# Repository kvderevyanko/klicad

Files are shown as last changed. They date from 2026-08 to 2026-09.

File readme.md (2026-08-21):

# Несущая плата ESP32 + E220, Rev.1

Текущая Rev.1 — **кандидат для предсерийной проверки**, а не производственный выпуск. Электрическая схема и трассировка завершены: 37 посадочных мест, 200 дорожек, 58 переходных отверстий, четыре медные зоны, два слоя, контур 145 × 90 мм; ERC, native DRC, соответствие схемы/платы и контракт платы проходят без ошибок и без неподключённых объектов.

## Действующая архитектура питания

\`BAT_PLUS → F1 → BAT_FUSED → J8.1 → внешний выключатель → J8.2 → BAT_SW → Q1 → BUCK_IN → TPS62133 → 5V_SYS\`.

\`D3 SMBJ10CA\` подключён между \`BAT_FUSED\` и GND. У Q1 \`DMP3130LQ-7\`: 1=\`Q1_GATE\`, 2=\`BUCK_IN\`, 3=\`BAT_SW\`.

\`5V_SYS → JP1 → VIN ESP32 DevKit\`. Обычный режим: выключатель включён, JP1 замкнут. Для сервисного USB с изоляцией: выключатель выключен, JP1 разомкнут при необходимости; JP1 не является автоматической изоляцией доменов.

\`5V_SYS → U4 TLV1117LV33 → AUX_3V3 → OLED\`. OLED питается только от \`AUX_3V3\`; \`DEVKIT_3V3\` не является питанием аксессуаров.

## Узлы и сборка

- J1/J2 — заводски устанавливаемые розетки ESP32; сам ESP32 DevKit устанавливает пользователь.
- J3 — заводски устанавливаемая розетка Samtec для одного пользовательского E220-400T22D или E220-900T22D; антенна обязана соответствовать диапазону модуля.
- J5 — заводски устанавливаемая розетка OLED; механическая совместимость конкретного OLED подтверждается на первом образце.
- J6 \`BUTTONS\` и J9 \`RGB OUT\` — пользовательские DNP-интерфейсы.
- D2, J7 и TP6…TP10 отсутствуют. TP1…TP5 — сохранённые металлизированные пробные отверстия без устанавливаемого компонента.

Электрические соединения завершены. Крепёж и разгрузка аккумуляторного кабеля сознательно отложены до корпуса/жгута или Rev.2. Генерация Gerber, сверловки, производственного BOM и CPL разрешается только отдельной задачей после предсерийного ревью.

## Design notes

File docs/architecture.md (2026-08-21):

# Архитектура Rev.1

## Питание

\`\`\`
BAT_PLUS -> F1 -> BAT_FUSED -> J8 / внешний выключатель -> BAT_SW
                                                       -> Q1 -> BUCK_IN
                                                       -> TPS62133 -> 5V_SYS
BAT_FUSED -> D3 SMBJ10CA -> GND
5V_SYS -> JP1 -> VIN ESP32 DevKit
5V_SYS -> U4 TLV1117LV33 -> AUX_3V3 -> OLED
\`\`\`

Q1 — P-MOS DMP3130LQ-7: 1=gate \`Q1_GATE\`, 2=source \`BUCK_IN\`, 3=drain \`BAT_SW\`. Предыдущее описание drain=\`BAT_FUSED\` относится к состоянию до вставки J8 и недействительно.

J8 — внешний механический выключатель, а не источник питания. Для обычной работы он включён и JP1 замкнут. Для USB-сервиса с требуемой изоляцией выключатель выключают и JP1 размыкают; JP1 не даёт автоматической изоляции всех GPIO.

## Модули и интерфейсы

- ESP32 DevKit устанавливается пользователем в заводские розетки J1/J2. Его USB-C должен быть доступен, а антенна обращена к свободной зоне запрета меди.
- E220 устанавливается пользователем в заводскую розетку J3. Сигналы M0/M1/AUX/RXD/TXD, питание и земля полностью подключены. SMA и антенна остаются доступными; антенна 400/900 МГц выбирается по варианту E220.
- OLED устанавливается пользователем в заводскую розетку J5: GND, AUX_3V3, SCL GPIO22, SDA GPIO21. Окончательная механика конкретного дисплея — проверка первого образца.
- J6 — DNP-интерфейс пяти пассивных кнопок: GND, GPIO13, GPIO14, GPIO18, GPIO19, GPIO23.
- J9 — DNP-интерфейс RGB OUT: 5V_SYS, WS2812_DATA_5V, GND; не более трёх внешних пикселей.

U3 SN74AHCT1G125DBVR преобразует GPIO4/\`WS2812_DATA_3V3\` в \`WS2812_DATA_5V\`. Его утверждённый TI DBV0005A footprint имеет верную распиновку: 1=OE/GND, 2=A, 3=GND, 4=Y, 5=VCC.

## Земля, возвраты и ограничения

Два связанных B.Cu-полигона GND вместе с локальной F.Cu-заливкой преобразователя образуют завершённую систему возврата. Шесть заземляющих выводов/EP U1 соединены с глобальной GND через два переходных отверстия; местный возврат E220 также соединён с глобальной землёй. OLED трассирован на F.Cu без фрагментации B.Cu GND.

Запретная область антенны ESP32 (X=104,7…142,7 мм, Y=52,0…90,0 мм) свободна от меди, дорожек, переходных отверстий и новых посадочных мест, кроме документированных границ розеток. Контур платы 145 × 90 мм, слоёв меди два.

## Статус

Все обязательные электрические трассы Rev.1 завершены. D2, J7 и TP6…TP10 отсутствуют; TP1…TP5 сохранены как пробные металлизированные отверстия. Крепёж платы и разгрузка аккумуляторного кабеля — ответственность корпуса/жгута в Rev.1 и отложены до Rev.2 или механической первой статьи.

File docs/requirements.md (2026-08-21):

# Требования к плате наземного приёмника ESP32 + E220

Назначение: документация для человека. Рабочий контекст агентов хранится отдельно в `docs/agent-context.md` на английском языке.

## Назначение устройства

Несущая плата должна объединять:

- съёмный 30-выводный ESP32 DevKit с ESP32-WROOM-32E;
- один съёмный модуль EBYTE E220-400T22D или E220-900T22D;
- съёмный OLED 0,96 дюйма на контроллере SSD1306;
- панель из пяти пассивных кнопок через разъём J6;
- внешний шлейф не более чем из трёх WS2812B-V5 через разъём `J_RGB`
  (схемное обозначение J9) и буфер SN74AHCT1G125;
- питание от внешнего защищённого двухэлементного литий-ионного аккумулятора 6,0…8,4 В.

Плата предназначена для изготовления и подключения к реальному оборудованию. Все критические параметры должны подтверждаться официальными документами изготовителей и проверками KiCad.

## Активная электрическая основа Rev.1

Все прежние варианты питания несущей платы через USB-C, TUSB320, TPD4S311, TLV704 и TPS259630 отменены. Они сохраняются только в журнале истории.

Действующая цепь:

`BAT_PLUS → F1 → BAT_FUSED → J8.1 → внешний механический выключатель → J8.2 → BAT_SW → Q1 → BUCK_IN → U1 TPS62133 → 5V_SYS`.

Ограничитель перенапряжения:

`BAT_FUSED → D3 SMBJ10CA → GND`.

Внешний аккумулятор обязан иметь собственную защитную плату BMS. На несущей плате нет зарядного устройства, средней точки аккумулятора и собственной функции BMS. Перед подключением USB-C съёмного DevKit к компьютеру аккумулятор требуется отключить либо выключить выход внешней BMS. Одновременное питание не заявлено безопасным.

## Выбранные силовые элементы

### Понижающий преобразователь

- U1: TI `TPS62133RGT`, фиксированный выход 5,0 В, допустимый рабочий вход 3…17 В, синхронный преобразователь до 3 А.
- L1: Coilcraft `XFL4020-222MEB`, 2,2 мкГн, максимальное сопротивление постоянному току 23,5 мОм.
- C1: Murata `GRM21BR61E106KA73`, 10 мкФ, 25 В, X5R, между `BUCK_IN` и GND.
- C2: Murata `GRM188R71C104KA01D`, 0,1 мкФ, 16 В, X7R, между AVIN и GND.
- C3: Murata `GRM21BR61A226ME44`, 22 мкФ, 10 В, X5R, между `5V_SYS` и GND.
- C4: Murata `GRM1885C1H332JA01D`, 3,3 нФ, 50 В, C0G, между SS/TR и GND.

Проверка при входе 6,0 В и выходном токе 1,5 А дала расчётное падение около 0,290 В по максимальным сопротивлениям верхнего ключа и L1. Это инженерная оценка, а не замена тепловым и нагрузочным испытаниям.

### Входная защита

- F1: Littelfuse `1812L200/16`, самовосстанавливающийся предохранитель, ток удержания 2,0 А, ток срабатывания 3,5 А, максимальное напряжение 16 В.
- J8: JST `B2B-XH-A`, два контакта, шаг 2,50 мм; паспортный ток XH 3 А AC/DC при AWG22, что выше требуемых 2 А.
- Q1: Diodes Inc. `DMP3130LQ-7`, P-канальный MOSFET, 30 В; официальные выводы 1=G, 2=S, 3=D. Соединения: D/3=`BAT_SW`, S/2=`BUCK_IN`, G/1=`Q1_GATE`.
- R1: 100 кОм от затвора к GND.
- R2: 1 МОм от `BUCK_IN` к затвору.
- D3: Littelfuse `SMBJ10CA`, двунаправленный TVS с рабочим напряжением 10 В, между `BAT_FUSED` и GND.

При правильной полярности расчётное VGS Q1 составляет примерно −5,45 В при 6,0 В и −7,64 В при 8,4 В, что ниже предела ±12 В. При обратной полярности внутренний диод закрыт и `BUCK_IN` не должен получать питание.

## Назначение выводов TPS62133

| Выводы | Назначение | Соединение |
| --- | --- | --- |
| 1, 2, 3 | SW | `BUCK_SW` → L1 |
| 4 | PG | не подключён |
| 5 | FB | GND для фиксированного выхода |
| 6 | AGND | местная земля и EP |
| 7 | FSW | `5V_SYS`, выбор режима высоким уровнем; не силовая ветвь |
| 8 | DEF | GND |
| 9 | SS/TR | C4 → GND |
| 10 | AVIN | `BUCK_IN`, местная развязка C2 |
| 11, 12 | PVIN | `BUCK_IN`, входная петля C1 |
| 13 | EN | `BUCK_IN` |
| 14 | VOS | отдельная измерительная связь с выходным узлом возле C3 |
| 15, 16 | PGND | местная земля и EP |
| EP | открытая площадка | GND и отвод тепла |

VOS запрещено вести как дополнительную силовую дорожку `5V_SYS`. FSW также является малоточной конфигурационной цепью.

## Расчёт потребления

Статус расчёта: `POWER BUDGET PASS`. Это проектный расчёт одновременно
разрешённой нагрузки, а не заявление о паспортном максимуме неизвестной
платы DevKit и не замена проверке образца.

| Нагрузка `5V_SYS` | Ток | Класс основания |
| --- | ---: | --- |
| ESP32 DevKit, вход VIN | 500.000 мА | **ПРОЕКТНОЕ ВЫДЕЛЕНИЕ**; не паспортный максимум неизвестной платы |
| E220-T22D при передаче 22 дБм | 110.000 мА | **ПАСПОРТНЫЙ МАКСИМУМ** EBYTE: максимальный мгновенный ток при указанном режиме |
| SN74AHCT1G125 | 1.510 мА | консервативная инженерная сумма 10 мкА `ICC` и 1,5 мА `ΔICC` из условий TI; не предел динамического тока |
| U4 / OLED `AUX_3V3` | 100.100 мА | **ПРОЕКТНОЕ ВЫДЕЛЕНИЕ**: 100.000 мА OLED плюс 0.100 мА по принятой конвенции учёта U4 |
| `J_RGB`, не более 3 × WS2812B-V5 | 109.800 мА | **ПРОЕКТНОЕ ВЫДЕЛЕНИЕ**: 3 × (36.000 мА RGB + 0.600 мА тока покоя) по WorldSemi |
| **Промежуточная сумма** | **821.410 мА** | расчёт одновременно выделенных нагрузок |
| **Инженерный запас 20 %** | **164.282 мА** | **ИНЖЕНЕРНЫЙ ЗАПАС** |
| **Итоговое выделение `5V_SYS`** | **985.692 мА** | расчёт: 821.410 мА + 164.282 мА |

`AUX_3V3` теперь питает только OLED/J5 с выделением 100.000 мА. J6 не имеет
вывода питания, J7 удалён. Для `TLV1117LV33DCYR` 100 мкА из TI `SBVS160C`, Rev. C —
максимальный ток покоя без нагрузки. Значение 100.100 мА остаётся проектной
конвенцией, а не паспортным пределом тока U4 под нагрузкой.

При выходе 5.0 В `Pout = 4.928460 W`. При принятом расчётном КПД 85 %
`Pin = 5.798188 W`. Расчётный ток батареи равен `0.966365 A` при 6.0 В,
`0.783539 A` при 7.4 В и `0.690261 A` при 8.4 В.

Для U1 непрерывный паспортный предел TPS62133 составляет 3.0 A. Итоговое
проектное выделение использует 32.8564 % этого предела и оставляет
2.014308 A. Минимальный порог ограничения тока 3.6 A (паспортное условие
`VIN=12 V`, `TA=25 °C`, статический предел) является только условием
квалификации запаса по ограничению тока: до него остаётся 2.614308 A; он не
подменяет непрерывный предел 3.0 A и не является гарантией для 6.0 В.

Проверка L1 без изменения компонента: Coilcraft `XFL4020-222MEB`
(`XFL4020-222ME_` в таблице изготовителя) имеет 2.2 мкГн, DCR максимум
23.50 мОм, `Isat` 3.1 A при падении индуктивности 10 % и `Irms` 6.0 A при
росте температуры 20 °C. При постоянной составляющей 0.985692 A расчётные
`I²R`-потери равны 0.022832 W; до `Isat` 3.1 A остаётся 2.114308 A. Это
расчёт только по постоянной составляющей: пиковый ток с учётом пульсаций и
реальные потери требуют проверки образца. Первичный источник Coilcraft:
https://www.coilcraft.com/getmedia/50632d43-da1b-4cdb-8ab4-3029cab51df3/xfl4020.pdf

Защита входа также имеет расчётный запас при этой нагрузке. F1
`1812L200/16` имеет `Ihold=2.0 A` при 20 °C и 1.29 A при 85 °C; при худшем
расчётном токе батареи 0.966365 A (6.0 В) остаётся 0.323635 A до
температурно сниженного `Ihold`. J4 рассчитан на 3 A. Q1 `DMP3130LQ-7`
при `VGS=-4.5 V` имеет непрерывный ток 2.6 A при 70 °C, что выше
расчётного тока батареи; температурную модель фактической платы всё равно
следует подтвердить. J8 — JST XH `B2B-XH-A`: паспортный ток 3 A
AC/DC при AWG22; до него при расчётных 0.966365 A остаётся 2.033635 A. Выбранный
жгут, контакт, сечение провода, обжатие и температура остаются предметом квалификации.

`POWER BUDGET PASS` относится только к этому стационарному проектному
выделению. **ПРОТОТИПНАЯ ВАЛИДАЦИЯ** обязательна для всплесков и запуска
DevKit, пускового/ёмкостного тока внешней RGB-цепочки, нагрева U4 при
100 мА OLED на фактической плате, пикового тока L1 и переходных процессов
TPS62133/F1/Q1. Эти испытания не заменяются расчётом.

## Модуль ESP32 DevKit

- Модуль съёмный, устанавливается в две розетки 1×15 с шагом 2,54 мм и межрядным расстоянием 25,40 мм.
- Используется подтверждённая пользователем распиновка конкретного 30-выводного варианта.
- Вход VIN получает `5V_SYS`; обе земли должны иметь качественное соединение с общей землёй.
- USB-C модуля должен оставаться доступным.
- Антенная часть должна находиться у края платы; под консервативной областью антенны запрещены медь, дорожки, переходные отверстия и посторонние элементы до появления более точного проверенного чертежа.

## E220

Разрешается установка одного E220-400T22D или E220-900T22D. Диапазон антенны выбирается под конкретный модуль; антенны 400 и 900 МГц не взаимозаменяемы.

Соединения:

- GPIO17/TX2 → RXD E220;
- GPIO16/RX2 ← TXD E220;
- GPIO25 → M0;
- GPIO26 → M1;
- GPIO27 ← AUX;
- `5V_SYS` → VCC;
- GND → GND.

M0 и M1 имеют подтяжки 10 кОм к земле. Возле разъёма E220 обязательны C5 10 мкФ и C6 100 нФ без длинного ответвления. SMA должен быть доступен с края платы.

## Панель кнопок

J6 — не универсальный разъём GPIO, а устанавливаемый пользователем
однорядный интерфейс 1×6 с шагом 2,54 мм (`DNP=YES`):

| Вывод | Цепь |
| --- | --- |
| 1 | GND |
| 2 | GPIO13 |
| 3 | GPIO14 |
| 4 | GPIO18 |
| 5 | GPIO19 |
| 6 | GPIO23 |

Разрешены только нормально разомкнутые пассивные кнопки, замыкающие выбранный
GPIO на J6.1/GND. В прошивке требуется включить подтяжки вверх и обрабатывать
нажатие как активный низкий уровень. Подавать на J6 внешнее напряжение,
питать от него устройства или использовать его как универсальный GPIO-разъём
запрещено. GPIO13/14/18/19/23 не являются загрузочными strapping-выводами
ESP32; GPIO13/14 также имеют функции JTAG, которые нельзя одновременно
использовать при подключённой панели кнопок. DISPLAY_AUX/J7 отсутствует;
GPIO33 на J1.9 намеренно не подключён.

## Дисплей OLED

J5 — съёмная розетка 1×4:

| Вывод | Цепь |
| --- | --- |
| 1 | GND |
| 2 | `AUX_3V3` |
| 3 | GPIO22 / SCL |
| 4 | GPIO21 / SDA |

Питание и подтяжки допускаются только к 3,3 В. J5 получает `AUX_3V3` от
U4; `DEVKIT_3V3` не предназначена для внешних аксессуаров. R10 и R11 по
4,7 кОм к `AUX_3V3` имеют состояние `DNP=YES` и не устанавливаются по
умолчанию, поскольку на готовом модуле уже могут быть подтяжки.

Из пользовательского чертежа известны: плата 26,000×26,000 мм, шаг разъёма 2,540 мм, расстояния между центрами крепёжных отверстий X=21,740 мм и Y=22,000 мм, координаты выводов по X от левого края 9,190/11,730/14,270/16,810 мм. Не подтверждены диаметр отверстий, координата ряда разъёма по Y и зазоры дисплея, шлейфа и вырезов. Электрическая розетка и трассировка завершены; окончательная механическая совместимость остаётся проверкой первого образца.

## WS2812 и буфер

U3 `SN74AHCT1G125DBVR` согласует GPIO4 с внешним 5-вольтовым входом данных.
Возле U3 обязателен местный конденсатор C7 100 нФ. Бортового D2 нет.
`J_RGB` (схемное обозначение J9) — устанавливаемый пользователем разъём 1×3
с шагом 2,54 мм (`DNP=YES`): 1=`5V_SYS`, 2=`WS2812_DATA_5V`, 3=GND.
Разрешено не более трёх WS2812B-V5 одновременно. Официальная типовая схема
WorldSemi не задаёт последовательный резистор DIN и не даёт его номинала,
поэтому такой резистор в Rev.1 не добавлен. Пользовательский шлейф, помехи,
пусковой ток и локальная развязка фактической RGB-цепочки проверяются на
образце. Подключать `J_RGB` при непитаемом DevKit или считать состояние RGB
во время сброса гарантированным запрещено.

## Требования к плате

- Два слоя.
- Предполагается наружная медь 1 унция/фут²; подтвердить у изготовителя.
- Предварительный контур 145×90 мм; уменьшение требует отдельной механической проверки.
- Сигнальные дорожки: предпочтительно 0,25 мм, допустимо 0,20 мм в тесных местах; зазор 0,20 мм; переходное отверстие 0,60/0,30 мм.
- Силовые цепи `BAT_PLUS`, `BAT_FUSED`, `BUCK_IN`, основная `5V_SYS`: предпочтительно 1,0 мм; местные обоснованные ветви `5V_SYS` — 0,8 мм.
- `BUCK_SW`: короткая верхняя дорожка без переходных отверстий и избыточной площади меди; фактически допустимо 0,70 мм при недостаточном зазоре для 0,80 мм.
- Нижний слой уже образует связанные области глобальной GND; локальная F.Cu-заливка U1 связана с ними двумя GND-переходами.
- Возвратные пути UART/I²C/GPIO не должны пересекать разрывы земли.
- Сохраняются только TP1…TP5 для `BAT_PLUS`, GND, `BUCK_IN`, `5V_SYS` и
  `5V_SYS`; это металлизированные пробные отверстия без компонента. Сигнальные TP6…TP10 отсутствуют.

## Испытания перед выпуском

- температура и регулирование TPS62133 при 6,0 В и полной нагрузке;
- переходный процесс при передаче E220 и активности ESP32;
- нагрев и срабатывание F1 с учётом температуры;
- температура Q1 и D3;
- работа внешней BMS и отсутствие обратного питания при соблюдении правила отключения аккумулятора;
- напряжение и температура U4 `AUX_3V3` при выделении 100 мА для OLED;
- пусковой и установившийся ток внешней RGB-цепочки из трёх пикселей через `J_RGB`;
- работа пяти активных низким уровнем кнопок J6 и отсутствие ложных срабатываний;
- сопряжение розеток с фактическими ESP32/E220/OLED;
- доступ USB-C, SMA и аккумуляторного жгута;
- возможности сборщика по тепловой площадке TPS62133 и выбранным площадкам компонентов.

## Основные источники

- [TI TPS62133](https://www.ti.com/lit/ds/symlink/tps62133.pdf)
- [Coilcraft XFL4020](https://www.coilcraft.com/getmedia/50632d43-da1e-4cdb-8ab4-3029cab51df3/xfl4020.pdf)
- [Littelfuse 1812L](https://www.littelfuse.com/~/media/electronics/datasheets/resettable_ptcs/littelfuse_ptc_1812l_datasheet.pdf.pdf)
- [Diodes DMP3130LQ](https://www.diodes.com/_files/datasheets/DMP3130LQ.pdf)
- [Littelfuse SMBJ10CA](https://www.littelfuse.com/products/overvoltage-protection/tvs-diodes/surface-mount/smbj/smbj10ca)
- [EBYTE E220-T22D](https://www.cdebyte.com/products/E220-900T22D)
- [Espressif ESP32-DevKitC V4](https://docs.espressif.com/projects/esp-dev-kits/en/latest/esp32/esp32-devkitc/user_guide.html)
- [Solomon Systech SSD1306](https://www.solomon-systech.com/en/product/ssd1306/)
- [WorldSemi WS2812B-V5](https://www.world-semi.co.kr/_files/ugd/89cd03_1023b0e9d135431aa1e6491bfc318112.pdf)
- [TI SN74AHCT1G125](https://www.ti.com/lit/ds/symlink/sn74ahct1g125.pdf)

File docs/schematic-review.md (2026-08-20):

# Проверка электрической схемы Rev.1

Назначение: русскоязычный отчёт для человека. Это не рабочий файл агентов.

## Область проверки

Проверена действующая схема `hardware/esp32-e220.kicad_sch` после перехода на защищённый аккумулятор 2S. Старые варианты входа USB-C/TUSB320/eFuse рассматриваются только как отменённая история.

Проверка охватывает:

- вход J4/F1/D3/Q1;
- TPS62133 и C1…C4/L1;
- питание и выводы ESP32 DevKit;
- питание и управление E220;
- OLED 3,3 В;
- панель кнопок J6;
- внешний `J_RGB`/AHCT;
- силовые контрольные точки TP1…TP5;
- соответствие обозначений и площадок платы.

## Результат электрической проверки

Подтверждённых блокирующих ошибок связности схемы не обнаружено. Изменение схемы для текущего локального препятствия TPS62133 не требуется.

### Вход аккумулятора

- J4.1=`BAT_PLUS`, J4.2=GND.
- F1 последовательно соединяет `BAT_PLUS` и `BAT_FUSED`.
- D3 включён между `BAT_FUSED` и GND как параллельный TVS.
- Q1 имеет 1/G=`Q1_GATE`, 2/S=`BUCK_IN`, 3/D=`BAT_FUSED`.
- R1 соединяет затвор с GND; R2 соединяет `BUCK_IN` с затвором.

Ориентация Q1 соответствует правильной предварительной зарядке через внутренний диод при нормальной полярности и блокировке при обратной.

### TPS62133

Сверено с TI TPS6213x Rev.F:

- SW: 1/2/3;
- PG: 4, не подключён;
- FB: 5, GND для фиксированного выхода;
- AGND: 6;
- FSW: 7, `5V_SYS` как высокий логический уровень;
- DEF: 8, GND;
- SS/TR: 9, C4 к GND;
- AVIN: 10, `BUCK_IN`;
- PVIN: 11/12, `BUCK_IN`;
- EN: 13, `BUCK_IN`;
- VOS: 14, `5V_SYS`;
- PGND: 15/16;
- EP: GND.

Одинаковое имя цепи `5V_SYS` не делает FSW и VOS силовыми выводами. FSW должен иметь малоточную конфигурационную связь, VOS — отдельную измерительную связь к C3. Это требование трассировки, а не исправление схемы.

### ESP32 и E220

Подтверждены:

- питание DevKit через VIN от `5V_SYS`;
- GPIO17/TX2 → RXD E220;
- GPIO16/RX2 ← TXD E220;
- GPIO25 → M0;
- GPIO26 → M1;
- GPIO27 ← AUX;
- местные подтяжки M0/M1 к земле;
- местная развязка E220 10 мкФ + 100 нФ.

J6 является только интерфейсом пяти нормально разомкнутых кнопок:
1=GND, 2=GPIO13, 3=GPIO14, 4=GPIO18, 5=GPIO19, 6=GPIO23. Внешнее
напряжение запрещено; нажатие активно низким уровнем при включённых
программных подтяжках вверх. GPIO13/14/18/19/23 не относятся к strapping-
выводам ESP32. DISPLAY_AUX/J7 удалён, J1.9/GPIO33 намеренно не подключён.

### OLED

J5 использует только 3,3 В:

- 1=GND;
- 2=`AUX_3V3`;
- 3=GPIO22/SCL;
- 4=GPIO21/SDA.

R10/R11 по 4,7 кОм отмечены `DNP=YES`. Их отсутствие по умолчанию корректно, поскольку готовый модуль может иметь собственные подтяжки.

### Внешний WS2812/AHCT

GPIO4 подключён ко входу U3 SN74AHCT1G125. Питание U3 и местная развязка
C7 предусмотрены. Выход U3 идёт на J9.2=`WS2812_DATA_5V`; функциональное
имя разъёма — `J_RGB`, J9.1=`5V_SYS`, J9.3=GND. Разрешено не более трёх
внешних WS2812B-V5. Бортовой D2 удалён. Последовательный резистор не добавлен,
поскольку официальный документ WorldSemi не задаёт ни требования, ни
проверяемого номинала для типовой цепи DIN.

TP6…TP10 удалены; сохраняются только TP1…TP5.

## ERC

Контролируемая генерация после упрощения читается KiCad 10.0.5 и проходит
ERC с 0 ошибками и 0 предупреждениями. Независимая электрическая проверка
этого change-set остаётся обязательной до физической синхронизации платы.

## Соответствие схемы и платы

Экспортированный netlist подтверждает новую электрическую схему и карты
выводов J6/J9. Активная плата является отклонённой частичной реализацией и
намеренно ещё не соответствует упрощённой схеме: физическое удаление D2 и
TP6…TP10, замена J6 и добавление J9 относятся к последующей проверяемой
синхронизации после независимого электрического и физического gate. Это
ожидаемый parity impact, а не разрешение менять плату в рамках этой проверки.

## Что проверка схемы не утверждает

Этот отчёт не утверждает:

- окончательную геометрию TPS62133;
- тепловое решение;
- глобальную плоскость земли;
- полную трассировку платы;
- фактический внешний RGB-шлейф, его помехоустойчивость и пусковой ток;
- окончательную механику OLED;
- серийную готовность платы.

Эти вопросы относятся к физической реализации, испытаниям и отдельному решению проверяющего.

## Основные источники

- [TI TPS62133](https://www.ti.com/lit/ds/symlink/tps62133.pdf)
- [Diodes DMP3130LQ](https://www.diodes.com/_files/datasheets/DMP3130LQ.pdf)
- [EBYTE E220-T22D](https://www.cdebyte.com/products/E220-900T22D)
- [Espressif ESP32-DevKitC](https://docs.espressif.com/projects/esp-dev-kits/en/latest/esp32/esp32-devkitc/user_guide.html)
- [Solomon Systech SSD1306](https://www.solomon-systech.com/en/product/ssd1306/)

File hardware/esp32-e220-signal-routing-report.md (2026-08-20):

# E220 signal routing attempt — 2026-08-20

Audience: `AGENT_FACING`. This report records a blocked physical-routing
attempt. It is neither a reviewer result nor a production release.

## Scope status

`SCOPE STATUS: BLOCKED`

No copper was added to `hardware/esp32-e220.kicad_pcb`. The active board is
byte-identical to the named pre-stage backup; no routing subsection was applied
to the active PCB and no review/production PDF was generated.

## Verified mapping and baseline

The active PCB and approved schematic agree exactly with the intended mapping:

| Net | E220 | DevKit | Pull / test point |
| --- | --- | --- | --- |
| `/E220_M0` | J3.1 | J1.8 | R8.1; TP6 |
| `/E220_M1` | J3.2 | J1.7 | R9.1; TP7 |
| `/E220_AUX` | J3.5 | J1.6 | TP8 |
| `/E220_RXD` | J3.3 | J2.7 | TP9 |
| `/E220_TXD` | J3.4 | J2.6 | TP10 |

R8.2 and R9.2 are `/GND`. Baseline (KiCad 10.0.5) was 81 segments, 17 vias,
2 zones, zero geometric DRC findings, 29 global unconnected items, and parity
PASS (33 schematic assembled references / 33 PCB footprints; no pad/net
mismatch). Exact backup:
`hardware/esp32-e220-pre-e220-signal-routing.kicad_pcb`, SHA-256
`d87c0ff900c9ce113c4c36b5a2785a65848077673e34804a8e9166cec2a6b76c`.

## Temporary-copy feasibility evidence

All feasibility boards are retained under
`hardware/evidence/e220-signal-routing-2026-08-20/`; the active PCB was never
used as the proof target.

| Temporary checkpoint | Native geometry findings | Global unconnected | Result |
| --- | ---: | ---: | --- |
| M0 / R8 (`feasibility-bcu-a-drc.json`) | 0 | 25 | clean on copy |
| M0 + re-planned M1 / R9 (`feasibility-m1-replan-drc.json`) | 0 | 21 | clean on copy |
| Add AUX (`feasibility-bcu-c-drc.json`) | 25 | 19 | failed; discarded copy only |

The initial F.Cu-only plan crossed protected existing `/5V_SYS` copper. The
M0/M1 temporary proof therefore used short 0.60/0.30-mm via bridges only at
unavoidable crossings, with long testpoint paths retained on F.Cu over the
bounded B.Cu GND reference. That allowed M0 and M1 individually and together,
but not the five-net set.

## Concrete physical blocker

The available two-layer corridor is not mutually routeable with the required
clearances and protected copper under the provided placement constraints:

* J3 exits are fenced by the `/5V_SYS` vertical branches at x=20.580 and
  x=23.275 mm; the central 5V distribution additionally blocks the corridor
  at x=80.000 mm and the J1/J2 access path at y=14.000 mm.
* M0’s only DRC-clean passage requires crossings/bridges that place its trunk,
  R8 branch, TP6 drop, and J1.8 entrance around x=27/79/100/104 mm. A
  re-planned M1 can cross that geometry only by additional local B.Cu bridges.
* Adding `/E220_AUX` at the prescribed J3.5/J1.6/TP8 endpoints has no remaining
  0.20-mm-clear F.Cu channel: native DRC reports short/clearance/crossing and
  hole-to-hole violations against the M0/M1 copper and the protected existing
  GND/5V objects. The complete machine record is
  `feasibility-bcu-c-drc.json`.

This is a physical congestion blocker, not a schematic discrepancy. Any next
attempt needs an explicitly authorized coupled replan (for example a defined
alternate testpoint/route corridor, additional controlled layer authority, or
an approved placement change). Do not apply the temporary-copy route to the
active board.

## Required handoff fields

`cli_exit_code=0` for each native temporary-copy DRC invocation.
`geometric_violations=25` at the failing AUX checkpoint;
`in_scope_unconnected=15` on the unchanged active board (M0=3, M1=3,
AUX=2, RXD=2, TXD=2, R8/R9 GND returns=3);
`out_of_scope_unconnected=14`;
`footprint_errors=0`; `zone_errors=0`.
Parity was PASS on the unmodified active board. Retained: all active-board
subsections. Deferred/failed: M0/M1/AUX/RXD/TXD active implementation and the
requested top/bottom review PDFs.

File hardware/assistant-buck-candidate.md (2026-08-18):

# TPS62133 separated-island placement candidate

Status: **PLACEMENT CANDIDATE ONLY — NOT REVIEWED — NOT FOR PRODUCTION**

## Purpose

The prior full-board and local routing attempts coupled the battery-protection geometry too tightly to the TPS62133 cell. The new candidate tests a different physical architecture without changing any electrical topology or component package:

* J4/F1/D3/Q1/R1/R2 remain the battery-input/protection block;
* U1/C1/C2/C3/C4/L1 move as a separate regulator island into free central board area;
* Q1 Source -> C1 is treated as an upstream low-impedance `BUCK_IN` feed, not as the local TPS62133 high-di/dt loop;
* package-size reduction is deferred until a current-package candidate is proven impossible with realistic local/common ground copper.

The active PCB is intentionally **not** overwritten. The candidate file is:

`hardware/esp32-e220-assistant-buck-candidate.kicad_pcb`

It is reproducibly generated by:

`python3 hardware/make_assistant_buck_candidate.py`

The helper removes all top-level segments, vias and zones from the output before moving the six buck-cell footprints. This prevents rejected experimental copper from becoming accidental evidence.

## Candidate placement

| Ref | XY mm | Rotation |
| --- | --- | --- |
| U1 | 70.000, 56.000 | 180 deg |
| C1 | 67.700, 59.225 | 0 deg |
| C2 | 66.000, 56.000 | 180 deg |
| C3 | 70.900, 59.225 | 180 deg |
| C4 | 67.000, 53.500 | 270 deg |
| L1 | 74.850, 56.525 | 90 deg |

The existing package courtyards have no positive-area overlap in the candidate according to the project-local text-geometry check. This is **not** a substitute for native KiCad DRC.

## Straight-line planning metrics

These are pad-centre distances only. They are useful for ranking the candidate but are not routed lengths and do not prove clearance.

| Connection | Approx. distance |
| --- | ---: |
| C1.1 `BUCK_IN` -> nearest U1 PVIN (11/12) | 3.12 mm |
| C1.2 GND -> nearest U1 PGND (15/16) | 2.39 mm |
| C2.1 `BUCK_IN` -> U1.10 AVIN | 1.89 mm |
| U1.9 SS/TR -> C4.1 | 1.90 mm |
| nearest U1 SW (1/2/3) -> L1.1 | 3.57 mm |
| L1.2 -> C3.1 `5V_SYS` | 3.12 mm |
| C3.2 GND -> nearest U1 PGND (15/16) | 1.86 mm |
| U1.14 VOS -> C3.1 `5V_SYS` | 2.82 mm |

The intent is deliberately different from the rejected legacy cell: C1 and C3 have their power pads exposed toward their respective feed/output corridors, while their GND pads sit toward the local PGND side. C2 and C4 are positioned so their signal/power pads have short direct corridors; their GND pads should be able to drop immediately into the common ground structure.

## Ground and thermal proof policy

Primary reference: Texas Instruments TPS6213x datasheet, SLVSAG7F Rev.F, section 11, especially the layout guidelines and recommended layout example.

The next retained `hardware/evidence/` feasibility proof must not repeat the earlier artificial constraint that every capacitor GND pad requires a long individual F.Cu route to EP. The intended two-layer proof is:

* compact local F.Cu GND copper around AGND/PGND/EP where geometry permits;
* direct AGND/PGND/EP common connection;
* immediate purposeful GND vias from local capacitor-return copper into a continuous B.Cu ground plane;
* no ground copper intruding into the SW high-dv/dt area;
* no filled/capped via-in-pad assumption;
* VOS kept as a separate short sense trace to C3 VOUT, not merged into a power-style `5V_SYS` route.

The planner must inspect actual zone fill and return paths. A ground zone is allowed for the temporary proof because the common ground plane is part of the intended electrical implementation; it must not be used to conceal an impossible route or a clearance problem.

## Required validation gate

This environment did not provide `kicad-cli` or the KiCad `pcbnew` Python module, so no claim of native DRC/ERC or routing feasibility is made here.

Before adopting this placement into `hardware/esp32-e220.kicad_pcb`:

1. Run the project schematic/PCB parity check on the candidate:
   `python3 hardware/check_schematic_pcb_sync.py --pcb hardware/esp32-e220-assistant-buck-candidate.kicad_pcb --output hardware/evidence/buck-and-5v-checkpoints-2026-08-18/assistant-buck-sync.json`.
2. Run native KiCad PCB DRC and classify out-of-scope unconnected items separately from geometry findings.
3. Invoke `pcb_routing_planner` on a retained `hardware/evidence/` copy and create real temporary copper for the bounded TPS62133 cell, including the local/common ground implementation and thermal-via concept.
4. Require a temporary proof with no real shorts/clearance/hole/courtyard errors and no mandatory in-scope unconnected pin.
5. Require function-aware checks for the C1 input loop, SW/L1, C3 output loop, VOS Kelvin sense, SS/TR/C4, FSW/FB/DEF/EN, AGND/PGND/EP and thermal path.
6. Invoke `pcb_reviewer` independently.
7. Only after `ROUTING PLAN READY` plus reviewer PASS may `pcb_layout_dfm` adopt the candidate into the active PCB and implement routing transactionally.

If this current-package candidate fails after a realistic ground-plane proof, then escalate to `PACKAGE SIZE REVIEW REQUIRED`; do not shrink components merely to preserve the old coordinates.

## Static validation performed in this review environment

The candidate was parsed as a KiCad S-expression after generation. The static checks found:

* 33 footprints in active PCB and 33 footprints in candidate;
* only U1/C1/C2/C3/C4/L1 footprint placement/orientation changed;
* no changes to footprint identity, value, pad number, pad net, pad size or pad shape;
* 0 top-level segments, 0 vias and 0 zones in the candidate;
* no positive-area overlap between the project footprint `F.CrtYd` bounding boxes.

These checks detect accidental text/generator drift but do not evaluate KiCad design rules, mask clearances, copper fill, electrical loop quality or manufacturability. Native KiCad and the project agents remain the acceptance gate.

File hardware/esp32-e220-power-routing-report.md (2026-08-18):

# TPS62133 buck-island implementation report

Audience: `AGENT_FACING`. Date: 2026-08-18. This report records only the
approved separated-island implementation transaction on
`hardware/esp32-e220.kicad_pcb`; it is not reviewer approval or a production
release.

## Scope status

`SCOPE STATUS: READY FOR REVIEW`

Implemented scope: the U1/C1/C2/C3/C4/L1 TPS62133 cell, the Q1.2
`BUCK_IN` feed to that cell, its bounded local/plane GND returns, and the
required local VOS, SS/TR, FSW, FB, DEF, and EN connections. The accepted
J4/F1/D3/Q1/R1/R2 placement and `BAT_PLUS`, `BAT_FUSED`, and `Q1_GATE`
routing were retained. No schematic, topology, footprint source, ESP32,
E220, OLED, WS2812, RF, or module routing was changed. External `5V_SYS`
loads remain intentionally unrouted.

## C2 AVIN direct-route rework — 2026-08-18

This authorized reviewer-feedback transaction replaced **only** the C2.1
`/BUCK_IN` detour and preserved C2.2's existing local F.Cu GND-zone return
and the `(64.550,56.000)` 0.60/0.30-mm return via. Named rework backup:
`hardware/esp32-e220-pre-c2-avin-direct-rework.kicad_pcb` (SHA-256
`4d4959b6c1d2f89f76ba6e627a77cba9804accc0d2a39833e6ecd5dc107a2bd7`).

Removed copper: five F.Cu `/BUCK_IN` detour segments totalling 4.325 mm,
from C2.1 through `(66.200,56.000)`, `(66.200,57.100)`,
`(67.400,57.100)`, `(67.400,58.300)`, and `(67.700,58.300)`. Added copper:
one direct 0.20-mm F.Cu segment C2.1 `(66.725,56.000)` -> U1.10 AVIN
`(68.600,55.750)`, actual length **1.892 mm**. No other track, via, zone,
footprint, or topology was changed.

Rework baseline and final native DRC are each 0 geometry errors, 3 expected
`silk_over_copper` warnings, and 42 global out-of-scope unconnected items.
Final `cli_exit_code=0`; sync `sync_exit_code=0`, parity PASS. The new direct
AVIN bypass route and C2 local GND return are complete; `in_scope_unconnected=0`.

## Transaction control and baseline

Named pre-transaction backup:
`hardware/esp32-e220-pre-buck-candidate-implementation.kicad_pcb`
(SHA-256 `e60453f0ca4e0cf341ebb99343542a251205042650930872a6159c432f98c4b1`).

Baseline was KiCad `10.0.5`, 59 track/via objects (3 vias), 0 zones, native
DRC 0 violations / 46 global unconnected items, and parity PASS. Obsolete
legacy buck copper was removed before placement. The clean removal checkpoint
was 0 violations / 66 global unconnected items. The placement checkpoint was
0 geometry errors, 3 pre-existing `silk_over_copper` warnings, 66 global
unconnected items, and parity PASS.

## Adopted placement and pad geometry

| Ref | Position mm | Rotation |
| --- | --- | ---: |
| U1 | 70.000, 56.000 | 180 deg |
| C1 | 67.700, 59.225 | 0 deg |
| C2 | 66.000, 56.000 | 180 deg |
| C3 | 70.900, 59.225 | 180 deg |
| C4 | 67.000, 53.500 | 270 deg |
| L1 | 74.850, 56.525 | 90 deg |

L1 physical copper gap between P1 and P2 is **2.370 mm** after reload. No
via is in a pad, and none is between U1 fine-pitch pads.

Relevant actual pad centres are U1 SW 1/2/3=(71.400,56.750)/(71.400,56.250)/
(71.400,55.750), PVIN 11/12=(68.600,56.250)/(68.600,56.750), AVIN 10=
(68.600,55.750), EN 13=(69.250,57.400), VOS 14=(69.750,57.400), SS/TR 9=
(68.600,55.250), FSW 7=(69.750,54.600), C1.1=(66.700,59.225), C2.1=
(66.725,56.000), C3.1=(71.900,59.225), C4.1=(67.000,52.775), L1.1=
(74.850,58.200), and L1.2=(74.850,54.850).

## Copper and return implementation

* `BUCK_IN`: Q1.2 (64.350,77.000) -> C1.1 feed is 19.293 mm F.Cu, 1.00-mm
  wide; the C1-to-PVIN/EN local branches use 0.60/0.40/0.25-mm F.Cu. C2.1
  -> U1.10 AVIN is the direct 1.892-mm, 0.20-mm F.Cu bypass path. Total
  `BUCK_IN` copper is 27.996 mm F.Cu.
* `BUCK_SW`: all F.Cu, no via and no zone. U1 SW pads join at 0.25 mm and
  run to L1.1 with 0.70-mm copper; total copper length 5.168 mm.
* Output: L1.2 edge (73.150,54.850) -> C3.1 is 0.60-mm F.Cu plus two
  0.60/0.30-mm vias, a 4.385-mm 0.80-mm B.Cu leg, and 0.60-mm F.Cu into
  C3.1. This is local to the cell; no external `5V_SYS` load is routed.
* VOS Kelvin path is separate from the output power leg: U1.14 -> C3.1,
  3.493 mm total, 0.20-mm F.Cu, ending only at the C3 output pad.
* SS/TR path U1.9 -> C4.1 is 4.075 mm, 0.20/0.25-mm F.Cu. C4.2 returns via
  the local F.Cu GND copper and its nearby return via.
* FSW uses 0.25-mm F.Cu/B.Cu configuration copper to the local output node;
  FB, DEF, AGND, PGND, and EP connect to the local F.Cu GND return structure.

Two GND zones were added and refilled with KiCad:

| Layer | Net | Boundary mm | Filled evidence |
| --- | --- | --- | --- |
| F.Cu | `/GND` | (64.0,52.0), (70.95,52.0), (70.95,60.75), (64.0,60.75) | 3 purposeful local filled contours / 458 points |
| B.Cu | `/GND` | (42.0,46.0), (103.0,46.0), (103.0,89.0), (42.0,89.0) | 1 continuous filled contour / 685 points |

The bounded B.Cu zone retains the ESP32 antenna, module, RF, and future
routing corridors outside that central rectangle. The F.Cu zone stops at
x=70.95 mm, clear of the SW copper to its right.

New GND thermal/return vias are all 0.60-mm diameter / 0.30-mm drill:

| XY mm | Purpose |
| --- | --- |
| 64.550, 56.000 | C2 / AVIN bypass return |
| 65.950, 54.225 | C4 SS/TR return |
| 68.700, 60.300 | C1 PVIN bypass return |
| 69.900, 60.300 | C3 output return |
| 59.500, 66.275 | retained R1 ground function into B.Cu return |
| 42.200, 70.500 | retained J4/D3 ground function into B.Cu return |

The three local `5V_SYS` transition vias are also 0.60/0.30 mm at
(69.750,53.750), (72.800,54.850), and (73.100,59.225). The two existing
`Q1_GATE` vias at (56.500,69.000) and (61.650,78.500), both 0.60/0.30 mm,
were retained unchanged.

## Native DRC and sync evidence

Each checkpoint was refilled and checked natively. Counts are global KiCad
unconnected items; the only warnings throughout are the three expected
placement-candidate `silk_over_copper` warnings.

| Checkpoint | Geometry ERROR | Silk WARNING | Global unconnected |
| --- | ---: | ---: | ---: |
| A `BUCK_IN` + C1/PVIN | 0 | 3 | 61 |
| B local GND | 0 | 3 | 49 |
| C C2/AVIN | 0 | 3 | 48 |
| D SW -> L1 | 0 | 3 | 45 |
| E L1 -> C3/output return | 0 | 3 | 44 |
| F VOS | 0 | 3 | 43 |
| G SS/TR + C4 | 0 | 3 | 43 |
| H FSW/FB/DEF/EN | 0 | 3 | 42 |
| I final zone refill | 0 | 3 | 42 |

Final command:

```sh
kicad-cli pcb drc --format json --severity-all --refill-zones --save-board \
  -o hardware/evidence/buck-and-5v-checkpoints-2026-08-18/buck-final-drc.json hardware/esp32-e220.kicad_pcb
```

`cli_exit_code=0`; `geometric_violations=0`; `footprint_errors=0`;
`zone_errors=0`; warnings are only 3 silkscreen items. The final sync command
was `python3 hardware/check_schematic_pcb_sync.py --pcb
hardware/esp32-e220.kicad_pcb --output hardware/evidence/buck-and-5v-checkpoints-2026-08-18/buck-final-sync.json` and returned
`sync_exit_code=0`, `status=PASS`, 33 assembled schematic references / 33 PCB
footprints, with 0 pad/net mismatches.

`in_scope_unconnected=0`: every mandatory U1/C1/C2/C3/C4/L1/Q1-cell
connection is complete. `out_of_scope_unconnected=42`: this includes the
intentional downstream `5V_SYS` airwire between L1.2 and C7.1, which is not
part of this authorized transaction, plus the remaining board routing.

## Generated review evidence

Non-production PDFs only:

* `hardware/esp32-e220-buck-implemented-top.pdf` — F.Cu, front references,
  vias, Q1 feed, and outline context.
* `hardware/esp32-e220-buck-implemented-bottom.pdf` — B.Cu fill, via field,
  and keepout/outline context.

Retained: battery protection, Q1 gate, all non-buck routing and module/RF
boundaries. Deferred: all external `5V_SYS` distribution, ESP32/E220/OLED/
WS2812 routing, production files, and independent PCB review.

---

# Post-C3 5V_SYS distribution implementation report

Audience: `AGENT_FACING`. Date: 2026-08-18. This is the controlled physical
implementation of the explicitly authorized downstream `5V_SYS` scope. It is
not an electrical change, reviewer approval, or production release.

## Scope status

`SCOPE STATUS: READY FOR REVIEW`

Implemented only: post-C3 `5V_SYS` distribution to J1.1 (ESP32 DevKit VIN),
J3.6 (E220 VCC) with C5/C6 local bypass, U3.5/C7.1, and the TP4/TP5 probe
branch. The C5/C6 and U3/C7 ground-return copper is an inseparable local
bypass-return implementation, not a change to topology. D2 remains
`PLACEMENT_CANDIDATE_NOT_RELEASED`; no D2 VCC, GND, or DIN copper was added.

Named byte-independent pre-transaction backup:
`hardware/esp32-e220-pre-5v-distribution.kicad_pcb`, SHA-256
`85cbf701b6930138f3a75eacf4809f240ae4b8ff0a55461fabbc1510bfbd5d77`.

## Baseline and routing contract

Baseline active board: `hardware/esp32-e220.kicad_pcb`, KiCad `10.0.5`, 55
tracks, 11 vias, and 2 GND zones. Native DRC had zero geometry, zone, and
footprint errors, three inherited `silk_over_copper` warnings, and 42 global
unconnected items. Electrical parity was PASS. Allowed endpoints were C3.1's
already-approved post-C3 local output node, J1.1, J3.6/C5.1/C6.1, U3.5/C7.1,
TP4.1, and TP5.1; GND work was limited to material bypass returns.

Retained without edit: all 66 baseline copper objects (55 tracks and 11
vias), both zone boundaries, U1/C1/C2/C3/C4/L1 placement and copper,
J4/F1/D3/Q1/R1/R2 placement and copper, `BAT_PLUS`, `BAT_FUSED`, and
`Q1_GATE`. A UUID comparison after final refill retained all 66/66 baseline
copper objects. U1/C1/C2/C3/C4/L1 and J4/F1/D3/Q1/R1/R2 positions and
rotations are byte-for-byte coordinate-equivalent to the backup.

The route begins only at the retained `/5V_SYS` output via at
`(73.100,59.225)` mm, which is already connected to C3.1. It never attaches
to `BUCK_SW`, U1.14 VOS, U1.7 FSW, or pre-C3 copper. VOS and FSW copper were
not changed.

## Implemented copper

| Function | Path endpoints mm | Layer / width | Physical length |
| --- | --- | --- | ---: |
| Output escape | retained post-C3 via `(73.100,59.225)` -> new trunk via `(80.000,64.000)` | B.Cu / 1.00 mm | 8.391 mm |
| Main F.Cu trunk | `(80.000,64.000)` -> `(80.000,54.725)` -> `(80.000,43.500)` | F.Cu / 1.00 mm | 20.500 mm |
| ESP32 VIN branch | `(80.000,43.500)` -> `(96.000,43.500)` -> `(96.000,14.000)` -> J1.1 `(111.000,14.000)` | F.Cu / 1.00 mm | 60.500 mm |
| E220 feed trunk | `(80.000,43.500)` -> `(20.580,43.500)` -> C6.1 `(20.580,49.750)` -> J3.6 `(20.580,53.500)` | F.Cu / 1.00 then 0.80 mm | 69.420 mm |
| E220 C5 branch | trunk tee `(23.275,43.500)` -> C5.1 `(23.275,48.000)` | F.Cu / 0.80 mm | 4.500 mm |
| U3/C7 branch | trunk tee `(80.000,54.725)` -> C7.1 `(85.500,54.725)` | F.Cu / 0.80 mm | 5.500 mm |
| U3 VCC local branch | C7.1 -> `(87.000,54.725)` -> `(87.000,51.900)` -> `(88.525,51.900)` -> U3.5 `(88.525,53.000)` | F.Cu / 0.50 mm | 6.950 mm |
| TP4/TP5 probe branch | `(80.000,64.000)` -> `(73.000,82.000)` -> common tee `(63.000,82.000)` with stubs to TP5.1 `(68.000,87.000)` and TP4.1 `(63.000,87.000)` | B.Cu / 0.80 mm | 19.313 mm common escape; 10.000 mm TP5 route, 20.000 mm TP4 route |

The 0.60/0.30-mm new `5V_SYS` layer-transition via at `(80.000,64.000)` is
the only added power via. The TP branch is a dead-end probe branch; neither
main ESP32 nor E220 load current traverses a test-point pad.

### Local bypass and return evidence

* C6.1 is directly 3.750 mm / 0.80-mm F.Cu from J3.6. Its GND pad C6.2
  `(22.030,49.750)` has a 1.250-mm / 0.50-mm F.Cu escape to a new
  0.60/0.30-mm via at `(22.030,51.000)`, then a 2.727-mm / 0.50-mm B.Cu
  return to J3.7 GND `(23.120,53.500)`.
* C5.1 has its independent 4.500-mm branch; C5.2 `(24.725,48.000)` has a
  3.000-mm / 0.50-mm F.Cu escape to a new 0.60/0.30-mm via at
  `(24.725,51.000)`, then a 2.971-mm / 0.50-mm B.Cu return to J3.7. C5 and
  C6 are therefore not daisy-chained through either capacitor.
* C7.2 `(85.500,53.275)` reaches a new 0.60/0.30-mm B.Cu-return via at
  `(85.500,51.900)` over 1.375 mm / 0.50-mm F.Cu. U3.1 and U3.3 GND have
  their own 0.60/0.30-mm return vias at `(87.200,56.500)` and
  `(91.000,55.000)`, with 1.724-mm and 1.050-mm / 0.50-mm F.Cu escapes.
  All three enter the retained continuous B.Cu GND fill.

Total added copper is 215.074 mm of `/5V_SYS` (167.370 mm F.Cu and
47.704 mm B.Cu) and 14.097 mm of `/GND` bypass return (8.399 mm F.Cu and
5.698 mm B.Cu), plus six new 0.60/0.30-mm vias: one `/5V_SYS`, five `/GND`.

## Boundaries, fills, and silkscreen

No new copper, via, or zone enters the ESP32 antenna reserve
`x=104.7..142.7, y=52.0..90.0` mm. The J1.1 entry is at y=14.000 mm and the
branch remains left of the module boundary until that direct pin entry. E220
work is limited to the upper socket VCC/bypass cluster at y=43.500..53.500
mm; no new copper is in the lower SMA/bottom-access region. No part was
moved.

Both existing GND zones were refilled without boundary edits: F.Cu remains
three filled contours / 421 points, while the B.Cu `(42,46)..(103,89)` zone
remains one continuous filled contour / 751 points. It is not extended into
the ESP32 antenna or E220 SMA access regions.

After the electrical scope passed, only reference text was moved: U1 F.Silk
reference `(70.000,58.850)` -> `(61.500,61.500)` mm and L1 F.Silk reference
`(72.100,56.525)` -> `(78.000,51.000)` mm. This cleared all three inherited
silk warnings without moving parts or copper.

## Checkpoints and validation

| Checkpoint | Scope | Geometry / zone / footprint errors | Silk warnings | Global unconnected |
| --- | --- | ---: | ---: | ---: |
| A | C3 output escape, trunk, C7.1 terminus | 0 / 0 / 0 | 3 | 41 |
| B | ESP32 VIN | 0 / 0 / 0 | 3 | 40 |
| C | E220 VCC, C5/C6, bypass returns | 0 / 0 / 0 | 3 | 35 |
| D | U3/C7 VCC and returns | 0 / 0 / 0 | 3 | 31 |
| E | TP4/TP5 branch | 0 / 0 / 0 | 3 | 29 |
| Final after reference-text move | full scope | 0 / 0 / 0 | 0 | 29 |

The first D attempt created two local GND/5V shorts at U3.1; that transaction
alone was removed, baseline C was proven, and the lower-left U3.1 escape was
rerouted to `(87.200,56.500)`. A later geometry audit removed one same-net
duplicate B.Cu TP branch segment. Neither failed attempt remains in the
active PCB.

Final native command:

```sh
kicad-cli pcb drc --format json --severity-all --refill-zones --save-board \
  -o hardware/evidence/buck-and-5v-checkpoints-2026-08-18/5v-final-drc.json hardware/esp32-e220.kicad_pcb
```

`cli_exit_code=0`; `geometric_violations=0`; `zone_errors=0`;
`footprint_errors=0`; `in_scope_unconnected=0`; final silk warnings=0.
The checker command `python3 hardware/check_schematic_pcb_sync.py --pcb
hardware/esp32-e220.kicad_pcb --output hardware/evidence/buck-and-5v-checkpoints-2026-08-18/5v-final-sync.json` returned
`sync_exit_code=0`, parity PASS, 33 assembled schematic references / 33 PCB
footprints, and zero pad/net mismatches.

The exact sole remaining `/5V_SYS` airwire is D2.1 `(94.050,52.400)` to the
U3-side F.Cu `/5V_SYS` segment ending at `(87.000,51.900)`. It is deferred
solely because D2 is not released. There are no other `/5V_SYS` airwires.

The exact 29 final global airwires are that D2.1 item plus 28 out-of-scope
items: R8.2-GND to B.Cu GND track; R9.2-GND to R8.2-GND; F.Cu GND track to
R9.2-GND; F.Cu GND zone to J5.1; F.Cu GND zone-to-zone; D2.3-GND to GND via;
D2.3-GND to J1.2; J2.2-GND to J1.2; U3.2 to J2.5; U3.4 to D2.4; J3.1 to
R8.1; TP6 to R8.1; TP6 to J1.8; J3.2 to R9.1; TP7 to R9.1; TP7 to J1.7;
J3.3 to TP9; TP9 to J2.7; J3.4 to TP10; TP10 to J2.6; J3.5 to TP8; TP8 to
J1.6; TP1 to BAT_PLUS track; R2.1 to BUCK_IN track; BUCK_IN track to TP3;
J5.2 to J2.1; J5.4 to J2.11; and J5.3 to J2.14.

## Non-production evidence

* `hardware/esp32-e220-5v-top.pdf` — F.Cu distribution, reference text, and
  outline context.
* `hardware/esp32-e220-5v-bottom.pdf` — B.Cu GND fill, return vias, TP
  branch, and outline context.

Retained: the approved buck cell and input protection; all previous copper;
ESP32 USB/module-removal/antenna boundary; E220 socket/SMA/RF boundary; OLED
uncertainty; and D2 release hold. Deferred: D2 and all non-authorized signal,
OLED, UART, GPIO, and full-board routing. No production outputs were created.

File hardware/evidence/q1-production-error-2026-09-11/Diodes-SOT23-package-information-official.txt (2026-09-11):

                                                                                                                                             SOT23
                                                                                                                 PACKAGE INFORMATION

 Mechanical Data                                                                      Package View
         Surface Mount Package
         Weight: 0.008/9 grams (approximately)
         Case Material – Molded Plastic,
          UL Flammability Rating 94V-0
         Terminals: Finish – Matte Tin Plated Leads, Solderable
          per MIL-STD-202, Method 208
                                                                                        Top View

Package Outline Dimensions

                                                                              SOT23

                                                                     All 7°
                                   H
                                                                                 GAUGE PLANE
                                                                                                                                 SOT23
                                                                                     0.25                             Dim      Min   Max    Typ
                                                        J                                                              A      0.37   0.51   0.40
         K1   K
                                                                                                                       B      1.20   1.40   1.30
                                                                                                                       C      2.30   2.50   2.40
                                                                                           a
                                                                                                                       D      0.89   1.03 0.915
                                    A                   M
                                                                                                                       F      0.45   0.60 0.535
                                                                 L                             L1                      G      1.78   2.05   1.83
                                                                                                                       H      2.80   3.00   2.90
                                                                                                                        J     0.013 0.10    0.05
                                                                                                                       K      0.890 1.00 0.975
          C       B                                                                                                   K1      0.903 1.10 1.025
                                                                                                                       L      0.45   0.61   0.55
                                                                                                                       L1     0.25   0.55   0.40
                                                                                                                       M      0.085 0.150 0.110
                                        D                                                                               a       0°    8°     --
                                                                                                                         All Dimensions in mm
                         F          G

Suggested Pad Layout
                                                                              SOT23

                                         Y

                                                                                                                   Dimensions       Value (in mm)
                             Y1                                          C                                             C                 2.0
                                                                                                                       X                 0.8
                                                                                                                       X1               1.35
                                                                                                                       Y                 0.9
                                                                                                                       Y1                2.9

                                        X                X1

      Note:           The suggested land pattern dimensions have been provided for reference only, as actual pad layouts may vary depending on application.
                      These dimensions may be modified based on user equipment capability or fabrication criteria. A more robust pattern may be desired for
                      wave soldering and is calculated by adding 0.2 mm to the ‘Z’ dimension. For further information, please reference document IPC-7351A,
                      Naming Convention for Standard SMT Land Patterns, and for International grid details, please see document IEC, Publication 97.

      Note:           For high voltage applications, the appropriate industry sector guidelines should be considered with regards to creepage and clearance
                      distances between device Terminals and PCB tracking.

 SOT23 Package Information                                                 1 of 5                                                              January 2017
 Rev. 2017-01-30                                                       www.diodes.com                                                      © Diodes Incorporated

                                                                                                                                            SOT23

Minimum Packing Quantity

                                Quantity                 Tape Width          Part Number Suffix
        7” Reel                   3,000                     8mm                      -7, TA
        7” Reel                      500                    8mm                        TD
        13” Reel                 10,000                     8mm                      -13, TC
Note:    Package quantities given are for minimum packaging quantity only, not minimum order quantity. For minimum order quantity, please contact Sales
         Department.
Note:    No mixed date codes or partial quantity (less than minimum packaging quantity) per packaging is allowed.
Note:    In no case shall there be two or more consecutive components missing from any reel for any reason.

Device Tape Orientation

           Tape Width                Part Number Suffix                                               Tape Orientation

                                              TA
                                              TC
                                              TD
              8mm
                                               -7
                                              -13

                                                                                      Direction of feed
Note:    For part marking, refer to product datasheet.
Note:    Tape and package drawings are not to scale and are shown for device tape orientation only.

Embossed Carrier Tape Specifications

 Tape Width (W)            Dimension                Value (mm)           Dimension              Value (mm)             Dimension              Value (mm)

                                B1                   4.5 max.                  F                  3.5±0.05                  P2                 2.0±0.05
                                D                1.5+0.10 -0.0                 K                  2.4 max.                   t                 0.40 max.
                                D1                   0.35 min.                 P                  4.0±0.10                  W                    8±0.30
        8mm
                                E                   1.75±0.10                 P0                  4.0±0.10
                                               Determined by component size. The clearance between the component and the cavity must comply
                            A0 B0 K0           to the rotational and lateral movement requirement provided in figures in the "Maximum Component
                                               Movement in Tape Pocket” section.

 SOT23 Package Information                                                2 of 5                                                             January 2017
 Rev. 2017-01-30                                                      www.diodes.com                                                     © Diodes Incorporated

                                               SOT23

SOT23 Package Information       3 of 5           January 2017
Rev. 2017-01-30             www.diodes.com   © Diodes Incorporated

                                                    SOT23

Maximum Component Movement in Tape Pocket

 SOT23 Package Information           4 of 5           January 2017
 Rev. 2017-01-30                 www.diodes.com   © Diodes Incorporated

                                                                                                                                           SOT23

Surface Mount Reel Specifications

                                     A               B Max                 C               D Max             N Min                G                T Max
 Tape Width    Reel Size
                                   (mm)              (mm)                (mm)              (mm)              (mm)               (mm)               (mm)

                   7”             178 2           2.0 +0.5 -0       13 +0.5 -0.2        20.5 0.2            55 5         8.4 +1.5 -0.0           14.4
    8mm
                  13”             330 2           2.0 +0.5 -0       13 +0.5 -0.2        20.5 0.2           100 2         8.4 +1.5 -0.0           14.4

Tape Leader and Trailer Specifications

      Note:      There shall be a leader of at least 230mm which may consist of carrier tape and/or cover tape or a start tape followed by at least 160mm of
                 empty carrier tape sealed with cover tape.

      Note:      There shall be a trailer of at least 160mm of empty carrier tape sealed with cover tape. The entire carrier tape must release from the reel
                 hub as the last portion of the tape unwinds from the reel without damage to the carrier tape and the remaining components in the cavities.

 SOT23 Package Information                                           5 of 5                                                                 January 2017
 Rev. 2017-01-30                                                 www.diodes.com                                                         © Diodes Incorporated

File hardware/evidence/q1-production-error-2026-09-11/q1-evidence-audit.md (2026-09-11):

# Q1 production-error evidence audit

Scope: read-only audit of the controlled Rev.1 sources and the released Rev.1
fabrication package. No design source was modified.

## Superseded Q1 geometry conclusion

This initial audit correctly established the Q1 MPN, SOT23 package, pin map,
and released-Gerber identity, but its first reading of the Diodes `X1` drawing
dimension was wrong: it treated `X1=1.35 mm` as a lower-pad centre coordinate.
The drawing shows it is a centreline-to-outer-land-edge distance. The
independent physical-plan and implementation reviewers resolved this using the
same primary DS38728 drawing: pads 1/2 must be centred at `-0.950/+0.950 mm`
(`1.35 - 0.80/2`), not `-1.350/+1.350 mm`. The controlled board and the new
production package now contain the corrected geometry. The initial Q1 geometry
rows/conclusion below are retained as historical audit evidence only; the
authoritative Q1 conclusion is in
`q1-footprint-correction-implementation-gate-review.md`.

## Q1 — decisive evidence

| Item | Controlled/released implementation | Primary Diodes evidence | Result |
|---|---|---|---|
| MPN/package | `DMP3130LQ-7`; `Diodes_DMP3130LQ-7_SOT23` | DS38728 rev. 1-2, pp. 1 and 5: `DMP3130LQ-7`, case `SOT23` | MATCH |
| Symbol | `Project:DMP3130LQ_7`: 1=`G`, 2=`S`, 3=`D` | DS38728 p. 1 top view: 1=`G`, 2=`S`, 3=`D` | MATCH |
| nets | schematic/PCB: 1=`Q1_GATE`, 2=`BUCK_IN`, 3=`BAT_SW` | physical pin functions above | MATCH |
| copper | pads 1/2/3 at (-1.35,+1.00)/(+1.35,+1.00)/(0,-1.00) mm; each 0.80 x 0.90 mm | DS38728 p. 5 suggested SOT23 layout: X=0.80, Y=0.90, X1=1.35, Y1=2.90 mm | MATCH |
| courtyard | [-2.05,+2.05] x [-2.00,+2.00] mm = 4.10 x 4.00 mm | manufacturer does not prescribe a courtyard | EXPECTED REPRESENTATION DIFFERENCE |
| released Gerber | F.Cu aperture D30=`0.800000 x 0.900000`; Q1 centers (61.65,77.00), (64.35,77.00), (63.00,75.00) mm | same as above | MATCH |

The active PCB SHA-256 is `dd4d77d521adc1fd744d10b6e05f4a27169e30d988f70a3b9e50236608fda0e4`, exactly the source hash in the released Rev.1 manifest. Therefore the existing fabrication package contains the same Q1 land pattern, not an older/smaller variant.

Conclusion: the reported claim that the released Q1 footprint is substantially smaller than the official SOT23 land pattern is not reproducible from the controlled KiCad source or released Gerbers. Replacing this footprint would be an unsupported regression. Obtain from PCBWAVE the inspected board/order identity, component reel label/MPN, high-resolution top/bottom photos with scale, and their measured pad-to-pad/pad dimensions; compare against the coordinates above before any mutation.

## Whole-board package/pin-risk sweep

| References / exact MPN | Package/pin evidence checked | Result |
|---|---|---|
| U1 `TPS62133RGT` | TI datasheet: RGT 16-pin 3x3 VQFN with exposed pad. Board has pads 1..16+EP, project footprint lands 0.60x0.24 and EP 1.68x1.68; schematic/PCB pin numbers agree. | MATCH |
| U3 `SN74AHCT1G125DBVR` | TI: DBV SOT-23-5. Board has pads 1..5, 0.60x1.10 at official DBV row geometry; function map 1=OE, 2=A, 3=GND, 4=Y, 5=VCC agrees. | MATCH |
| U4 `TLV1117LV33DCYR` | TI: DCY SOT-223, 4 leads; 1=GND, 2+tab=OUT, 3=IN. Board uses `SOT-223-3_TabPin2` (pad 2 duplicated for tab) and schematic nets agree. | MATCH |
| D3 `SMBJ10CA` | Local audited footprint: DO-214AA/SMB, pads 1/2. Device is bidirectional; no polarity/pin inversion risk identified. Its 2.50x2.30 land is project IPC nominal, not an available manufacturer drawing in this audit. | INCONCLUSIVE |
| F1 `1812L200/16` | Local footprint 4532/1812, pads 1/2; project IPC nominal land pattern. | INCONCLUSIVE |
| L1 `XFL4020-222MEB` | Local footprint is two pads, 0.98x3.40 on 3.35 centers and explicitly states manufacturer pattern; source URL currently returns HTTP 404, so current primary confirmation was unavailable. | STALE DATA |
| J4,J8 `B2B-XH-A` | Official JST eXH PDF confirms 2.50-mm pitch and nominal 1.0-mm two-circuit drill. Board pads 1/2 use 2.50-mm pitch and 1.00-mm drill. | MATCH |
| J1,J2 `SSW-115-02-G-S`; J3 `SSW-107-02-G-S`; J5 `SSW-104-02-G-S` | Board pads are sequential and 2.54-mm pitch, 1.04-mm drills; local library identifies the Samtec SSW layout. Current primary Samtec drawing was not retrieved in this audit. | INCONCLUSIVE |
| C1/C3/C9/C10 Murata GRM21; C2/C4/C5/C6/C7/C8 Murata GRM188; R3/R4 Yageo RC0603 | Part-number case-family and named footprints agree: GRM21=2012/0805, GRM188/RC0603=1608/0603; two terminal pads only. Current manufacturer drawings were not retrieved. | INCONCLUSIVE |
| R1/R2/R8/R9 | Explicit approved-generic 0603/1608, two-pad footprints. | EXPECTED REPRESENTATION DIFFERENCE |
| JP1 `TSW-102-07-G-S` | Two sequential 2.54-mm PTH pads. Mating shunt is separately supplied/no PCB footprint. | INCONCLUSIVE |
| J6/J9; TP1..TP5; H1..H3; R10/R11; ESP32/E220/OLED | Respectively DNP_USER, plated test holes, MECHANICAL_ONLY, NO_FOOTPRINT, USER_INSTALLED. Excluded from PCBA component-placement MPN risk. | EXPECTED REPRESENTATION DIFFERENCE |

### All PCBA-populated references: MPN → package → footprint → pads

`Confirmed` means the manufacturer PDF was retrieved and the mechanical/pin
claim was compared. `Not verified` means no primary drawing for that exact MPN
was retrieved; it is not evidence of an assembly fault.

| Ref(s) | MPN | datasheet package | actual footprint | physical pad numbering | status |
|---|---|---|---|---|---|
| C1 | GRM21BR61E106KA73 | 2012/0805 family (not verified) | `Murata_GRM21_2012Metric` | 1,2 | Not verified |
| C2,C6,C7 | GRM188R71C104KA01D | 1608/0603 family (not verified) | `Murata_GRM188_1608Metric` | 1,2 | Not verified |
| C3 | GRM21BR61A226ME44 | 2012/0805 family (not verified) | `Murata_GRM21_2012Metric` | 1,2 | Not verified |
| C4 | GRM1885C1H332JA01D | 1608/0603 family (not verified) | `Murata_GRM188_1608Metric` | 1,2 | Not verified |
| C5 | GRM188R61A106MAAL | 1608/0603 family (not verified) | `Murata_GRM188_1608Metric` | 1,2 | Not verified |
| C8 | GRM188R71C104KA01D | 1608/0603 family (not verified) | `Carrier:Murata_GRM188_1608Metric` | 1,2 | Not verified |
| C9,C10 | GRM21BR61E106KA73 | 2012/0805 family (not verified) | `Carrier:Murata_GRM21_2012Metric` | 1,2 | Not verified |
| D3 | SMBJ10CA | DO-214AA / SMB (not verified) | `Littelfuse_SMBJ10CA_DO214AA` | 1,2 | Not verified; bidirectional device |
| F1 | 1812L200/16 | 4532/1812 (not verified) | `Littelfuse_1812L200_16_4532Metric` | 1,2 | Not verified |
| J1,J2 | SSW-115-02-G-S | 1x15, 2.54-mm SSW socket (not verified) | `Samtec_SSW_1x15_P2.54mm_THT` | 1..15 sequential | Not verified |
| J3 | SSW-107-02-G-S | 1x7, 2.54-mm SSW socket (not verified) | `E220_T22D_Socket_400_900` | 1..7 sequential | Not verified; project carrier pattern |
| J4,J8 | B2B-XH-A | XH, 2 circuits, 2.50-mm pitch, 1.0-mm hole | `JST_B2B-XH-A_1x02_P2.50mm_THT` | 1,2 | Confirmed |
| J5 | SSW-104-02-G-S | 1x4, 2.54-mm SSW socket (not verified) | `Samtec_SSW_1x04_P2.54mm_THT` | 1..4 sequential | Not verified |
| JP1 | TSW-102-07-G-S | 1x2, 2.54-mm header (not verified) | `PinHeader_1x02_P2.54mm_Vertical` | 1,2 | Not verified |
| L1 | XFL4020-222MEB | source primary URL is stale (HTTP 404) | `Coilcraft_XFL4020-222MEB` | 1,2 | Suspicious source provenance only; no geometry mismatch established |
| Q1 | DMP3130LQ-7 | SOT23 | `Diodes_DMP3130LQ-7_SOT23` | 1=G, 2=S, 3=D | Confirmed |
| R1 | approved generic 100 kOhm | 1608/0603 specified in metadata | `Resistor_0603_1608Metric` | 1,2 | Confirmed metadata requirement |
| R2 | approved generic 1 MOhm | 1608/0603 specified in metadata | `Resistor_0603_1608Metric` | 1,2 | Confirmed metadata requirement |
| R3 | RC0603FR-0710KL | 1608/0603 family (not verified) | `Carrier:Resistor_0603_1608Metric` | 1,2 | Not verified |
| R4 | RC0603FR-073K3L | 1608/0603 family (not verified) | `Carrier:Resistor_0603_1608Metric` | 1,2 | Not verified |
| R8,R9 | approved generic 10 kOhm | 1608/0603 specified in metadata | `Resistor_0603_1608Metric` | 1,2 | Confirmed metadata requirement |
| U1 | TPS62133RGT | RGT, VQFN-16, 3x3, EP | `TI_TPS62133RGT_RGT0016C` | 1..16, EP | Confirmed |
| U3 | SN74AHCT1G125DBVR | DBV, SOT-23-5 | `TI_SN74AHCT1G125DBVR_SOT23-5` | 1..5 | Confirmed |
| U4 | TLV1117LV33DCYR | DCY, SOT-223, 4 leads | `SOT-223-3_TabPin2` | 1, 2, tab=2, 3 | Confirmed |

Package geometry and schematic electrical correctness are separate tests. The
table audits package/footprint/pad identity. For the three ICs and Q1,
schematic pin number → PCB pad → manufacturer physical pin was also checked;
all are MATCH. For the passive two-terminal items, polarity is either absent
or (D3) explicitly bidirectional. Connector circuit-to-system assignments
remain a schematic/interface review concern, not a package-numbering mismatch
found by this audit.

## Generator provenance hazard

`hardware/generate_stage8_placement.py:255` assigns `Q1.3` to `BAT_FUSED`, while the active schematic, active PCB, generator `generate_esp32_e220.py`, and `docs/agent-context.md` assign it to `BAT_SW`. This is `STALE DATA`; do not regenerate the active board from that script without an electrical-owner correction and gate.

## Sources read

- `hardware/esp32-e220.kicad_sch` (Q1 symbol/instance and nets)
- `hardware/esp32-e220.kicad_sym` (Q1 symbol pin names/numbers)
- `hardware/esp32-e220.kicad_pcb` (embedded Q1 footprint/pads/nets)
- `hardware/esp32-e220.pretty/Diodes_DMP3130LQ-7_SOT23.kicad_mod`
- `hardware/releases/rev1/fabrication/esp32-e220-F_Cu.gtl`, `.../F_Mask.gts`, and release manifest
- Diodes DS38728: `DMP3130LQ-Diodes-DS38728.pdf`, retrieved from `https://www.diodes.com/assets/Datasheets/DMP3130LQ.pdf`
- TI primary PDFs retained here: `tps62133.pdf`, `sn74ahct1g125.pdf`, `tlv1117lv.pdf`; JST primary `eXH.pdf`.

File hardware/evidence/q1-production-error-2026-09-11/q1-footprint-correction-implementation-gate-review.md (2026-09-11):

# Independent implementation gate — Q1 footprint correction

## Scope and checkpoint

Read-only review of the active implementation against
`esp32-e220-q1-prechange-reference.kicad_pcb` and the retained primary Diodes
evidence. The named checkpoint and implementation backup have SHA-256
`dd4d77d521adc1fd744d10b6e05f4a27169e30d988f70a3b9e50236608fda0e4`.
No controlled source was modified by this reviewer.

## Findings

- **NOTE — implemented land pattern:** DS38728 p. 5 defines `X1=1.35 mm` to
  the lower-land outer edge. With `X=0.80 mm`, the active pad centres are now
  the required `(-0.950,+1.000)` / `(+0.950,+1.000)` mm. Pad 3 remains
  `(0,-1.000)` mm; all pads remain `0.80 x 0.90 mm`.
- **NOTE — pin-map retention:** active schematic/board parity confirms
  pin/pad 1=`Q1_GATE`/Diodes G, 2=`BUCK_IN`/Diodes S, and 3=`BAT_SW`/Diodes D.
  Q1 origin, rotation, pad numbering, and pad 3 are unchanged.
- **NOTE — bounded physical work:** only the approved F.Fab/F.CrtYd graphics
  and three F.Cu segment starts changed. The gate's delta checker passes,
  including equality of all other board semantics and byte identity between
  the local footprint and `generate_stage7_footprints.py` output. No via,
  zone, rule-area, keepout, component origin, width, layer, or downstream
  endpoint changed.
- **NOTE — verified package representation:** the F.Fab body is `1.30 x 2.90`
  mm (Diodes nominal `B x H`) and the project courtyard is `3.20 x 3.40` mm;
  the latter is a conservative project rule, not a manufacturer land
  dimension. The retained pad-1 silkscreen marker remains clear of the pad-3
  mask opening.
- **NOTE — machine gates independently rerun:** Q1 implementation delta PASS;
  schematic/PCB parity PASS; production metadata PASS; ERC has 0 errors and
  0 warnings. Native DRC has 0 unconnected pads and 0 footprint/geometric
  errors.
- **NOTE — inherited warning baseline:** native DRC still reports exactly two
  pre-existing `lib_footprint_mismatch` warnings, JP1 and U4, with no Q1
  warning and no pre/post category/count delta. `check_board_contract.py`
  therefore returns overall FAIL solely because it promotes those warnings;
  every affected contract subsection, including protected checkpoint and
  parity, is PASS.

`CONTEXT PROVENANCE CONFLICT`: `docs/agent-context.md` states zero native DRC
violations, while the retained pre-change and independently rerun post-change
DRC each show the two inherited JP1/U4 library-mismatch warnings. They are
outside this scope, unchanged, and unsuppressed.

SCOPE VERDICT: Q1 FOOTPRINT CORRECTION IMPLEMENTATION PASS

REVIEW PASS

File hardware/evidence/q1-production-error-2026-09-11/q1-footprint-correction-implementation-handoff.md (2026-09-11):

# Q1 footprint correction: physical implementation handoff

## SCOPE STATUS

`Q1 FOOTPRINT CORRECTION IMPLEMENTED — IMPLEMENTATION REVIEW GATE REQUIRED`

The approved constrained physical transaction is complete. No Gerber, drill,
placement, BOM, or production-release package was generated.

## Controlled transaction

- Named checkpoint and implementation backup:
  `esp32-e220-q1-prechange-reference.kicad_pcb` and
  `esp32-e220-q1-implementation-backup.kicad_pcb`, both pre-change SHA-256
  `dd4d77d521adc1fd744d10b6e05f4a27169e30d988f70a3b9e50236608fda0e4`.
- Pre-change fast contract against the checkpoint: PASS.
- Post-change fast contract against the checkpoint: PASS.
- Explicit normalized whole-board delta proof: PASS. After normalizing only
  the approved Q1 description, pad-1/pad-2 centres, F.Fab/F.CrtYd endpoints,
  and the three named segment starts, the active board is semantically
  identical to the checkpoint. Pad properties and graphic/segment properties
  other than those coordinates are included in the equality check.
- The project-local Q1 footprint is byte-identical to the updated
  `dmp3130()` generator output. The stale whole-library generator was not run.

## Implemented geometry

Q1 remains on F.Cu at `(63.000, 76.000) mm`, rotation `0 deg`.

| Pad | Function/net | Local centre (mm) | Global centre (mm) | Size (mm) |
|---|---|---:|---:|---:|
| 1 | G / `Q1_GATE` | `(-0.950,+1.000)` | `(62.050,77.000)` | `0.80 x 0.90` |
| 2 | S / `BUCK_IN` | `(+0.950,+1.000)` | `(63.950,77.000)` | `0.80 x 0.90` |
| 3 | D / `BAT_SW` | `(0,-1.000)` | `(63.000,75.000)` | `0.80 x 0.90` |

The old lower-pad centre offset was `1.35 mm`; the corrected value is
`1.35 - 0.80/2 = 0.95 mm`, because Diodes dimension `X1` is measured to the
outer land edge. Lower-pad centre spacing changed from `2.70` to `1.90 mm`;
the copper envelope changed from `3.50 x 2.90` to `2.70 x 2.90 mm`.

- F.Fab: `x=[-0.65,+0.65]`, `y=[-1.45,+1.45]` mm
  (`1.30 x 2.90 mm`).
- F.CrtYd: `x=[-1.60,+1.60]`, `y=[-1.70,+1.70]` mm
  (`3.20 x 3.40 mm`).
- The existing clear silkscreen orientation/pin-1 marker was retained
  byte-identically.

## Bounded routing delta

Only these F.Cu segment starts changed; UUIDs, nets, downstream endpoints,
widths, and layers were preserved:

- `ce7bd062-9fb6-4c9c-8a39-64542cec1e84`, `Q1_GATE`, 0.25 mm:
  start `(62.050,77.000)`, end `(61.650,78.500)`.
- `a4eef94c-3eb6-420b-8595-5f49d55bb7bb`, `BUCK_IN`, 1.00 mm:
  start `(63.950,77.000)`, end `(65.500,77.000)`.
- `cb24be05-8b8c-4b70-b364-97c90cc107a3`, `BUCK_IN`, 1.00 mm:
  start `(63.950,77.000)`, end `(58.000,87.000)`.

The pad-3 `BAT_SW` segment, all vias, zones, rule areas, footprint origins,
and all non-Q1 copper remain unchanged. No subsection is deferred or failed.

## Verification and category delta

- Schematic/PCB parity: PASS; all mismatch arrays are empty.
- Native ERC: PASS, 0 errors and 0 warnings.
- Production metadata: PASS, no errors.
- Native DRC and in-memory zone-refilled DRC: 0 geometric violations and
  0 unconnected items. The in-memory refill did not change the board file
  (same before/after SHA-256
  `61549b45d4fe336986e76bcc78c5ca5532e67df604d155b140b1fd8a9d1bb109`).
- DRC normalized pre/post comparison: PASS. Both results contain exactly two
  inherited `lib_footprint_mismatch` warnings, JP1 and U4; Q1 has no library
  mismatch. There is no DRC category or count delta.
- Full deterministic wrapper: protected checkpoint and parity checks PASS,
  but overall status is FAIL solely because the wrapper treats the two
  inherited DRC warnings as violations. This is the expected baseline result,
  not an implementation regression.
- `git diff --check`: PASS.

`CONTEXT PROVENANCE CONFLICT`: `docs/agent-context.md` claims zero native DRC
violations, while both the actual pre-change and post-change KiCad 10.0.6 DRC
reports contain the two inherited JP1/U4 library-mismatch warnings. They are
not suppressed and were not changed in this scope.

## Changed source paths

- `hardware/esp32-e220.kicad_pcb`
- `hardware/esp32-e220.pretty/Diodes_DMP3130LQ-7_SOT23.kicad_mod`
- `hardware/generate_stage7_footprints.py`

New retained evidence and this handoff are under
`hardware/evidence/q1-production-error-2026-09-11/`.

## Retained / deferred / next gate

- Retained: Q1 pad numbers/nets, origin/rotation, pad 3, pad sizes, all
  downstream endpoints, widths/layers, vias, zones, and non-Q1 placement and
  copper.
- Deferred: production fabrication package generation, pending explicit user
  authorization after independent implementation review.
- Failed subsection: none. The inherited full-wrapper DRC status is disclosed
  above.
- Next required gate: independent `pcb_reviewer` implementation review.

SCOPE VERDICT: Q1 FOOTPRINT CORRECTION IMPLEMENTATION READY FOR REVIEW

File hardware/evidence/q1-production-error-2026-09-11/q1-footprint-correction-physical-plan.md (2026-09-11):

# Q1 footprint correction: read-only physical plan

## Decisive evidence

- Controlled board snapshot: `hardware/esp32-e220.kicad_pcb`, SHA-256
  `dd4d77d521adc1fd744d10b6e05f4a27169e30d988f70a3b9e50236608fda0e4`.
- Official sources retained here: `DMP3130LQ-DS38728-official.pdf` and
  `Diodes-SOT23-package-information-official.pdf`. DS38728 identifies
  `DMP3130LQ-7` as SOT23. Its top view has the two lower terminals G (left) and
  S (right), and the upper terminal D. The schematic/PCB mapping is therefore
  physically coherent as 1/G=`Q1_GATE`, 2/S=`BUCK_IN`, 3/D=`BAT_SW`; no
  topology correction is requested by this plan.
- DS38728 suggested pattern dimensions are `C=2.0`, `X=0.8`, `X1=1.35`,
  `Y=0.9`, `Y1=2.9` mm. The drawing, not the table alone, is decisive:
  `X1` runs from the package centreline to the **outer edge** of the right
  lower land. It is not a pad-centre coordinate. Therefore each lower-pad
  centre is `X1 - X/2 = 1.35 - 0.40 = 0.95 mm` from the centreline.

## Confirmed defect and exact geometry delta

Q1 is at `(63.000, 76.000) mm`, rotation `0 deg`, F.Cu. All current pads are
`0.800 x 0.900 mm` and the vertical pitch is correctly `2.000 mm`. The defect
is the horizontal interpretation of `X1`:

| Pad | Net | Current local/global centre (mm) | Required local/global centre (mm) | Delta |
|---|---|---|---|---|
| 1 | `Q1_GATE` | `(-1.350,+1.000)` / `(61.650,77.000)` | `(-0.950,+1.000)` / `(62.050,77.000)` | `+0.400 X` |
| 2 | `BUCK_IN` | `(+1.350,+1.000)` / `(64.350,77.000)` | `(+0.950,+1.000)` / `(63.950,77.000)` | `-0.400 X` |
| 3 | `BAT_SW` | `(0,-1.000)` / `(63.000,75.000)` | unchanged | none |

Current lower-pad centre spacing is `2.700 mm`; required spacing is
`1.900 mm`. Current copper outer width is `3.500 mm`; required outer width is
`2.700 mm`. Thus the literal copper bounding box is too wide, but each lower
land is displaced 0.400 mm outward: the land ends approximately at the
physical lead centreline instead of covering the lead on both sides. That
lead-to-land misregistration explains PCBWAVE's poor/false-solder warning;
describing the complete footprint bounding box as “smaller” is not a literal
match to the active KiCad geometry.

The current F.Fab rectangle is also wrong for SOT23: it is `3.0 x 2.9 mm`.
Use the Diodes nominal body `H x B = 2.90 x 1.30 mm` (max
`3.00 x 1.40 mm`) in this orientation, with a pad-1 indication at the lower
left. Replace the oversized `4.10 x 4.00 mm` rectangular courtyard with a
`3.50 x 3.40 mm` courtyard centred on Q1 (0.25 mm around the max body and the
`2.90 mm` outer land span). Keep silkscreen outside solder-mask openings.

## Bounded routing contract

One candidate clearly dominates: retain Q1 origin/rotation and pad numbering,
correct the project-local Diodes land pattern, and re-anchor only the tracks
terminating at moved pads. A generic library substitution is not preferred
because the installed KiCad 10 `SOT-23` land dimensions are not the exact
Diodes `0.80 x 0.90 mm` recommendation and would introduce an avoidable
orientation/geometry translation.

- Coupled group: Q1 pads 1/2 plus three terminating F.Cu segments only.
- Re-anchor `ce7bd062-9fb6-4c9c-8a39-64542cec1e84`, `Q1_GATE`, F.Cu,
  0.25 mm: start `(61.650,77.000)` -> `(62.050,77.000)`; preserve end
  `(61.650,78.500)` and the 0.60/0.30 mm via there.
- Re-anchor `a4eef94c-3eb6-420b-8595-5f49d55bb7bb`, `BUCK_IN`, F.Cu,
  1.00 mm: start `(64.350,77.000)` -> `(63.950,77.000)`; preserve end
  `(65.500,77.000)`.
- Re-anchor `cb24be05-8b8c-4b70-b364-97c90cc107a3`, `BUCK_IN`, F.Cu,
  1.00 mm: start `(64.350,77.000)` -> `(63.950,77.000)`; preserve end
  `(58.000,87.000)`.
- Preserve pad-3/BAT_SW segment
  `02de816b-ba50-4df1-87ff-7b85e63e9ca3` at `(60.000,74.000)` ->
  `(63.000,75.000)`, 1.00 mm F.Cu.
- Add no vias and change no layers, widths, zones, rule areas, keepouts,
  component origins, or downstream endpoints. Preserve all non-Q1 copper.
- Return path: retain the existing B.Cu GND zone under this area; no return
  discontinuity or zone edit is needed. The BAT_SW -> Q1.3 -> Q1.2 -> BUCK_IN
  forward-power corridor remains on F.Cu at 1.00 mm.

The corrected lands move inward, away from unrelated nearby items. The nearest
other footprint origins are R2 at `(62.500,67.000)` (9.014 mm), R1 at
`(58.500,67.000)` (10.062 mm), TP4 at `(63.000,87.000)` (11.000 mm), and J8
at `(51.000,76.000)` (12.000 mm). No other placement or corridor must move.

## Transaction checkpoints and expected DRC delta

1. Electrical reviewer confirms the unchanged 1/G, 2/S, 3/D mapping.
2. Independent reviewer grants the physical plan gate.
3. Run the deterministic machine contract against the named pre-change board;
   it must PASS. Create the implementation backup.
4. In one transaction, update the project-local footprint and its generator,
   update the embedded Q1 footprint without moving its origin/rotation, then
   apply exactly the three endpoint changes above.
5. Re-run the machine contract against the pre-change reference, allowing only
   Q1 pad geometry and the named three segment endpoints. Re-run schematic/PCB
   parity, native DRC, and inspect the refilled-board ratsnest.
6. Require zero unconnected items, zero new geometry violations, no Q1 library
   mismatch, and no change to protected footprints/zones. Any unexpected
   result requires rollback and restored-state proof.

Pre-change machine contract and parity PASS. KiCad 10.0.6 reports zero
unconnected items and two pre-existing library-mismatch warnings (JP1 and U4),
with no geometric violations. Expected post-change delta is exactly zero:
the same two warnings, zero unconnected, and no new DRC category or count.

`CONTEXT PROVENANCE CONFLICT`: `docs/agent-context.md` says the active board has
zero native DRC violations, while the actual board checked with KiCad 10.0.6 in
`prechange-drc.json` has the two library-mismatch warnings above. They are
unrelated to Q1 but must not be hidden or counted as a Q1 regression.

The board under `esp32-e220-q1-geometry-candidate.kicad_pcb` is evidence-only;
its relocated project context creates extra missing-`Carrier` library warnings,
so it is not an implementation or release gate artifact.

SCOPE VERDICT: Q1 FOOTPRINT CORRECTION PHYSICAL PLAN PASS

Independent reviewer plan approval is still required before implementation.

ROUTING PLAN READY

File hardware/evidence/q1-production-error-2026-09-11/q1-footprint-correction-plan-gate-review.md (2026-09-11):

# Independent plan gate — Q1 footprint correction

## Scope reviewed

Read-only review of the controlled board, the named pre-change checkpoint,
the evidence-only candidate, `q1-footprint-correction-physical-plan.md`, and
the retained primary Diodes PDFs. No controlled source was modified.

## Decisive geometry adjudication

`DMP3130LQ-DS38728-official.pdf`, p. 5, and the current Diodes SOT23 package
information drawing both show `X1=1.35 mm` from the component centreline to
the **outer edge** of a lower pad. It is not a pad-centre distance. With
`X=0.80 mm`, each lower-pad centre must be `1.35 - 0.80/2 = 0.95 mm` from the
centreline. `Y=0.90`, `C=2.00`, and `Y1=2.90 mm` agree with the existing
vertical geometry.

The active Q1 is therefore defective only in the X locations of pads 1 and 2:

| Item | Active | Required |
|---|---:|---:|
| Pad 1 / `Q1_GATE` local centre | `(-1.350,+1.000)` | `(-0.950,+1.000)` |
| Pad 2 / `BUCK_IN` local centre | `(+1.350,+1.000)` | `(+0.950,+1.000)` |
| Pad 3 / `BAT_SW` local centre | `(0,-1.000)` | unchanged |
| All pad copper | `0.80 x 0.90 mm` | unchanged |
| Copper envelope | `3.50 x 2.90 mm` | `2.70 x 2.90 mm` |

The source/footprint/physical-pin chain is preserved: symbol pin 1 / pad 1 /
Diodes G = `Q1_GATE`; pin 2 / pad 2 / Diodes S = `BUCK_IN`; pin 3 / pad 3 /
Diodes D = `BAT_SW`. The top-view orientation is the standard SOT-23 lower
left/lower right/upper arrangement. No electrical or pin-numbering change is
approved or needed.

## Approved implementation boundary

1. In the project-local `Diodes_DMP3130LQ-7_SOT23` footprint and Q1's embedded
   board instance, set pads 1/2 to `(-0.950,+1.000)` / `(+0.950,+1.000)` mm.
   Preserve pad sizes, Q1 origin `(63.000,76.000) mm`, rotation, layers,
   pad numbers, nets, and pad 3.
2. Re-anchor exactly these F.Cu endpoints, preserving all other endpoints,
   widths, layers, and UUIDs: `ce7bd062-9fb6-4c9c-8a39-64542cec1e84` start to
   `(62.050,77.000)`; `a4eef94c-3eb6-420b-8595-5f49d55bb7bb` and
   `cb24be05-8b8c-4b70-b364-97c90cc107a3` starts to `(63.950,77.000)`.
3. Correct the footprint representation without changing copper: F.Fab body
   is nominal `B x H = 1.30 x 2.90 mm` in this orientation, so use
   `x=[-0.65,+0.65]`, `y=[-1.45,+1.45]`. The current `3.00 x 2.90 mm` F.Fab
   rectangle is not the SOT23 body. A conservative 0.25-mm courtyard around
   the maximum of body and corrected copper is `3.20 x 3.40 mm`,
   `x=[-1.60,+1.60]`, `y=[-1.70,+1.70]`. The manufacturer does not prescribe
   a courtyard; this is a project representation rule, not a Diodes land
   dimension. Keep the pad-1 marking clear of mask openings.
4. Do not alter any other footprint, zone, rule area, via, layer, component
   origin, or downstream trace endpoint. In particular retain the B.Cu GND
   pour and the Q1.3 `BAT_SW` 1.00-mm F.Cu segment.

The bounded routing change is feasible. The two 1.00-mm `BUCK_IN` tracks and
the 0.25-mm gate track merely shorten/re-angle at their Q1 endpoints. They
remain isolated from unrelated copper; the nearest other footprint origin is
R2 at 9.014 mm. No antenna boundary, mechanical keepout, buck-cell placement,
return path, zone, or repairability constraint is affected.

## Required transaction evidence

Use `esp32-e220-q1-prechange-reference.kicad_pcb` (SHA-256
`dd4d77d521adc1fd744d10b6e05f4a27169e30d988f70a3b9e50236608fda0e4`) as the
named backup/checkpoint. Before and after the transaction, the deterministic
contract against that reference must pass, allowing only the Q1 footprint
geometry/graphics and the three endpoints above. Require parity PASS, ERC
PASS, zero unconnected items, zero new DRC geometry violations, and the
unchanged two inherited library-mismatch warnings for JP1 and U4.

The evidence-only candidate reports no unconnected items or geometry
violations. Its ten additional `Carrier` library warnings are an artefact of
running a board outside `hardware/`, where `${KIPRJMOD}/esp32-e220.pretty`
cannot resolve; they are not an active-board result and cannot be used as the
implementation DRC gate.

`CONTEXT PROVENANCE CONFLICT`: `docs/agent-context.md` states zero native DRC
violations, whereas `prechange-drc.json` records two inherited
`lib_footprint_mismatch` warnings (JP1 and U4), with zero unconnected items
and zero geometry violations. This is unrelated to Q1 and must remain visible.

SCOPE VERDICT: Q1 FOOTPRINT CORRECTION PHYSICAL PLAN PASS

REVIEW PASS

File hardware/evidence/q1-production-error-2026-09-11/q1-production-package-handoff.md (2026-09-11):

# Q1-corrected production package handoff

## SCOPE STATUS

`Q1-CORRECTED PRODUCTION PACKAGE GENERATED — SELF-AUDIT PASS`

- Release directory: `hardware/releases/rev1-q1-footprint-correction-2026-09-11/`
- Archive: `hardware/releases/ESP32-E220-Carrier-Rev1-Q1-Footprint-Correction-2026-09-11.zip`
- Archive SHA-256: `f73af617de933ccc6f5711d3044aae0209fe0a45801aee45330c778f160da43e`
- Archive size: 357981 bytes; 31 files; ZIP CRC and byte-for-byte tree comparison PASS.
- Source PCB SHA-256: `61549b45d4fe336986e76bcc78c5ca5532e67df604d155b140b1fd8a9d1bb109`
- Source schematic SHA-256: `8ade3ec2f6a90f39763b8dd5570fcfe1709e34482d2f83a886886c73e5a4dacc`
- Production metadata SHA-256: `806393fc7e9b32da32d34c3adb6357ec87d1d0236a449df42e610f37361dd639`
- Q1 footprint SHA-256: `a964b65e180fd9867d69eab31656367a13d0e120a503b78c8982a64b08626ebc`

Direct F.Cu Gerber audit found rectangular aperture D30=`0.800000 x
0.900000` at Q1 pad centres 1=(62.05,77.00), 2=(63.95,77.00), and
3=(63.00,75.00) mm. Gerber object/net attributes are 1=`Q1_GATE`,
2=`BUCK_IN`, 3=`BAT_SW`. IPC-D-356 independently carries the same Q1
pad/net map and 0.80 x 0.90 mm pad dimensions.

Excellon and drill-report counts agree: 119 PTH and 3 NPTH. The package also
contains the Gerber job file, IPC-D-356, BOM, direct KiCad CPL, THT and
DNP/user manifests, assembly/fabrication notes, assembly/silkscreen PDFs,
layer previews, drill maps, release manifest, self-audit, and per-file
checksums.

The active PCB hash was unchanged by generation. The tracked legacy
`hardware/releases/rev1/` tree and
`hardware/releases/ESP32-E220-Carrier-Rev1-PCBA.zip` are unchanged versus
repository HEAD. The legacy hard-coded `audit_rev1_release.py` was not used
to claim PASS; the retained Q1-specific generator and direct audit are
`generate_q1_corrected_release.sh` and `audit_q1_corrected_release.py`.

Implementation gate basis: ERC 0 errors / 0 warnings; parity PASS;
production metadata PASS; native DRC 0 unconnected and no Q1/geometric
errors. Two inherited `lib_footprint_mismatch` warnings for JP1/U4 remain
unchanged and unsuppressed.

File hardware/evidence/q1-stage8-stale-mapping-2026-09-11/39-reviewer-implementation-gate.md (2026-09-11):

# Q1 Stage-8 stale-mapping implementation gate

- Scope: `generate_stage8_placement.py` must not regenerate Q1.3 on `BAT_FUSED`.
- Source finding: the Stage-8 generator predated the J8/`BAT_SW` architecture update; it retained Q1.3=`BAT_FUSED` and omitted `/BAT_SW` from its net registry.
- Regeneration: `12-...` and `17-...` are non-active candidates generated before and after Stage 7. Both record Q1.1=`Q1_GATE`, Q1.2=`BUCK_IN`, Q1.3=`BAT_SW` and identical Q1 pad geometry.
- Footprint persistence: `14-...` and `16-...` have identical SHA-256 for `Diodes_DMP3130LQ-7_SOT23.kicad_mod` across Stage-7 regeneration.
- Active-board checks: parity, ERC, production metadata, and Q1 production-archive integrity PASS. Native DRC has the same two pre-existing warning-severity `lib_footprint_mismatch` entries for JP1 and U4 before and after this source-only change; it has zero geometric, zone, and unconnected findings.

SCOPE VERDICT: q1-stage8-stale-mapping PASS

REVIEW PASS

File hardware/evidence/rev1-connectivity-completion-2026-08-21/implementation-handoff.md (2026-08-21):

# Rev.1 final-connectivity active implementation handoff

## Authorized plan gate

Before active-board mutation, the independent reviewer reported verbatim:

`SCOPE VERDICT: REV1 CONNECTIVITY OLED PLAN PASS`

`REVIEW PASS`

The reviewer independently reproduced the bounded OLED candidate with native
DRC 0 violations / 6 unconnected items and board-contract/parity PASS, and
verified the exact endpoint, 0.25-mm 26-segment, eight standard-via contract
without regressions. The active baseline remained byte-identical to
`00-active-baseline.kicad_pcb` at this gate.

## Pre-implementation deterministic state

- Active and `00-active-baseline.kicad_pcb` SHA-256:
  `4f6fba9ed19c3f0290842b62f3ec087d28e3911c7d12f31d2e581aa1c8e26650`.
- Fast board contract against the approved baseline: PASS.
- Fresh native DRC: 0 violations and exactly 8 unconnected items; retained as
  `02-active-pre-implementation-native-drc.json`.
- Exact initial native-DRC groups:
  1. `/GND`: C9.2-connected F.Cu track at `(17.5,34)` to the C5.2-connected
     F.Cu track at `(24.725,48)`.
  2. `/GND`: disconnected filled polygons of F.Cu GND zone `dfb51e4c...`,
     reported zone-to-itself at `(64,52)`.
  3. `/GND`: J2.2 `(136.4,16.54)` to the connected B.Cu GND track reported at
     `(104,18)` and terminating at `(111,16.54)`.
  4. `/BAT_PLUS`: TP1.1 `(48,87)` to the accepted F.Cu BAT_PLUS component
     reported at `(35,78.5)`, whose nearest endpoint is `(42.862,78.5)`.
  5. `/BUCK_IN`: TP3.1 `(58,87)` to the Q1.2-connected F.Cu component reported
     at `(64.349999,77)`.
  6. `/BUCK_IN`: R2.1 `(62.5,67.725)` to the F.Cu trunk reported at
     `(65.5,70)`.
  7. `/OLED_SDA`: J5.4 `(63,27.62)` to J2.11 `(136.4,39.4)`.
  8. `/OLED_SCL`: J5.3 `(63,25.08)` to J2.14 `(136.4,47.02)`.

  Exact UUIDs and the full native objects are retained in
  `02-active-pre-implementation-native-drc.json`.

## Controlled transaction result

| Transaction | Scope | Track geometry | Contract | Parity | Native result |
| --- | --- | --- | --- | --- | --- |
| A | R2.1 to BUCK_IN trunk | F.Cu, 3.765053 mm, 0.25 mm | PASS | PASS | 0 violations; 8 -> 7 unconnected |
| B | TP3 dead-end BUCK_IN probe | F.Cu, 11.845779 mm, 1.00 mm | PASS | PASS | 0 violations; 7 -> 6 unconnected |
| C | TP1 dead-end BAT_PLUS probe | F.Cu, 9.932223 mm, 1.00 mm | PASS | PASS | 0 violations; 6 -> 5 unconnected |
| D | exact three GND groups | three attempted tracks | PASS | PASS | FAIL: 1 new violation; 5 -> 3 instead of 5 -> 2 |

Transactions A--C are retained. Their routes are respectively
`(62.5,67.725)->(65.5,70)`, `(64.35,77)->(58,87)`, and
`(42.862,78.5)->(48,87)`. TP3 and TP1 remain dead-end probe branches and do
not replace any accepted series power path.

## Transaction D fail-fast rollback

The intended D geometry was: 0.50-mm B.Cu C9.2 via `(14,34)` to existing GND
via `(12,27)`; 0.25-mm F.Cu U1 pad 8 `(69.25,54.6)` to C4.2
`(67,54.225)`; and 0.50-mm B.Cu existing branch endpoint `(111,16.54)` to
J2.2 `(136.4,16.54)`. The U1-island track crossed the existing `/SS_TR` track
reported at `(67.85,55.25)`. Native DRC retained as
`21-post-D-native-drc.json` reports exactly one `tracks_crossing` violation.
The attempted C9.2 B.Cu connection also did not join the native connected GND
component, leaving that airwire visible. J2.2 and the GND-zone island cleared
in the failed copy, but the whole functional transaction was rejected.

Only transaction D was rolled back to named backup
`19-pre-D-three-GND-groups.kicad_pcb`. Active and backup are byte-identical at
SHA-256
`aec6bac3ae6710390cb5eba7477a1036d531b02adafb1cbea38091fd7987ef13`.
Restored proof: fast contract PASS (`23-restored-D-fast-contract.log`), parity
PASS (`25-restored-D-parity.json`), native DRC 0 violations / 5 unconnected
items (`24-restored-D-native-drc.json`). Counts are 37 footprints, 185 tracks,
56 vias, four zones, and one rule area.

The five restored airwires are the original three GND groups plus OLED_SDA and
OLED_SCL. Transactions E/F were not started. All pre-existing geometry,
including protected buck objects, U4/C9/C10 and its 8 x 10 mm AUX_3V3 zone,
antenna rule area, E220 routes, J6 routes, and J9 routes, remains unchanged;
only the three accepted A--C tracks differ from `00-active-baseline.kicad_pcb`.
`26-restored-active-invariance.log` proves all 238 baseline copper UUIDs are
identical, all 37 footprints/pads and all zone/rule-area outlines are
unchanged, the via count remains 56, and E220/AUX_3V3 item sets are unchanged.

`SCOPE STATUS: REV1 CONNECTIVITY COMPLETION STOPPED AFTER RESTORED D FAILURE`

`ROUTING PLAN REVISION REQUIRED`

No production output was generated.

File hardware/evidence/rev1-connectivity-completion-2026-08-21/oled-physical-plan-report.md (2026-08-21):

# Rev.1 final-connectivity OLED routing plan

## Scope and authority

- Active baseline: `hardware/esp32-e220.kicad_pcb`, SHA-256
  `4f6fba9ed19c3f0290842b62f3ec087d28e3911c7d12f31d2e581aa1c8e26650`.
- Byte-identical retained snapshot: `00-active-baseline.kicad_pcb`.
- OLED-only proof candidate: `01-oled-candidate.kicad_pcb`, SHA-256
  `e5b45270dda72f84c48e815201ef6969b4805fe110cb243a34236a6daeed18f4`.
- The active PCB remained byte-identical to the baseline throughout planning.
- Coupled group is only `OLED_SDA` and `OLED_SCL`. No footprint, zone outline,
  board outline, rule area, or pre-existing track/via was changed.

## Exact initial native-DRC airwires

Native DRC on the active board reported zero geometric violations and exactly
eight unconnected pairs:

1. `/GND`: C9.2-connected 0.5-mm F.Cu track `(17.5,34)->(14,34)` and via
   `(14,34)` to the nearest other connected GND component, reported as C5.2
   `(24.725,48)` (UUIDs `ec0ee8c8...` and `03d7c258...`).
2. `/GND`: disconnected filled islands of the same F.Cu GND zone UUID
   `dfb51e4c...`; native DRC reports zone-to-itself at the zone origin
   `(64,52)`. Filled-polygon inspection resolves the isolated U1-ground island
   containing U1 pads 5/6/8/15/16/EP from the connected C1/C3 and C2/C4
   GND-island clusters. There is no distinct reference/pad item in the native
   DRC pair, so none is invented.
3. `/GND`: J2.2 `(136.4,16.54)` to the connected B.Cu GND branch
   `(104,18)->(111,16.54)`, which terminates at J1.2; the same component extends
   `(94,18)->(104,18)` from J6.1.
4. `/BAT_PLUS`: TP1.1 `(48,87)` to F.Cu BAT_PLUS track component reported at
   `(35,78.5)`, length 7.8620 mm.
5. `/BUCK_IN`: TP3.1 `(58,87)` to F.Cu BUCK_IN track component reported at
   `(64.349999,77)`, length 1.1500 mm.
6. `/BUCK_IN`: R2.1 `(62.5,67.725)` to F.Cu BUCK_IN track component reported at
   `(65.5,70)`, length 9.5000 mm.
7. `/OLED_SDA`: J5.4 `(63,27.62)` to J2.11 `(136.4,39.4)`.
8. `/OLED_SCL`: J5.3 `(63,25.08)` to J2.14 `(136.4,47.02)`.

Authoritative report: `00-active-native-drc.json`.

## Bounded routing contract

All signal segments are 0.25 mm wide. All vias are through vias, 0.60 mm
diameter with 0.30 mm drill. No 0.20-mm segment is needed.

`OLED_SDA`, total planar length 100.019519 mm: B.Cu 63.190181 mm and F.Cu
36.829339 mm, four vias.

- B.Cu: `(63,27.62) -> (78,27.62) -> (81,30.62) -> (81,46)`.
- Via: `(81,46)`.
- F.Cu: `(81,46) -> (97.5,46)`.
- Via: `(97.5,46)`.
- B.Cu: `(97.5,46) -> (104,46)`.
- Via: `(104,46)`.
- F.Cu: `(104,46) -> (108,50.8) -> (112.5,50.8) -> (114,50.3) -> (122,50.3)`.
- Via: `(122,50.3)`.
- B.Cu: `(122,50.3) -> (124,48.3) -> (124,42) -> (130,39.4) -> (136.4,39.4)`.

`OLED_SCL`, total planar length 95.987198 mm: B.Cu 60.403131 mm and F.Cu
35.584067 mm, four vias.

- B.Cu: `(63,25.08) -> (77,25.08) -> (82,30.08) -> (82,47)`.
- Via: `(82,47)`.
- F.Cu: `(82,47) -> (97.5,47)`.
- Via: `(97.5,47)`.
- B.Cu: `(97.5,47) -> (104,47)`.
- Via: `(104,47)`.
- F.Cu: `(104,47) -> (107.5,51.35) -> (112.5,51.35) -> (114,51.3) -> (122,51.3)`.
- Via: `(122,51.3)`.
- B.Cu: `(122,51.3) -> (126,51.3) -> (132,46.8) -> (134,47.02) -> (136.4,47.02)`.

The layer swaps have specific local purposes: B.Cu leaves the J5 PTH pads;
F.Cu crosses the existing B.Cu WS2812 corridor; B.Cu crosses the F.Cu 5V
spine; F.Cu passes below J1; final B.Cu fanout avoids the existing F.Cu
GPIO23 approach to J2. This is one dominant candidate; no floorplanning or
placement alternative is needed.

## Return path, keepouts, and preserved work

- Both GND planes remain present. Zone outlines are byte-semantically
  unchanged; refilling around the new signal copper creates no new GND
  airwire. Initial GND airwires remain exactly three in the candidate.
- The closest signal centerline to `ESP32_ANTENNA_EXCLUSION` is at Y=51.35 mm;
  the closest 0.60-mm via center is at Y=51.30 mm. The exclusion begins at
  Y=52.0 mm for X=104.7..142.7 mm. Contract hit list is empty.
- All pre-existing tracks and vias are preserved by UUID. E220 five-signal,
  BUTTONS, BAT_SENSE, RGB, U4/AUX, protected buck, and 5V routing item sets are
  unchanged.
- No copper zone, rule area, or placement is replaced. Only 26 signal
  segments and eight signal vias are added.

## Checkpoint order and expected DRC delta

1. Prove active SHA-256 and copy the active board to the named transaction
   backup before implementation.
2. Implement `OLED_SDA` exactly as listed; run fast board contract and native
   DRC. Expected delta: one OLED airwire removed and zero new violation.
3. Implement `OLED_SCL` exactly as listed; run fast board contract and native
   DRC. Expected delta: second OLED airwire removed and zero new violation.
4. Refill zones, then run full contract, parity, and native DRC before
   accepting the local checkpoint.

Candidate deterministic result: fast board contract PASS; schematic-PCB
parity PASS; native DRC 0 violations; unconnected items 8 -> 6, with only the
pre-existing GND x3, BAT_PLUS x1, and BUCK_IN x2 findings remaining. Counts
change 37 footprints / 182 tracks / 56 vias / 4 copper zones / 1 rule area to
37 / 208 / 64 / 4 / 1 for this OLED-only proof.

Risk is limited to exact transactional replay near the lower J1/antenna-rule
boundary. The listed coordinates already pass native keepout and clearance
checks; any deviation should fail fast rather than be improvised on the active
board.

SCOPE VERDICT: REV1 CONNECTIVITY OLED PLAN PASS

ROUTING PLAN READY

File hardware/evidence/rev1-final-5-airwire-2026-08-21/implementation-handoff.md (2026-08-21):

# Rev.1 final five-airwire active implementation handoff

## Gate and controlled baseline

The independent read-only plan reviewer reported verbatim before active-board
mutation:

`SCOPE VERDICT: REV1 FINAL 5-AIRWIRE PLAN PASS`

`REVIEW PASS`

The reviewed authority was `03-candidate.kicad_pcb`. The active PCB and named
pre-implementation backup `10-active-pre-implementation.kicad_pcb` both had
SHA-256
`aec6bac3ae6710390cb5eba7477a1036d531b02adafb1cbea38091fd7987ef13`.
The initial deterministic state was 37 footprints, 185 tracks, 56 vias, four
copper zones, one rule area, two copper layers, 145 x 90 mm, contract PASS,
parity PASS, and native DRC 0 violations / 5 unconnected items.

The exact initial groups were:
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

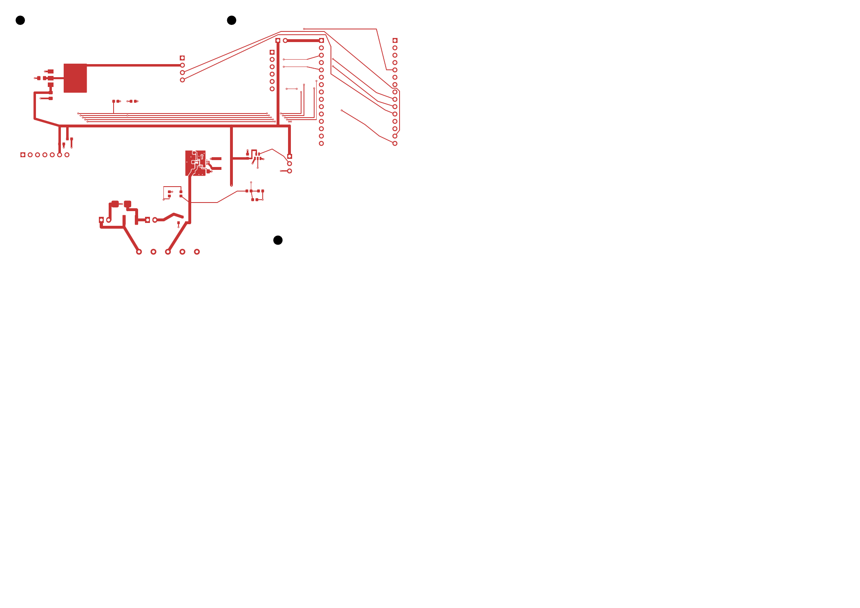
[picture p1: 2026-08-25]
blog/Design/images/03-dorozhki-verhniy-sloy.png

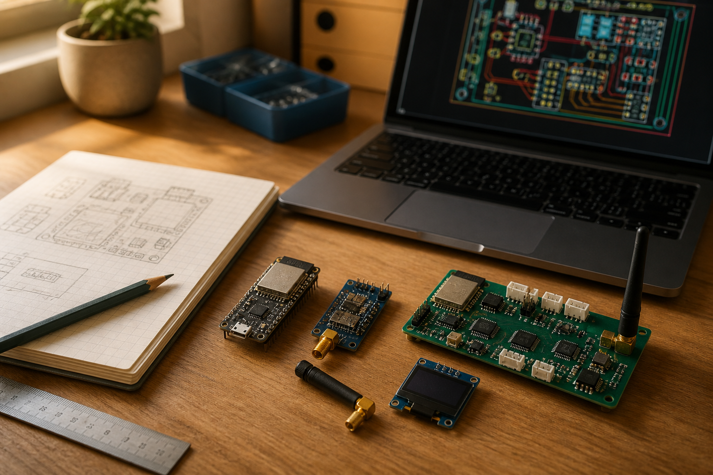
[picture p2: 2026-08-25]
blog/Design/images/01-oblozhka-protsess.png

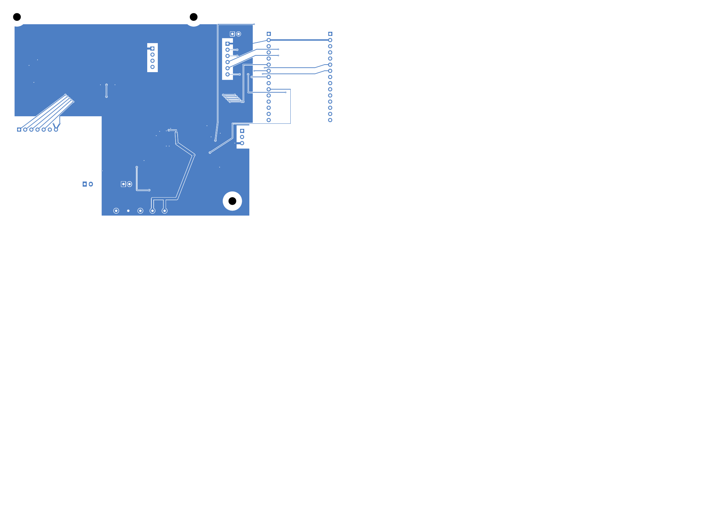
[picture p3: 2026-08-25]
blog/Design/images/09-final-bcu-production.png

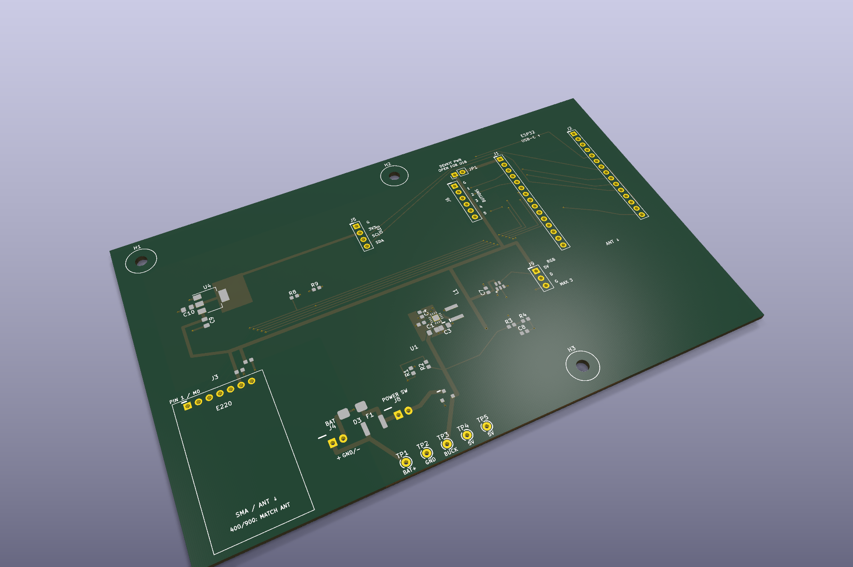
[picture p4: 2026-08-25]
blog/Design/images/02-realnaya-plata-3d.png

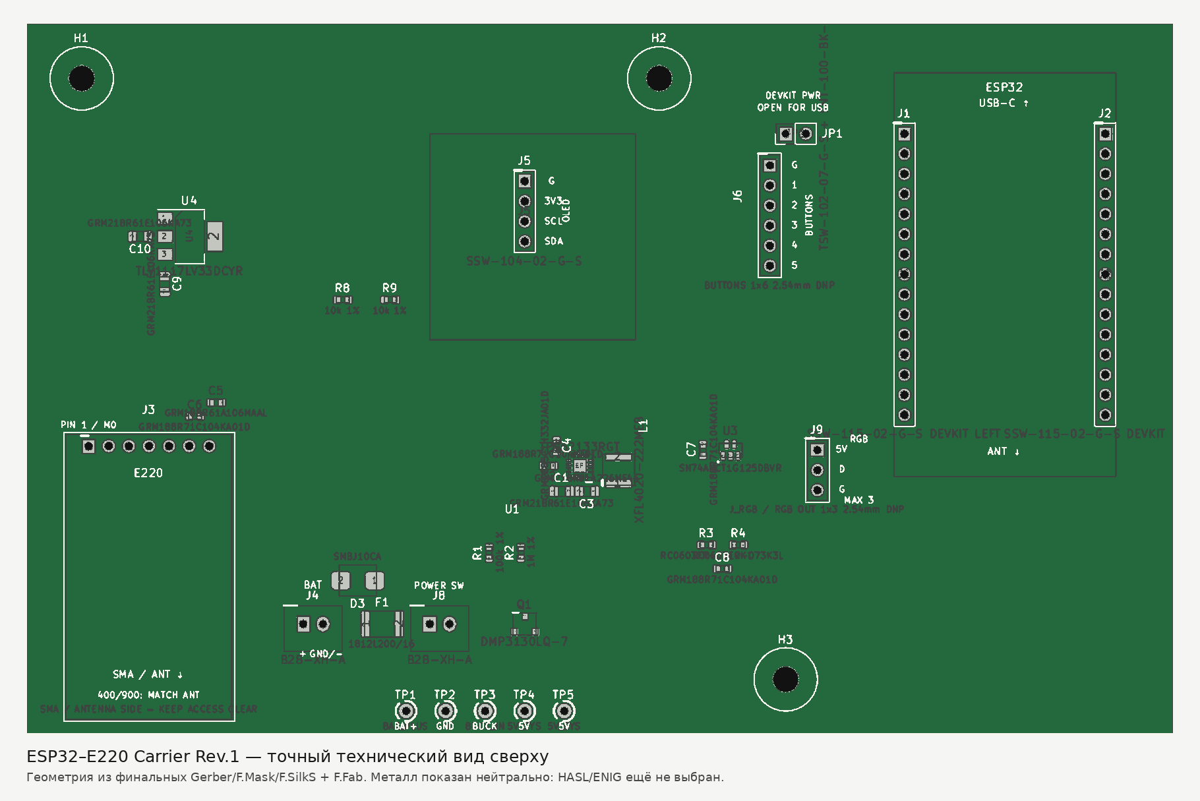
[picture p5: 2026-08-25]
blog/Design/images/05-final-top-technical.png

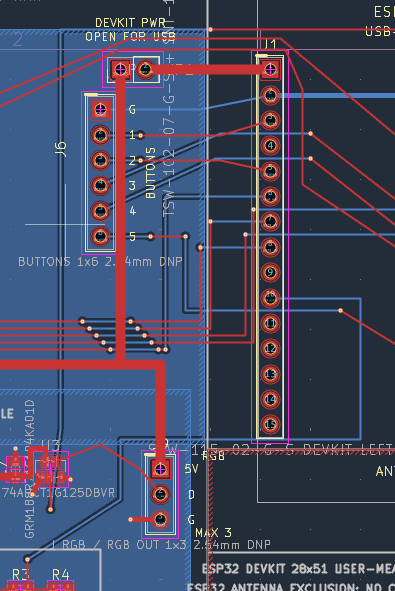
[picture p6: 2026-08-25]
blog/Design/images/07-j6-ground-discussion.png

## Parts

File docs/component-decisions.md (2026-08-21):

# Принятые решения по компонентам Rev.1

Назначение: русскоязычный журнал решений для человека. Оперативные английские сведения для агентов находятся в `docs/agent-context.md`.

## Статусы

- **УТВЕРЖДЕНО** — электрическое решение входит в действующую основу.
- **ПРОЕКТНЫЙ ВЫБОР** — инженерное решение, которое требуется проверить на образце.
- **НЕ УСТАНАВЛИВАТЬ** — элемент предусмотрен, но по умолчанию отсутствует.
- **КАНДИДАТ ДЛЯ РАЗМЕЩЕНИЯ** — геометрия видна на плате, но не разрешена для производства.
- **ОТЛОЖЕНО** — данных недостаточно для окончательного выпуска.

## Силовой вход

| Узел | Решение | Состояние и основание |
| --- | --- | --- |
| J4 | JST `B2B-XH-A`, 2 контакта, шаг 2,50 мм | выбран для защищённого входа 2S; ответная часть `XHP-2` с контактами `SXH-001T-P0.6`; окончательно проверить жгут и разгрузку натяжения |
| J8 | JST `B2B-XH-A`, 2 контакта, шаг 2,50 мм | УТВЕРЖДЕНО для внешнего механического выключателя; 1=`BAT_FUSED`, 2=`BAT_SW`; 3 А при AWG22 превышают требование 2 А |
| F1 | Littelfuse `1812L200/16` | УТВЕРЖДЕНО; 2,0 А удержания, 3,5 А срабатывания, 16 В; требуется проверка температурного снижения характеристик |
| Q1 | Diodes `DMP3130LQ-7` | УТВЕРЖДЕНО; P-MOS, 30 В, 1=G=`Q1_GATE`, 2=S=`BUCK_IN`, 3=D=`BAT_SW` |
| R1 | 100 кОм, затвор–GND | ПРОЕКТНЫЙ ВЫБОР |
| R2 | 1 МОм, `BUCK_IN`–затвор | ПРОЕКТНЫЙ ВЫБОР |
| D3 | Littelfuse `SMBJ10CA` | ПРОЕКТНЫЙ ВЫБОР; двунаправленный TVS 10 В между `BAT_FUSED` и GND |

Прежняя входная система USB4105/TUSB320/TPD4S311/TLV704/TPS259630 полностью отменена и удалена из действующей схемы.

## Преобразователь 5 В

| Обозначение | Компонент | Решение |
| --- | --- | --- |
| U1 | TI `TPS62133RGT` | УТВЕРЖДЕНО; фиксированные 5 В, корпус RGT0016C |
| L1 | Coilcraft `XFL4020-222MEB` | УТВЕРЖДЕНО; 2,2 мкГн |
| C1 | Murata `GRM21BR61E106KA73` | 10 мкФ, 25 В, X5R |
| C2 | Murata `GRM188R71C104KA01D` | 0,1 мкФ, 16 В, X7R |
| C3 | Murata `GRM21BR61A226ME44` | 22 мкФ, 10 В, X5R |
| C4 | Murata `GRM1885C1H332JA01D` | 3,3 нФ, 50 В, C0G |

Посадочное место U1 использует 16 периферийных площадок 0,600×0,240 мм, медную EP 1,680×1,680 мм и апертуру пасты 1,550×1,550 мм примерно 85 %. Тепловые переходные отверстия не встроены в посадочное место и выбираются при трассировке.

## Модуль ESP32 DevKit

| Узел | Решение | Ограничение |
| --- | --- | --- |
| J1/J2 | 2 × Samtec `SSW-115-02-G-S` | две розетки 1×15, шаг 2,54 мм, сверление 1,040 мм |
| Механический шаблон | `ESP32_DevKit_30pin_Socket_2x15_MechanicalTemplate` | подтверждены только ряды и расстояние 25,400 мм; габарит 28×51 мм пользовательский |
| Питание | `5V_SYS` на VIN | 500 мА — **ПРОЕКТНОЕ ВЫДЕЛЕНИЕ**, не **ПАСПОРТНЫЙ МАКСИМУМ** неизвестной платы |

USB-C и антенна DevKit должны быть доступны с края. Точная антенная область консервативно считается запретной для меди и компонентов.

## E220

| Узел | Решение | Ограничение |
| --- | --- | --- |
| J3 | Samtec `SSW-107-02-G-S` | розетка 1×7, шаг 2,54 мм, сверление 1,040 мм |
| Шаблон | `E220_T22D_Socket_400_900` | общая геометрия 400/900 T22D подтверждена документом и STEP/LIB EBYTE; проверить глубину сопряжения на первом образце |
| R8/R9 | 10 кОм к GND | подтяжки M0/M1 |
| C5/C6 | 10 мкФ + 100 нФ | обязательная местная развязка питания |

На одной плате устанавливается один модуль. Антенна выбирается отдельно для 400 или 900 МГц.

## Внешнее питание 3,3 В

| Узел | Решение | Ограничение |
| --- | --- | --- |
| U4 | TI `TLV1117LV33DCYR` | `5V_SYS` → `AUX_3V3`; вывод 2 и tab являются выходом |
| C9/C10 | Murata `GRM21BR61E106KA73` | по 10 мкФ, 25 В, X5R; входной и выходной конденсаторы U4 |
| Выделение `AUX_3V3` | 100 мА всего | только OLED/J5; J6 не имеет питания, J7 удалён |

Это **ПРОЕКТНОЕ ВЫДЕЛЕНИЕ**, а не **ПАСПОРТНЫЙ МАКСИМУМ** тока U4 при
нагрузке. Добавленные 0.100 мА в расчёте `5V_SYS` — только конвенция учёта:
TI нормирует их как максимальный ток покоя без нагрузки, а не как
гарантированный ток земли U4 при 100 мА. Нужна **ПРОТОТИПНАЯ ВАЛИДАЦИЯ**
температуры U4 и переходных токов на фактической плате.

## Дисплей OLED

| Узел | Решение | Ограничение |
| --- | --- | --- |
| J5 | Samtec `SSW-104-02-G-S` | съёмная розетка 1×4; порядок 1=GND, 2=VCC, 3=SCL, 4=SDA |
| Питание | `AUX_3V3` от U4 | 5 В запрещены; `DEVKIT_3V3` не используется для внешних аксессуаров |
| R10/R11 | 4,7 кОм, 1 %, к `AUX_3V3` | `DNP=YES`, без посадочного места по умолчанию |
| Механический шаблон | `OLED_0p96_4pin_MechanicalTemplate_PENDING_DATUM` | известны габарит и часть координат; окончательный выпуск ОТЛОЖЕН |

Выделение 100 мА является консервативным проектным числом, а не паспортным
максимумом модуля, и составляет полное выделение `AUX_3V3` 100 мА. Требуется
измерить реальный ток и проверить U4 на образце.

## Панель кнопок

| Узел | Решение | Состояние |
| --- | --- | --- |
| J6 | `BUTTONS` 1×6, шаг 2,54 мм | `DNP=YES`; 1=GND, 2=GPIO13, 3=GPIO14, 4=GPIO18, 5=GPIO19, 6=GPIO23 |
| Назначение | пять нормально разомкнутых кнопок | только активный низкий уровень с программными подтяжками вверх; внешний уровень и универсальное GPIO-применение запрещены |
| J7 | отсутствует | DISPLAY_AUX удалён; J1.9/GPIO33 намеренно не подключён |

## WS2812 и AHCT

| Узел | Решение | Состояние |
| --- | --- | --- |
| U3 | TI `SN74AHCT1G125DBVR` | УТВЕРЖДЕНО как преобразователь GPIO4 → `WS2812_DATA_5V`; released DBV0005A footprint TI, 0,60×1,10 мм |
| C7 | 100 нФ | местная развязка U3 |
| J9 / `J_RGB` | 1×3, шаг 2,54 мм | `DNP=YES`; 1=`5V_SYS`, 2=`WS2812_DATA_5V`, 3=GND; не более трёх внешних WS2812B-V5 |
| Последовательный резистор данных | отсутствует | типовая схема WorldSemi не задаёт резистор или номинал; непроверенный номинал не вводится |
| D2 | отсутствует | бортовой WS2812 и его кандидат посадочного места удалены |

## Контрольные точки

Предусмотрены только TP1…TP5: BAT+, GND, BUCK_IN, 5V_SYS и 5V_SYS.
Сигнальные TP6…TP10 удалены. TP1…TP5 — металлизированные пробные отверстия
1,0 мм / 2,0 мм без закупаемого или устанавливаемого компонента.

## Посадочные места и изготовление

- JST B2B-XH-A: шаг 2,500 мм, сверление 1,000 мм, медь 1,70×2,00 мм по проектной библиотеке.
- J6/J9: проектные однорядные точки 2,54 мм со сверлением 1,000 мм и медью
  1,70 мм; пользовательская установка, PCBA DNP.
- Samtec SSW: официальный шаг 2,540 мм и сверление 1,040 мм; диаметр меди 1,70 мм — проектный выбор, который должен подтвердить сборщик.
- L1 и Q1 используют геометрию, основанную на официальных рекомендуемых площадках изготовителей.
- F1, D3, корпуса Murata и резисторы используют явно отмеченные проектные номинальные площадки IPC; перед серией их должен подтвердить сборщик.
- R1/R2/R8/R9 закупаются по политике `APPROVED_GENERIC`: 0603/1608, заданное сопротивление, 1 %, не менее 0,1 Вт, 50 В, −55…125 °C; допустимы эквивалентные замены.
- Отверстия 8…10 на E220 являются только механическими ориентирами и не создаются как электрические контакты.

## Неизменяемая электрическая основа

Без нового подтверждённого электрического замечания и согласия пользователя нельзя менять:

- внешний защищённый аккумулятор 2S;
- F1/D3/Q1;
- TPS62133/L1/C1…C4;
- действующие связи DevKit, E220, OLED, кнопок J6 и выхода `J_RGB` через AHCT;
- назначения GPIO;
- состояние R10/R11 `DNP`;
- отсутствие старой входной схемы USB-C.

Физическое размещение и трассировка могут меняться только в рамках согласованной стадии и независимой проверки.

## Статус предсерийной сборки

PCBA устанавливает носитель и все элементы класса PCBA_POPULATE. J6/J9 —
DNP_USER; TP1…TP5 — PLATED_TEST_HOLE; R10/R11 — NO_FOOTPRINT_DNP.
ESP32 DevKit, E220 и OLED являются пользовательскими модулями. JP1 — header
`TSW-102-07-G-S`; шунт `SNT-100-BK-G` поставляется отдельно для ручной
установки, а не как второе посадочное место.

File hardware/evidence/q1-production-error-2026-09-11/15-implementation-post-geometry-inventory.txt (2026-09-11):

./kicad/include/properties/property.h(607): assert "m_choices.GetCount() > 0" failed in PROPERTY_ENUM(): No enum choices defined
./kicad/include/properties/property.h(607): assert "m_choices.GetCount() > 0" failed in PROPERTY_ENUM(): No enum choices defined
./kicad/include/properties/property.h(607): assert "m_choices.GetCount() > 0" failed in PROPERTY_ENUM(): No enum choices defined
./kicad/pcbnew/pcb_track.cpp(387): assert ""false"" failed in GetWidth(): Warning: PCB_VIA::GetWidth called without a layer argument
board=hardware/esp32-e220.kicad_pcb
Q1 footprint=Diodes_DMP3130LQ-7_SOT23 position=(63.000, 76.000) rotation=0.000 layer=F.Cu
Q1 pads:
  pad=1 net=/Q1_GATE position=(62.050, 77.000) size=(0.800, 0.900) rotation=0.000
  pad=2 net=/BUCK_IN position=(63.950, 77.000) size=(0.800, 0.900) rotation=0.000
  pad=3 net=/BAT_SW position=(63.000, 75.000) size=(0.800, 0.900) rotation=0.000
nearby footprints (reference point within 12 mm):
  ref=R2 footprint=Resistor_0603_1608Metric position=(62.500, 67.000) rotation=90.000 distance=9.014
  ref=R1 footprint=Resistor_0603_1608Metric position=(58.500, 67.000) rotation=90.000 distance=10.062
  ref=TP4 footprint=TestPoint_THT_1p0mm_PROTOTYPE position=(63.000, 87.000) rotation=0.000 distance=11.000
  ref=J8 footprint=JST_B2B-XH-A_1x02_P2.50mm_THT position=(51.000, 76.000) rotation=0.000 distance=12.000
copper items with an endpoint/position within 8 mm of Q1:
  segment net=/BAT_SW layer=F.Cu start=(60.000, 74.000) end=(63.000, 75.000) width=1.000 distance=1.000
  segment net=/BUCK_IN layer=F.Cu start=(63.950, 77.000) end=(65.500, 77.000) width=1.000 distance=1.379
  segment net=/BUCK_IN layer=F.Cu start=(63.950, 77.000) end=(58.000, 87.000) width=1.000 distance=1.379
  segment net=/Q1_GATE layer=F.Cu start=(62.050, 77.000) end=(61.650, 78.500) width=0.250 distance=1.379
  segment net=/BUCK_IN layer=F.Cu start=(65.500, 77.000) end=(65.500, 61.000) width=1.000 distance=2.693
  segment net=/Q1_GATE layer=B.Cu start=(61.650, 78.500) end=(56.500, 78.500) width=0.250 distance=2.841
  via net=/Q1_GATE at=(61.650, 78.500) diameter=0.600 drill=0.300 distance=2.841
  segment net=/BAT_SW layer=F.Cu start=(56.500, 76.000) end=(60.000, 74.000) width=1.000 distance=3.606
  segment net=/5V_SYS layer=B.Cu start=(63.000, 82.000) end=(63.000, 87.000) width=0.800 distance=6.000
  segment net=/5V_SYS layer=B.Cu start=(73.000, 82.000) end=(63.000, 82.000) width=0.800 distance=6.000
  segment net=/BAT_SW layer=F.Cu start=(53.500, 76.000) end=(56.500, 76.000) width=1.000 distance=6.500
  segment net=/BUCK_IN layer=F.Cu start=(65.500, 70.000) end=(75.000, 70.000) width=0.250 distance=6.500
  segment net=/BUCK_IN layer=F.Cu start=(62.500, 67.725) end=(65.500, 70.000) width=0.250 distance=6.500
  segment net=/Q1_GATE layer=B.Cu start=(56.500, 78.500) end=(56.500, 69.000) width=0.250 distance=6.964
  segment net=/5V_SYS layer=B.Cu start=(68.000, 82.000) end=(68.000, 87.000) width=0.800 distance=7.810
zones whose bounding box contains Q1 reference point:
  net=/GND layers=B.Cu clearance=0.200 min_thickness=0.250
board min_clearance=0.200

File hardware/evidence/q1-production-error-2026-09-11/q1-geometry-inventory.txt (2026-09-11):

board=hardware/esp32-e220.kicad_pcb
Q1 footprint=Diodes_DMP3130LQ-7_SOT23 position=(63.000, 76.000) rotation=0.000 layer=F.Cu
Q1 pads:
  pad=1 net=/Q1_GATE position=(61.650, 77.000) size=(0.800, 0.900) rotation=0.000
  pad=2 net=/BUCK_IN position=(64.350, 77.000) size=(0.800, 0.900) rotation=0.000
  pad=3 net=/BAT_SW position=(63.000, 75.000) size=(0.800, 0.900) rotation=0.000
nearby footprints (reference point within 12 mm):
  ref=R2 footprint=Resistor_0603_1608Metric position=(62.500, 67.000) rotation=90.000 distance=9.014
  ref=R1 footprint=Resistor_0603_1608Metric position=(58.500, 67.000) rotation=90.000 distance=10.062
  ref=TP4 footprint=TestPoint_THT_1p0mm_PROTOTYPE position=(63.000, 87.000) rotation=0.000 distance=11.000
  ref=J8 footprint=JST_B2B-XH-A_1x02_P2.50mm_THT position=(51.000, 76.000) rotation=0.000 distance=12.000
copper items with an endpoint/position within 8 mm of Q1:
  segment net=/BAT_SW layer=F.Cu start=(60.000, 74.000) end=(63.000, 75.000) width=1.000 distance=1.000
  segment net=/BUCK_IN layer=F.Cu start=(64.350, 77.000) end=(65.500, 77.000) width=1.000 distance=1.680
  segment net=/BUCK_IN layer=F.Cu start=(64.350, 77.000) end=(58.000, 87.000) width=1.000 distance=1.680
  segment net=/Q1_GATE layer=F.Cu start=(61.650, 77.000) end=(61.650, 78.500) width=0.250 distance=1.680
  segment net=/BUCK_IN layer=F.Cu start=(65.500, 77.000) end=(65.500, 61.000) width=1.000 distance=2.693
  segment net=/Q1_GATE layer=B.Cu start=(61.650, 78.500) end=(56.500, 78.500) width=0.250 distance=2.841
  via net=/Q1_GATE at=(61.650, 78.500) diameter=0.600 drill=0.300 distance=2.841
  segment net=/BAT_SW layer=F.Cu start=(56.500, 76.000) end=(60.000, 74.000) width=1.000 distance=3.606
  segment net=/5V_SYS layer=B.Cu start=(63.000, 82.000) end=(63.000, 87.000) width=0.800 distance=6.000
  segment net=/5V_SYS layer=B.Cu start=(73.000, 82.000) end=(63.000, 82.000) width=0.800 distance=6.000
  segment net=/BAT_SW layer=F.Cu start=(53.500, 76.000) end=(56.500, 76.000) width=1.000 distance=6.500
  segment net=/BUCK_IN layer=F.Cu start=(65.500, 70.000) end=(75.000, 70.000) width=0.250 distance=6.500
  segment net=/BUCK_IN layer=F.Cu start=(62.500, 67.725) end=(65.500, 70.000) width=0.250 distance=6.500
  segment net=/Q1_GATE layer=B.Cu start=(56.500, 78.500) end=(56.500, 69.000) width=0.250 distance=6.964
  segment net=/5V_SYS layer=B.Cu start=(68.000, 82.000) end=(68.000, 87.000) width=0.800 distance=7.810
zones whose bounding box contains Q1 reference point:
  net=/GND layers=B.Cu clearance=0.200 min_thickness=0.250
board min_clearance=0.200

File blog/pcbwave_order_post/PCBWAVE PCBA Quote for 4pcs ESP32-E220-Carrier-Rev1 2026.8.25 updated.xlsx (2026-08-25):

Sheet: Total
Quotation
Vendor: PCBWAVE |  | Customer: |  | Customer Address |  | PCBWAVE Address
Contact Person: Wahi |  | Contact Person: |  | Russia |  | B Building，No.4, Industry Centre Road，Jiangbian Community, Baoan, Shenzhen, Guangdong province, China, 518105.
Tel: +86 755-23204330 |  | Tel:
Email: service1@pcbwave.com |  | Email:
Payment Method: Sberbank/Bancard/paypal/Alipay |  | Date: 2026/8/25
If there is any problem, please feel free to contact with me.
For PCB Fabricate
Project Name | Layers | Dimension/mm | Thickness/mm | Surface Finished | Solder Mask | Silkscreen | Copper Weight | Different Design | Qty. | Quotation/$ | Remark
ESP32-E220-Carrier-Rev1 | 2 | 145*90mm | 1.6mm | HASL LEAD FREE | black | White | 1oz | 1 | 5 | $19.48 | FR4 material
Stencil |  |  |  |  |  |  |  |  | 1 | $12.00 | for soldering
 |  |  |  |  |  |  |  |  | Total: | $31.48
For PCB Assembly
Project Name | Specifications |  | Qty of boards | Quotation | Remark
ESP32-E220-Carrier-Rev1 | Unique Parts | 25 | 4 | $80.00
 | Number of Components | 30
 | SMD pads | 66
 | THT pads | 47
 |  |  | Total: | $80.00
Components
Project Name | Unit Price | Remark
ESP32-E220-Carrier-Rev1 | $109.92 | for 4pcs
Total: | $109.92
Flashing&Testing
Project Name | Price | Remark
ESP32-E220-Carrier-Rev1 | $0.00 | no testing
Total: | $0.00
Shipping
Products | Shipping Method | Weight/kg | Quotation | Remark
PCBAs | Commercial Express-TJ | 0.8kg | $8.74 | 1-2 months
 |  | Total: | $8.74
 |  |  |  |  |  | Total |  | US$230.14 | for 5pcs PCB but only solder 4pcs

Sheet: BOM
Part# | Designator | Value | Description | Package | Notes | Quantity | MPN | SMT | THT | Original | Unit Price (4pcs) | Total Price (4pcs) | PCBWAVE NOTE
1 | R1 | 100k 1% | 100 kΩ resistor, 1%, 0603 | 0603 / 1608 | Any reputable 0603 100k 1% equivalent | 1 | APPROVED_GENERIC | 2 |  | N | $0.03 | $0.03
2 | R8,R9 | 10k 1% | 10 kΩ resistor, 1%, 0603 | 0603 / 1608 | Any reputable 0603 10k 1% equivalent | 2 | APPROVED_GENERIC | 4 |  | N | $0.03 | $0.06
3 | F1 | 1812L200/16 | Resettable PPTC fuse | 1812 / 4532 | Littelfuse | 1 | 1812L200/16 | 2 |  | Y | $0.30 | $0.30 | we quoted 1812L200/16DR, pls confirm
4 | R2 | 1M 1% | 1 MΩ resistor, 1%, 0603 | 0603 / 1608 | Any reputable 0603 1M 1% equivalent | 1 | APPROVED_GENERIC | 2 |  | N | $0.03 | $0.03
5 | J4,J8 | B2B-XH-A | JST XH vertical 2-pin board header | JST XH 1x02 2.50mm THT | JST | 2 | B2B-XH-A |  | 4 | Y | $0.06 | $0.12 | we quoted B2B-XH-A(LF)(SN), pls ocnfirm
6 | Q1 | DMP3130LQ-7 | P-channel MOSFET | SOT-23 | Diodes Incorporated | 1 | DMP3130LQ-7 | 3 |  | Y | $0.54 | $0.54
7 | J3 | E220 socket | Female carrier socket for E220 module | 1x07 2.54mm THT | Samtec socket only; DO NOT install E220 module | 1 | SSW-107-02-G-S |  | 7 | Y | $2.75 | $2.75
8 | C4 | 3.3nF | MLCC capacitor | 0603 / 1608 | Murata | 1 | GRM1885C1H332JA01D | 2 |  | Y | $0.23 | $0.23
9 | C5 | 10uF | MLCC capacitor | 0603 / 1608 | Murata | 1 | GRM188R61A106MAALD | 2 |  | Y | $0.45 | $0.45
10 | C8 | 100nF | MLCC capacitor | 0603 / 1608 | Murata | 1 | GRM188R71C104KA01D | 2 |  | Y | $0.14 | $0.14
11 | C2,C6,C7 | 100nF | MLCC capacitor | 0603 / 1608 | Murata | 3 | GRM188R71C104KA01D | 6 |  | Y | $0.15 | $0.45
12 | C3 | 22uF | MLCC capacitor | 0805 / 2012 | Murata | 1 | GRM21BR61A226ME44L | 2 |  | Y | $0.26 | $0.26
13 | C9,C10 | 10uF | MLCC capacitor | 0805 / 2012 | Murata | 2 | GRM21BR61E106KA73L | 4 |  | Y | $0.12 | $0.24
14 | C1 | 10uF | MLCC capacitor | 0805 / 2012 | Murata | 1 | GRM21BR61E106KA73L | 2 |  | Y | $0.12 | $0.12
15 | R3 | 10k 1% | Resistor, 1% | 0603 / 1608 | Yageo | 1 | RC0603FR-0710KL | 2 |  | Y | $0.15 | $0.15
16 | R4 | 3.3k 1% | Resistor, 1% | 0603 / 1608 | Yageo | 1 | RC0603FR-073K3L | 2 |  | Y | $0.15 | $0.15
17 | D3 | SMBJ10CA | Bidirectional TVS diode | SMB / DO-214AA | Littelfuse | 1 | SMBJ10CA | 2 |  | Y | $0.15 | $0.15
18 | U3 | SN74AHCT1G125DBVR | Single bus buffer / level shifter | SOT-23-5 / DBV | Texas Instruments | 1 | SN74AHCT1G125DBVR | 5 |  | Y | $0.19 | $0.19
19 | J5 | OLED socket | Female carrier socket for OLED module | 1x04 2.54mm THT | Samtec socket only; DO NOT install OLED module | 1 | SSW-104-02-G-S |  | 4 | Y | $2.00 | $2.00
20 | J1 | ESP32 left socket | Female carrier socket for ESP32 DevKit | 1x15 2.54mm THT | Samtec socket only; DO NOT install ESP32 module | 1 | SSW-115-02-G-S |  | 15 | Y | $5.46 | $5.46
21 | J2 | ESP32 right socket | Female carrier socket for ESP32 DevKit | 1x15 2.54mm THT | Samtec socket only; DO NOT install ESP32 module | 1 | SSW-115-02-G-S |  | 15 | Y | $5.46 | $5.46
22 | U4 | TLV1117LV33DCYR | 3.3 V linear regulator | SOT-223 / DCY | Texas Instruments | 1 | TLV1117LV33DCYR | 4 |  | Y | $0.51 | $0.51
23 | U1 | TPS62133RGT | 3 A step-down converter | QFN-16 + EP / RGT | Texas Instruments | 1 | TPS62133RGT | 16 |  | Y | $1.69 | $1.69 | we quoted TPS62133RGTR, pls confirm
24 | JP1 | 2-pin header | DEVKIT_PWR jumper header | 1x02 2.54mm THT | Samtec; shunt SNT-100-BK-G supplied separately/manual | 1 | TSW-102-07-G-S |  | 2 | Y | $0.35 | $0.35
25 | L1 | 2.2uH | Shielded power inductor | XFL4020 | Coilcraft | 1 | XFL4020-222MEB | 2 |  | Y | $5.27 | $5.27 | changed to XGL4020-222MEC, pls confirm
26 | JP1 removable shunt |  |  |  |  | 1 | SNT‑100‑BK‑G |  |  | Y | $0.38 | $0.38 | do need to solder on PCB, plugged into JP1
 |  |  |  |  |  | 31 |  | 66 | 47 |  | $26.97 | $27.48

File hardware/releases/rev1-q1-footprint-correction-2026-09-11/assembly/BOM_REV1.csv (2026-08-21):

Item | Qty | References | Value | Manufacturer | MPN | Footprint | AssemblyClass | ProcurementPolicy | Notes
1 | 1 | R1 | 100k 1% |  |  | Resistor_0603_1608Metric | PCBA_POPULATE | APPROVED_GENERIC
2 | 2 | R8, R9 | 10k 1% |  |  | Resistor_0603_1608Metric | PCBA_POPULATE | APPROVED_GENERIC
3 | 1 | F1 | 1812L200/16 | Littelfuse | 1812L200/16 | Littelfuse_1812L200_16_4532Metric | PCBA_POPULATE | EXACT_MPN
4 | 1 | R2 | 1M 1% |  |  | Resistor_0603_1608Metric | PCBA_POPULATE | APPROVED_GENERIC
5 | 2 | J4, J8 | B2B-XH-A | JST | B2B-XH-A | JST_B2B-XH-A_1x02_P2.50mm_THT | PCBA_POPULATE | EXACT_MPN
6 | 1 | Q1 | DMP3130LQ-7 | Diodes Incorporated | DMP3130LQ-7 | Diodes_DMP3130LQ-7_SOT23 | PCBA_POPULATE | EXACT_MPN
7 | 1 | J3 | E220-400T22D / E220-900T22D SOCKET | Samtec | SSW-107-02-G-S | E220_T22D_Socket_400_900 | PCBA_POPULATE | EXACT_MPN | E220 carrier socket, not E220 module
8 | 1 | C4 | GRM1885C1H332JA01D | Murata | GRM1885C1H332JA01D | Murata_GRM188_1608Metric | PCBA_POPULATE | EXACT_MPN
9 | 1 | C5 | GRM188R61A106MAAL | Murata | GRM188R61A106MAAL | Murata_GRM188_1608Metric | PCBA_POPULATE | EXACT_MPN
10 | 1 | C8 | GRM188R71C104KA01D | Murata | GRM188R71C104KA01D | Carrier:Murata_GRM188_1608Metric | PCBA_POPULATE | EXACT_MPN
11 | 3 | C2, C6, C7 | GRM188R71C104KA01D | Murata | GRM188R71C104KA01D | Murata_GRM188_1608Metric | PCBA_POPULATE | EXACT_MPN
12 | 1 | C3 | GRM21BR61A226ME44 | Murata | GRM21BR61A226ME44 | Murata_GRM21_2012Metric | PCBA_POPULATE | EXACT_MPN
13 | 2 | C10, C9 | GRM21BR61E106KA73 | Murata | GRM21BR61E106KA73 | Carrier:Murata_GRM21_2012Metric | PCBA_POPULATE | EXACT_MPN
14 | 1 | C1 | GRM21BR61E106KA73 | Murata | GRM21BR61E106KA73 | Murata_GRM21_2012Metric | PCBA_POPULATE | EXACT_MPN
15 | 1 | R3 | RC0603FR-0710KL | Yageo | RC0603FR-0710KL | Carrier:Resistor_0603_1608Metric | PCBA_POPULATE | EXACT_MPN
16 | 1 | R4 | RC0603FR-073K3L | Yageo | RC0603FR-073K3L | Carrier:Resistor_0603_1608Metric | PCBA_POPULATE | EXACT_MPN
17 | 1 | D3 | SMBJ10CA | Littelfuse | SMBJ10CA | Littelfuse_SMBJ10CA_DO214AA | PCBA_POPULATE | EXACT_MPN
18 | 1 | U3 | SN74AHCT1G125DBVR | Texas Instruments | SN74AHCT1G125DBVR | TI_SN74AHCT1G125DBVR_SOT23-5 | PCBA_POPULATE | EXACT_MPN
19 | 1 | J5 | SSW-104-02-G-S | Samtec | SSW-104-02-G-S | Samtec_SSW_1x04_P2.54mm_THT | PCBA_POPULATE | EXACT_MPN | OLED carrier socket, not OLED module
20 | 1 | J1 | SSW-115-02-G-S DEVKIT LEFT | Samtec | SSW-115-02-G-S | Samtec_SSW_1x15_P2.54mm_THT | PCBA_POPULATE | EXACT_MPN | ESP32 carrier socket, not module
21 | 1 | J2 | SSW-115-02-G-S DEVKIT RIGHT | Samtec | SSW-115-02-G-S | Samtec_SSW_1x15_P2.54mm_THT | PCBA_POPULATE | EXACT_MPN | ESP32 carrier socket, not module
22 | 1 | U4 | TLV1117LV33DCYR | Texas Instruments | TLV1117LV33DCYR | Package_TO_SOT_SMD:SOT-223-3_TabPin2 | PCBA_POPULATE | EXACT_MPN
23 | 1 | U1 | TPS62133RGT | Texas Instruments | TPS62133RGT | TI_TPS62133RGT_RGT0016C | PCBA_POPULATE | EXACT_MPN
24 | 1 | JP1 | TSW-102-07-G-S + SNT-100-BK-G | Samtec | TSW-102-07-G-S | Connector_PinHeader_2.54mm:PinHeader_1x02_P2.54mm_Vertical | PCBA_POPULATE | EXACT_MPN | 2-pin header only
25 | 1 | L1 | XFL4020-222MEB | Coilcraft | XFL4020-222MEB | Coilcraft_XFL4020-222MEB | PCBA_POPULATE | EXACT_MPN

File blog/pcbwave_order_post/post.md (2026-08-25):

# Как я отправил свою плату на завод: от Gerber до оплаты первой партии PCBA

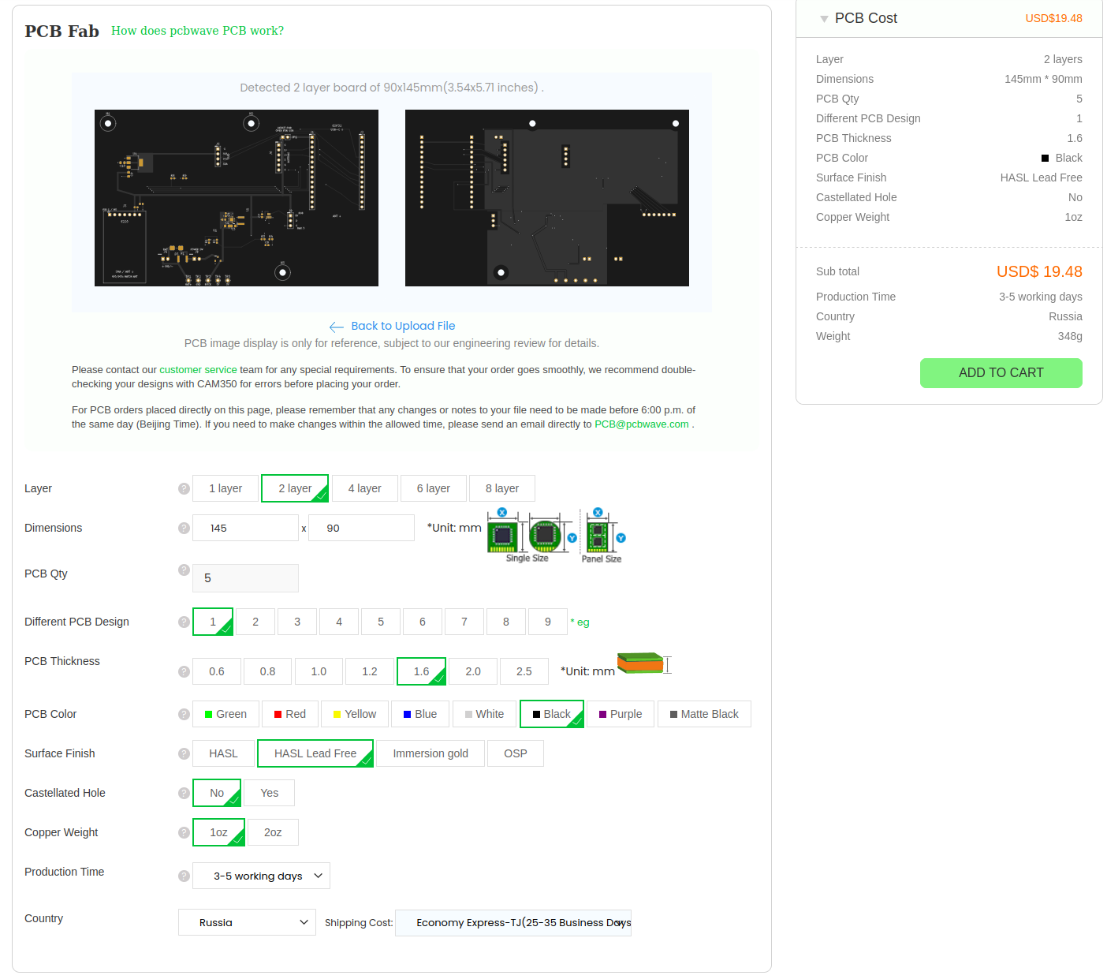
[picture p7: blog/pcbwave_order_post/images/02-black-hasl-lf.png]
Чёрная плата в онлайн-калькуляторе PCBWAVE


В прошлой части я остановился на моменте, когда плата **ESP32-E220-Carrier-Rev1** наконец перестала меняться каждый вечер, прошла проверки, а из KiCad получился нормальный производственный пакет.

Но есть одна неприятная особенность проектирования электроники: пока файл лежит у тебя на диске, он может быть идеальным сколько угодно.

Настоящая проверка начинается, когда этот файл отправляется на завод.

Поэтому следующий этап у проекта был довольно прозаичный: выбрать производителя, объяснить ему, что именно я хочу получить, пережить вопросы по компонентам, согласовать замены и в конце концов нажать кнопку оплаты.

В итоге заказ ушёл в PCBWAVE: **5 печатных плат, из них 4 с полной заводской сборкой**. Пятая останется голой — на случай экспериментов, ремонта, проверки посадочных мест или если мне внезапно захочется что-нибудь допаять руками.

И вот процесс заказа оказался интереснее, чем я ожидал.

## Сначала — просто посчитать голые платы

Первым делом я загрузил Gerber-файлы в обычный калькулятор PCBWAVE.

Сайт сам распознал:

**2 слоя, 145×90 мм, одна конструкция платы.**

Дальше выставил то, что мы уже зафиксировали при проектировании: FR-4, толщина 1,6 мм, медь 1 oz, пять экземпляров, без металлизированных вырезов по краю.

Отдельно хотелось чёрную маску. Не потому что она как-то улучшает электрические характеристики. Просто если уж несколько недель мучить плату вместе с нейросетями, пусть хотя бы выглядит красиво :)

Сначала я поставил иммерсионное золото.

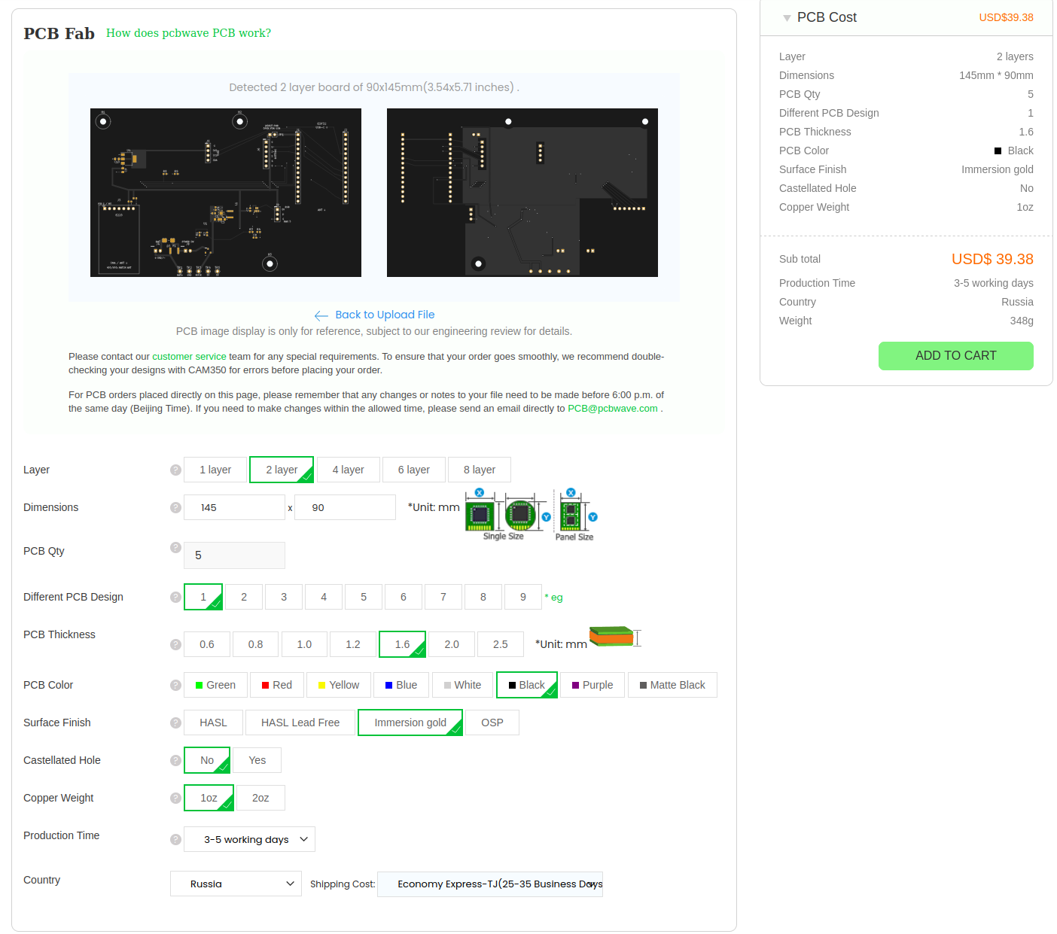
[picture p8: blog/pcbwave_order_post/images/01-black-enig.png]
Чёрная маска и иммерсионное золото


Пять плат получались примерно в **$39,38**.

Потом переключил покрытие на **HASL Lead Free** — бессвинцовое выравнивание горячим воздухом.

Чёрная маска и HASL Lead Free

Цена сразу упала до **$19,48**.

То есть иммерсионное золото добавляло примерно двадцать долларов практически на ровном месте. Для серийного изделия или платы с очень мелким шагом я бы ещё подумал, но для первой ревизии смысла переплачивать не увидел.

Чёрная маска при этом цену не изменила.

На ней и остановился: **чёрная плата, белая маркировка, HASL Lead Free**.

## А потом оказалось, что «цена платы» — это самая простая часть

У PCBWAVE есть отдельный калькулятор сборки.

Я указал четыре собираемых платы, примерно посчитал количество типов компонентов, самих деталей, контактных площадок поверхностного монтажа и выводов компонентов, которые паяются в отверстия.

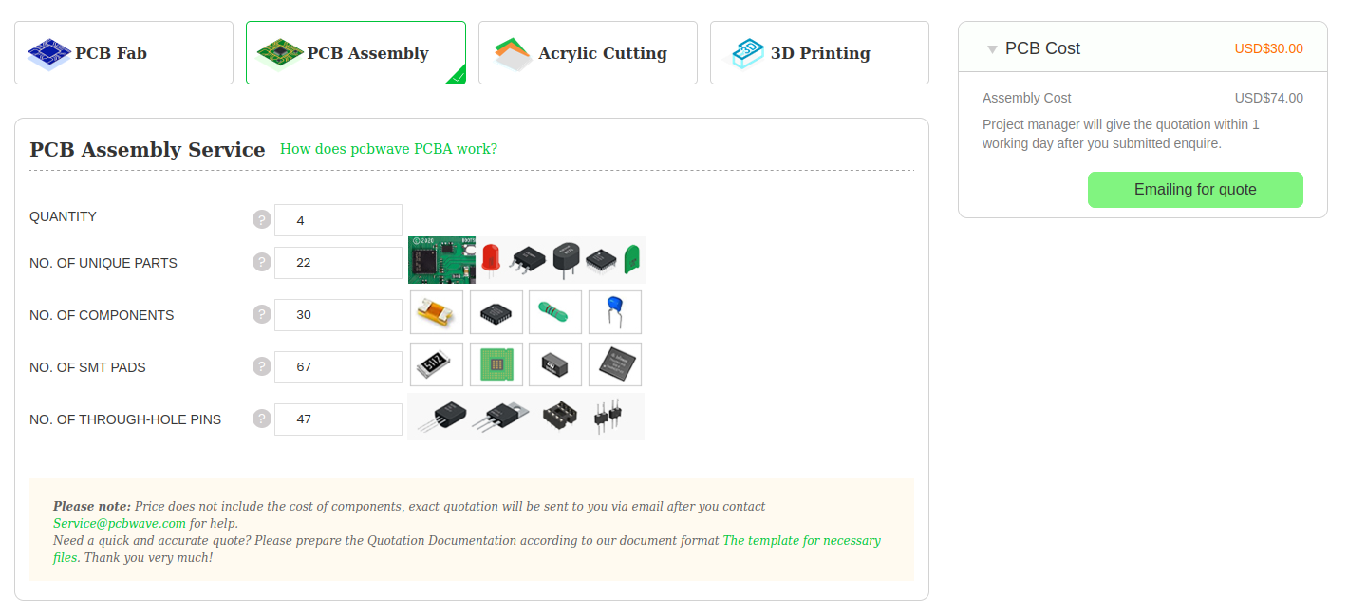
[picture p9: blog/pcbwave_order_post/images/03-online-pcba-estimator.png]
Онлайн-калькулятор сборки


На этом этапе сайт показывал около **$74 за сборку**.

Выглядит приятно.

Но прямо под формой написано главное: **стоимость компонентов сюда не входит, точный расчёт делается менеджером по запросу**.

То есть веб-калькулятор в случае PCBA — это скорее способ понять порядок цифр. Реальная работа начинается после письма.

И это, кстати, важный момент. В предварительную форму я вводил **22 типа компонентов, 30 деталей, 67 площадок поверхностного монтажа и 47 выводов в отверстия**. В финальном расчёте завода получилось уже **25 типов компонентов, те же 30 устанавливаемых деталей, 66 площадок поверхностного монтажа и 47 выводов**.

Ничего страшного тут нет. Просто завод пересчитал всё по своей логике и по реальной спецификации, а не по моей прикидке в форме.

## Самое важное — не Gerber, а объяснить заводу, что именно надо собирать

У этой платы есть особенность: это **плата-носитель**.

ESP32 DevKit, E220 и OLED завод устанавливать не должен. Я вставлю их сам после получения.

А вот женские разъёмы под них, наоборот, должны быть установлены на заводе.

Если просто отправить спецификацию без пояснений, тут очень легко получить не то, что задумывалось.

Поэтому к запросу ушёл отдельный пакет для расчёта. В нём были Gerber-файлы, спецификация компонентов, файл координат установки, список компонентов, которые паяются в отверстия, перечень того, что устанавливать не нужно, сборочные примечания и чертежи.

Особенно подробно расписал несколько вещей:

J1/J2 — завод припаивает две 15-контактные розетки Samtec под ESP32.  
J3 — завод припаивает розетку под E220.  
J5 — завод припаивает розетку под OLED.  
Сами ESP32, E220 и OLED **не поставляются и не устанавливаются**.

J6 и J9 — это просто металлизированные отверстия для будущих проводов. Никаких гребёнок туда ставить не надо.

TP1…TP5 — тоже только отверстия для щупа. Никаких штырей.

R10 и R11 вообще не имеют посадочных мест на плате и оставлены как опциональные элементы в документации.

Три отверстия H1/H2/H3 — обычные 3,2-миллиметровые неметаллизированные крепёжные отверстия.

Звучит как занудство. Но лучше один раз написать пять лишних строк в письме, чем потом получить четыре аккуратно собранные платы с четырьмя аккуратно припаянными лишними разъёмами.

## И тут снова пригодился ИИ

На этапе проектирования ИИ в основном спорил со мной про разводку, питание, зоны земли и посадочные места.

На этапе заказа его роль неожиданно изменилась.

Сначала мы действительно подготовили пакет для запроса цены: заполнили шаблон PCBWAVE исходными данными из нашей спецификации, приложили Gerber, координаты установки, список выводных компонентов, список того, что устанавливать не надо, и сборочные примечания.

Но это была именно **исходная заявка на расчёт**, а не таблица согласованных замен.

Самое интересное началось уже после того, как PCBWAVE вернул свой расчёт.

В присланной ими таблице появилась отдельная колонка с комментариями завода. По части строк они прямо написали: вот такой MPN мы реально можем поставить, пожалуйста, подтвердите. А по L1 сначала вообще стояло **NO STOCK**.

В письме менеджер отдельно объяснил, что позиции с отметкой `N` означают замену на компонент другого производителя с теми же основными параметрами, попросил проверить выделенные строки и подтвердить предложенные MPN.

Вот тут ChatGPT пригодился уже совсем в другой роли.

Я отдавал ему присланную PCBWAVE таблицу, а мы построчно сравнивали её с исходной спецификацией: что является обычным вариантом исполнения той же детали, где изменился только заказной суффикс, где допустим любой нормальный резистор нужного номинала и допуска, а где нам действительно предлагают другой компонент и надо лезть в документацию производителя.

То есть решение о заменах появлялось не у нас заранее. **Завод сначала сообщил, что реально может купить, а мы уже проверяли и либо подтверждали, либо просили другой вариант.**

И это оказалось не менее полезно, чем помощь с самой схемой. На этом этапе ИИ был уже не столько «электронщиком», сколько техническим закупщиком и очень придирчивым вторым проверяющим переписки с производством.

## Первый нормальный расчёт от завода

Запрос отправил 21 августа.

Менеджера зовут Wahi. Он сразу написал, что занимается проектами для российских заказчиков, и пообещал прислать расчёт после выходных.

24 августа пришла первая полноценная смета, а 25-го — уточнённая.

Финальная разбивка получилась такая:

| Что | Цена |
| --- | ---: |
| 5 печатных плат | $19,48 |
| Трафарет | $12,00 |
| Сборка 4 плат | $80,00 |
| Компоненты для 4 плат | $109,92 |
| Доставка | $8,74 |
| **Итого по расчёту** | **$230,14** |

Прошивку и функциональное тестирование я не заказывал — в смете там стоит ноль. Логично: ESP32 и E220 всё равно приедут отдельно и будут вставляться уже мной.

По доставке в расчёте указан **Commercial Express-TJ**, масса около 0,8 кг и ориентир **1–2 месяца**. По переписке изготовление после подтверждения заказа оценили примерно в три недели.

То есть быстро эта история не закончится.

Но после нескольких недель проектирования ожидание посылки уже кажется самой простой частью :)

## Компоненты: где начинается самое интересное

Вот здесь реальный процесс особенно хорошо отличается от красивой схемы «отправил BOM — завод всё купил».

В первой присланной PCBWAVE таблице было несколько строк, которые они попросили подтвердить.

Для предохранителя F1 вместо базового `1812L200/16` они указали конкретный вариант `1812L200/16DR`.

Для двух разъёмов питания J4/J8 вместо короткого обозначения `B2B-XH-A` — полный заказной вариант `B2B-XH-A(LF)(SN)`.

Для преобразователя U1 вместо `TPS62133RGT` — `TPS62133RGTR`.

Это как раз те случаи, где нельзя пугаться каждого дополнительного символа в MPN, но и нельзя просто махнуть рукой. Мы проверили, что речь идёт о подходящих вариантах тех же компонентов, и подтвердили их.

С обычными резисторами всё было ещё проще. Для R1, R2, R8 и R9 в исходной спецификации и так было разрешено использовать качественные аналоги 0603 с нужным номиналом и допуском. PCBWAVE отдельно уточнил этот момент, а потом написал, что закупит резисторы с требуемыми параметрами.

А вот с катушкой L1 история была уже настоящей заменой.

В проекте стояла **Coilcraft XFL4020-222MEB, 2,2 мкГн**. В первой смете напротив неё завод написал просто:

**NO STOCK.**

То есть сначала никакой замены ещё не было — деталь просто выпала из расчёта.

После нашей переписки инженеры PCBWAVE предложили другой конкретный MPN:

**XGL4020-222MEC.**

Вот такую замену я уже не хотел подтверждать по принципу «ну почти одинаковое название».

Мы отдельно сравнили параметры и документацию Coilcraft. В итоге XGL4020 действительно оказался подходящей заменой для нашего преобразователя, причём по части токовых характеристик даже с большим запасом.

Только после этого я написал Wahi, что **XGL4020-222MEC для L1 согласован**.

После подтверждения они обновили таблицу и пересчитали стоимость компонентов.

Мне вообще нравится эта часть процесса. Ты вроде уже закончил проектировать плату, но проектирование на самом деле не заканчивается. Просто теперь новые инженерные решения начинают приходить с другой стороны — со склада и от закупщиков производителя.

## Как оплачивается индивидуальный заказ на $230 через товар стоимостью $1

После всех подтверждений Wahi написал примерно следующее:

стоимость обновлённого заказа — **$230,14**, а для оплаты надо открыть специальную позицию `PCB Assembly` стоимостью **$1** и купить **230 штук**.

Звучит великолепно.

Но на самом деле всё логично: это просто универсальная платёжная позиция для индивидуальных расчётов.

В поле `Project Manager` я указал **Wahi**, количество поставил **230**.

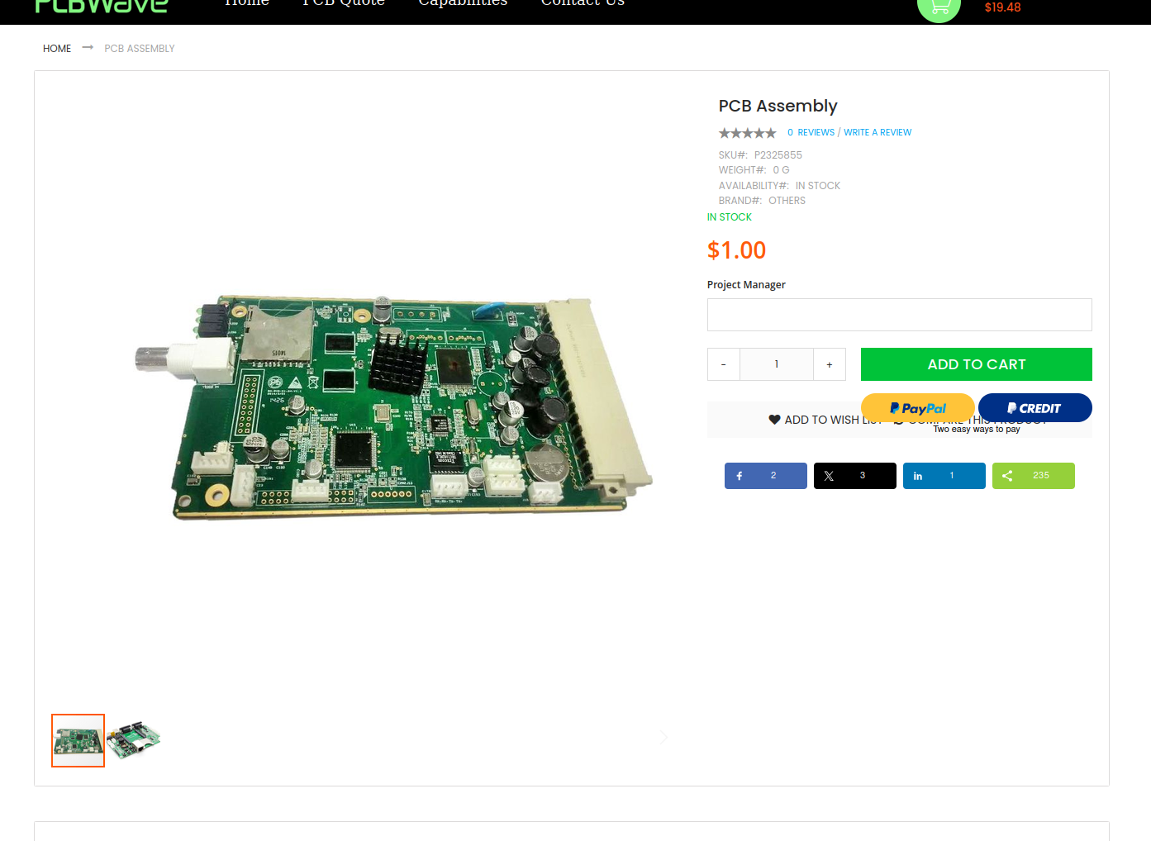
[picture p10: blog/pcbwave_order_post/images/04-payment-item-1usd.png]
Специальная позиция для ручной оплаты заказа


В корзине получилось ровно **$230**.

Правда, сайт сначала решил немного добавить драматизма и показал предварительный налог $57,50 — итог превратился в $287,50.

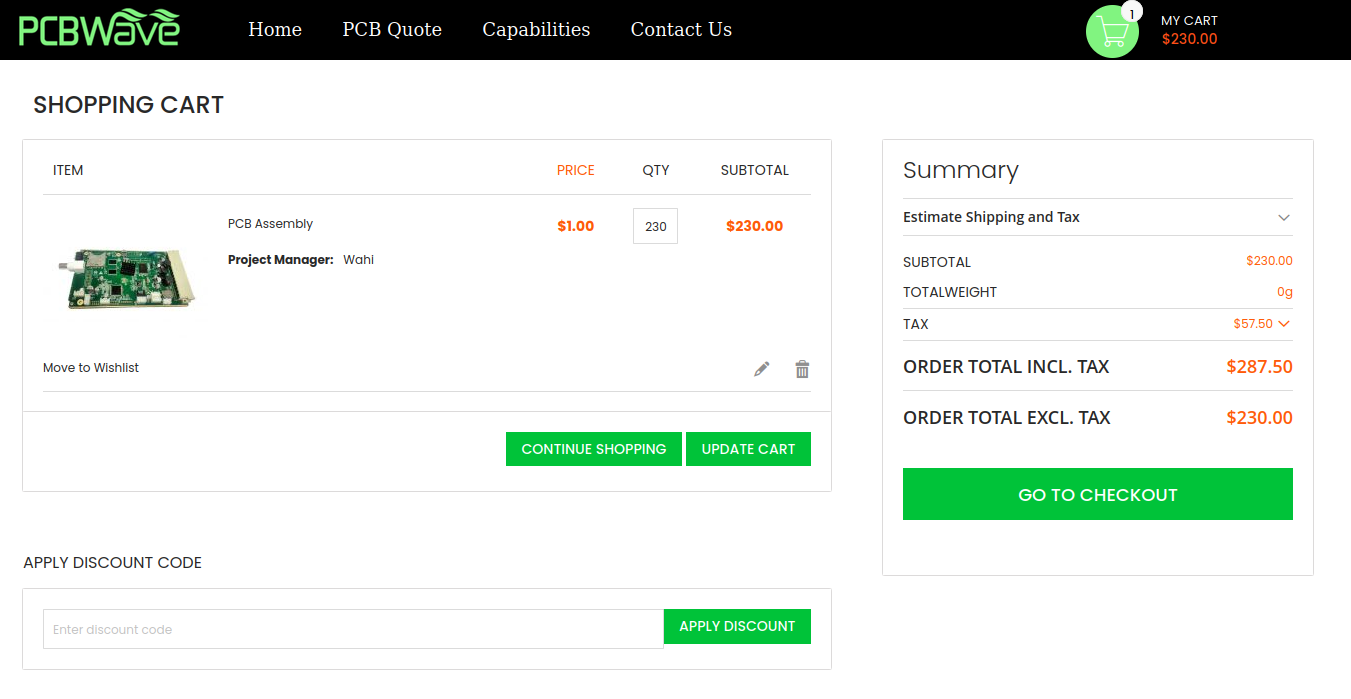
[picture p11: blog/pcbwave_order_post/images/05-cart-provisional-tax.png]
Корзина с предварительно посчитанным налогом


После перехода к оформлению и выбора страны всё вернулось к нормальной жизни.

Менеджер отдельно попросил выбрать **Free Shipping**, потому что $8,74 доставки уже сидят внутри согласованной суммы.

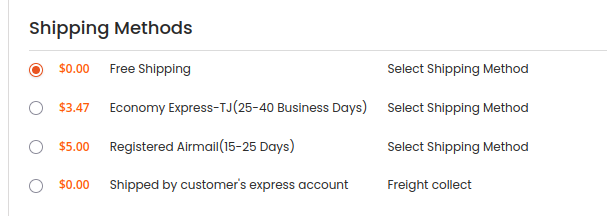
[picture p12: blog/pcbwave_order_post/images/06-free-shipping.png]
Доставка выбирается как Free Shipping, потому что она уже включена в расчёт


На странице оплаты итог снова был **$230**, без налога и без отдельной стоимости доставки.

Причём для российского заказа сайт предлагает вполне знакомые варианты оплаты, включая Сбербанк и карты «Мир».

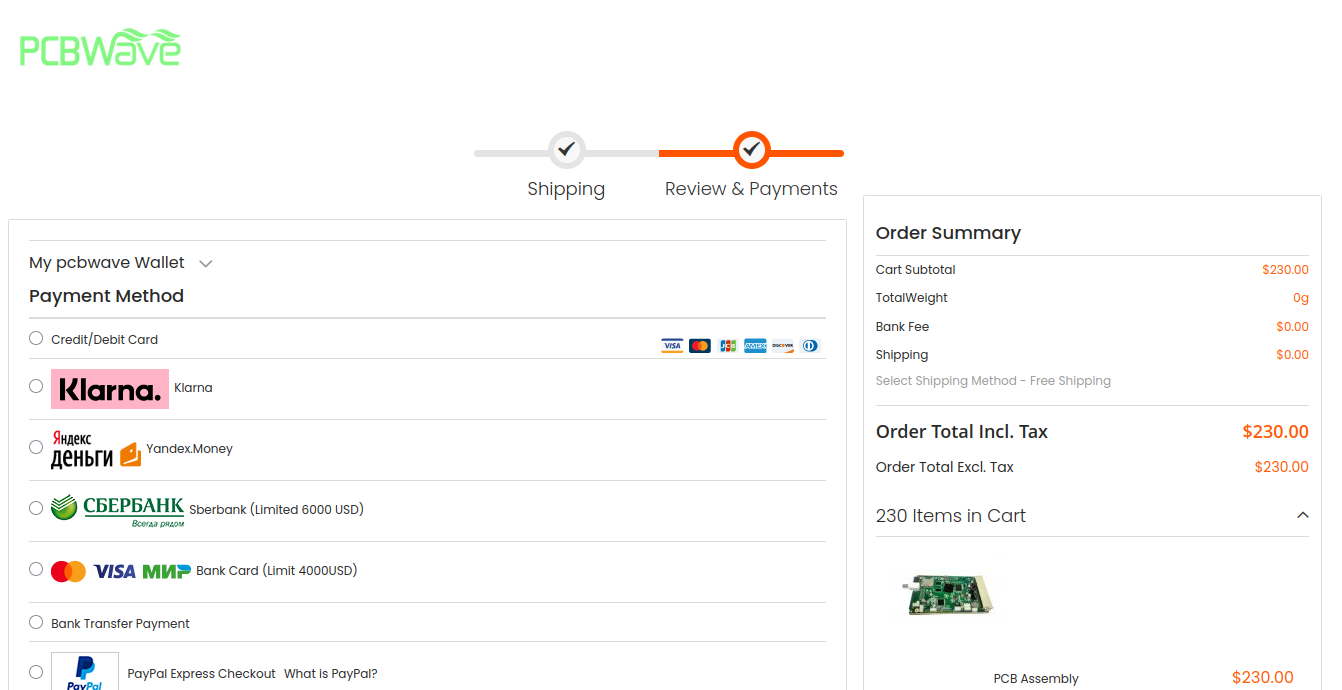
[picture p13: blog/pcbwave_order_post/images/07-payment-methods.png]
Экран оплаты


Оплату провёл через Сбербанк.

## И последний маленький квест от сайта

После оплаты заказ создался, менеджер указан правильно, количество — 230 условных единиц.

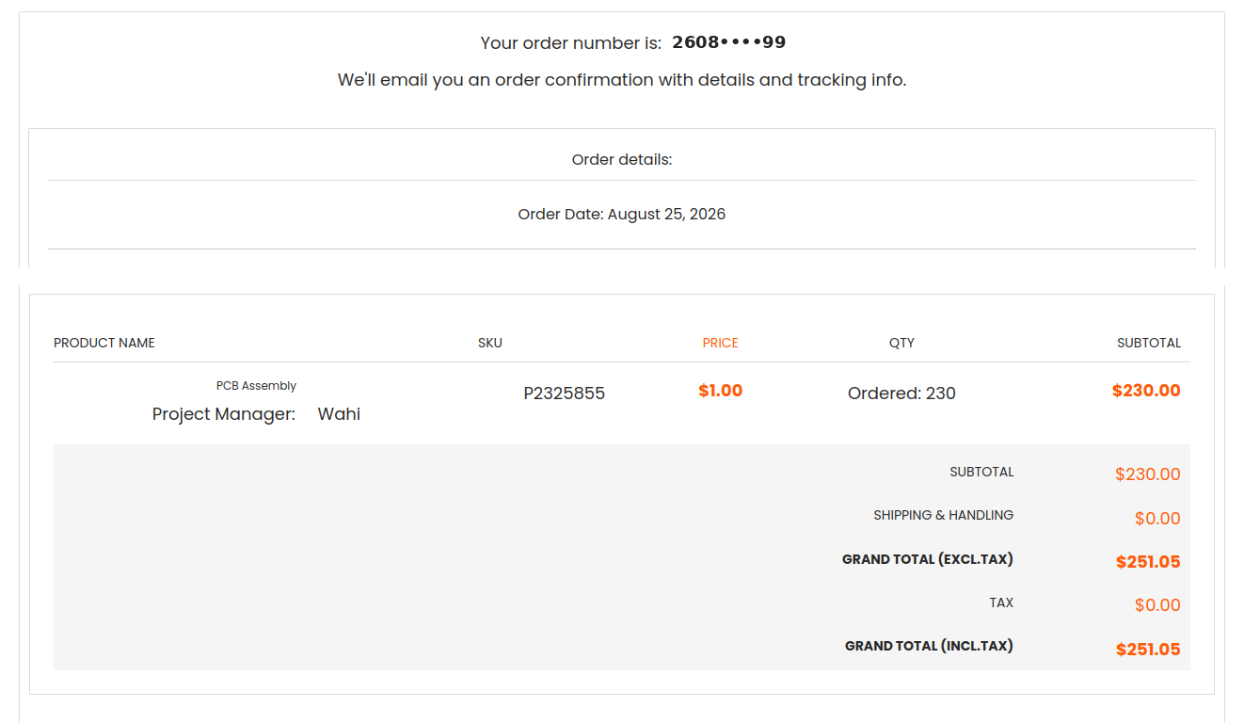
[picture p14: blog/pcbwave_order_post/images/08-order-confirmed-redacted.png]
Подтверждение заказа. Адрес и большая часть номера заказа на скриншоте скрыты перед публикацией


Но здесь есть странность, которую я пока не буду изображать понятной.

В строке товара остаётся **$230,00**, доставка — $0, налог — $0, а `Grand Total` в подтверждении почему-то показывает **$251,05**.

По самому экрану не видно, откуда взялись дополнительные $21,05. Возможно, это особенность конкретного способа оплаты или комиссии платёжного шлюза, но гадать не хочу.

Для истории проекта фиксирую как есть: согласованный расчёт PCBWAVE — **$230,14**, платёжная позиция на сайте — **$230**, а финальное подтверждение заказа показывает **$251,05**. Если выяснится точная причина, потом допишу.

Мне такой вариант нравится больше, чем делать вид, будто я понял логику чужого интернет-магазина :)

## Что в итоге заказано

На текущий момент оплачено производство **пяти ESP32-E220-Carrier-Rev1**.

Четыре платы должны прийти полностью собранными в части компонентов самой платы-носителя. Пятая — без сборки.

ESP32 DevKit, E220 и OLED я установлю сам.

После оплаты PCBWAVE попросил прислать номер заказа менеджеру, чтобы он связал платёж с нашей перепиской.

Номер отправил. Через некоторое время Wahi подтвердил, что платёж получен, и написал, что заказ запускают в производство.

То есть на этом месте уже можно поставить нормальную точку: **проект оплачен и передан в производство**.

Теперь остаётся ждать инженерную проверку, закупку компонентов, изготовление и сборку.

И я почти уверен, что до момента отправки завод ещё хотя бы раз задаст какой-нибудь вопрос. Если задаст — это даже хорошо. Гораздо приятнее получить письмо «уточните вот этот компонент», чем потом разглядывать четыре одинаково неправильно собранные платы.

## Что я понял после первого заказа PCBA

Главное открытие: заказать сборку платы — это не «загрузить Gerber и заплатить».

Gerber описывает только саму плату. Для нормальной сборки заводу надо ещё однозначно понять, **что поставить, что не поставить, какой компонент допустимо заменить, что является пользовательским разъёмом, что является просто отверстием и какие части устройства вообще не входят в сборку**.

И вот здесь вся предыдущая педантичность с производственным пакетом внезапно окупилась.

Когда завод спросил про замену L1, мне не пришлось вспоминать, почему там вообще стоит именно эта катушка. Когда менеджер пересчитал количество деталей, было с чем сравнить. Когда надо было объяснить J6, J9 и контрольные точки — уже существовал отдельный список того, что завод не должен устанавливать.

Наверное, именно в этот момент проект окончательно перестал быть «платой, которую мы нарисовали с нейросетями» и стал обычным инженерным изделием со спецификацией, закупкой, производством и логистикой.

А следующий пост, надеюсь, уже будет с фотографиями настоящих чёрных плат.

И вот там мы наконец узнаем главное:

**работает ли всё это в реальном мире.**

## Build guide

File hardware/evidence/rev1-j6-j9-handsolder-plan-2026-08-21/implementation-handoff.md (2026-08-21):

# J6/J9 hand-solder clearance implementation handoff

## SCOPE STATUS

`IMPLEMENTED — AWAITING INDEPENDENT IMPLEMENTATION REVIEW`

The active board is byte-for-byte identical to the reviewed temporary
candidate.  Active PCB SHA-256:

`9f15f061cd98cf069137ce9181a9edf8d9903167ee9641b9fa9af746eb992acd`

Named pre-transaction backup:

`50-active-pre-j6-j9-serviceability-a9fa9493.kicad_pcb`

## Implemented geometry

* `J6_HANDSOLDER_CLEARANCE`: native B.Cu copper-pour-only rule area,
  rectangle `(91.750, 15.750)` to `(96.250, 32.950)` mm. Tracks, vias,
  pads, and footprints remain allowed.
* J6.1 explicit GND branch: B.Cu, 0.80 mm, 3.00 mm,
  `(94.000, 18.000) -> (97.000, 18.000)`. It replaces only the released
  0.25-mm B.Cu segment `(94.000, 18.000) -> (104.000, 18.000)`.
* `J9_HANDSOLDER_CLEARANCE`: native B.Cu copper-pour-only rule area,
  rectangle `(97.750, 51.750)` to `(103.000, 61.330)` mm. Tracks, vias,
  pads, and footprints remain allowed.
* J9.3 explicit GND branch: B.Cu, 0.80 mm, 3.00 mm,
  `(100.000, 59.080) -> (97.000, 59.080)`.

Final counts: 37 footprints, 201 tracks, 58 vias, four copper zones, three
rule areas, two copper layers, 145 x 90 mm.

## Machine gates

* Pre-transaction released SHA: PASS (`a9fa9493...ffec0c`).
* Protected fast contract before and after: PASS.
* Full board contract: PASS.
* Native DRC: 0 violations, 0 unconnected items.
* ERC: 0 errors, 0 warnings.
* Schematic-PCB parity: PASS.
* Production metadata: PASS.
* Antenna exclusion and protected buck contract checks: PASS.
* J6.1 and J9.3 global-GND connectivity: PASS.
* Filled B.Cu GND island flags: four `false`; no isolated GND fill.

## Reproducibility and delta

`hardware/apply_j6_j9_handsolder_clearance.py` is the narrowly scoped,
SHA-gated authoritative transform from the released PCB.  Its regenerated
board matches the active implementation for footprints, segments, vias,
rule areas, filled zones, and graphics after non-geometric UUID identity is
ignored (`64-authoritative-reproduction-proof.json`: PASS).

`verify_authorized_delta.py`: PASS.  Apart from the two reviewed rule areas,
the two new explicit GND tracks, removal of the one superseded J6 GND
segment, and resulting zone-fill polygons, footprints, pads, vias, F.Cu,
unrelated B.Cu tracks, ordinary zone definitions, antenna rule area,
Edge.Cuts, silk, and schematic are unchanged.

## Retained and next gate

All J6/J9 signal nets, J9 5V and data routes, U3/J9 path, ESP32/E220/OLED
routing, protected buck geometry, U4, antenna exclusion, outline, placement,
silkscreen, and schematic are retained.

Next required independent gate:

`SCOPE VERDICT: REV1 J6/J9 SERVICEABILITY CORRECTION PASS`

`REVIEW PASS`

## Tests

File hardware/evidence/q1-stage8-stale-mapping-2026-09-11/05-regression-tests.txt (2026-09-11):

test_antenna_boundary_intersections (test_board_contract.BoardContractTests) ... ok
test_antenna_zone_enclosing_rectangle_fails (test_board_contract.BoardContractTests) ... ok
test_different_pad_numbers_not_compared (test_board_contract.BoardContractTests) ... ok
test_duplicate_netless_fails (test_board_contract.BoardContractTests) ... ok
test_duplicate_same_net_passes (test_board_contract.BoardContractTests) ... ok
test_json_result_schema (test_board_contract.BoardContractTests) ... ok
test_matching_rule_area_is_cross_checked (test_board_contract.BoardContractTests) ... ok
test_native_keepout_zone_is_not_copper_zone (test_board_contract.BoardContractTests) ... ok
test_npth_is_ignored (test_board_contract.BoardContractTests) ... ok
test_reference_is_required_for_protected_checkpoint (test_board_contract.BoardContractTests) ... ok
test_unrelated_rule_area_does_not_fail_antenna_check (test_board_contract.BoardContractTests) ... ok
test_q1_mapping_is_authoritative_and_used (test_stage8_q1_mapping.Stage8Q1MappingTests) ... ok

----------------------------------------------------------------------
Ran 12 tests in 0.005s

OK

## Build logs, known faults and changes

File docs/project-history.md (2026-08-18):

# Журнал проекта ESP32 + E220

Назначение: русскоязычная история для человека. Агенты не должны загружать этот файл как обычный рабочий контекст. Текущая английская сводка для них находится в `docs/agent-context.md`.

## Правило ведения

Записи сохраняют развитие решений, включая отменённые варианты. Более новая явно обозначенная активная запись имеет приоритет. Технические обозначения, MPN, имена цепей, команд и файлов оставляются без перевода.

## 2026-08-18 — проверка требований и компонентов

- Создан корневой проект реального наземного LoRa-приёмника.
- Проверены официальные документы Espressif, EBYTE, TI, WorldSemi, Murata, Littelfuse, Diodes Inc. и Coilcraft.
- Зафиксированы требования к ESP32, E220, OLED, WS2812, питанию, радиочастотной части и производству.
- Ранние варианты содержали отдельный ESP32-WROOM, USB-C вход, TUSB320 и электронный предохранитель. Эти варианты позднее отменены.

## Этап 2 — первоначальный выбор узлов

- Выбран E220-900T22D, затем интерфейс расширен до одного E220-400T22D или E220-900T22D.
- Для светодиода выбран WS2812B-V5 и буфер SN74AHCT1G125DBVR.
- Сформирован первый расчёт потребления и список неизвестных параметров.
- Посадочное место WS2812 намеренно оставлено неутверждённым до появления проверяемого рисунка площадок.

## Этап 3 — ранняя архитектура USB-C

- Рассматривались USB4105-GF-A, TUSB320LAIRWBR, TPS259630DDAR и защита линий CC.
- Несколько последовательных проверок выявили проблемы с обратным питанием, состоянием при токе по умолчанию (`Default Current`) и отсутствием подходящего вспомогательного питания защиты CC.
- Были проработаны TPD4S311, TLV70433 и логика разрешения электронного предохранителя.
- Эти решения корректно сохранены как история, но полностью отменены активной аккумуляторной Rev.1.

## Этап 4 — переход на съёмный ESP32 DevKit

- Отказались от отдельного голого ESP32 и его локального стабилизатора 3,3 В.
- Активным контроллером стал съёмный 30-выводный ESP32 DevKit с двумя рядами 1×15.
- Пользователь подтвердил порядок выводов и ограничение Rev.A: питание от несущей платы и USB-C DevKit используются раздельно.
- Созданы воспроизводимые файлы проекта KiCad и генератор схемы.

## Этап 5 — модуль E220 и схема

- Подтверждена общая семивыводная электрическая часть E220-400T22D/E220-900T22D.
- Добавлены подтяжки M0/M1 по 10 кОм и местная развязка 10 мкФ + 100 нФ.
- Исправлены ошибки ранних пользовательских символов, включая нумерацию диода и транзистора.
- Добавлены контрольные точки и необходимые защитные/питающие элементы действовавшей тогда архитектуры.
- ERC проходил без электрических ошибок; предупреждения по резерву OLED были видимыми и не скрывались.

## Rev.1 — переход на защищённый аккумулятор 2S

- Пользователь заменил всю входную архитектуру USB-C на внешний защищённый аккумулятор 2S, 6,0…8,4 В.
- Активная цепь стала `BAT_PLUS → F1 → BAT_FUSED → Q1 → BUCK_IN → TPS62133 → 5V_SYS`.
- Выбраны `1812L200/16`, `SMBJ10CA`, `DMP3130LQ-7`, `TPS62133RGT`, `XFL4020-222MEB` и C1…C4.
- Исправлена реальная ошибка ориентации P-MOS: Q1 D3=`BAT_FUSED`, S2=`BUCK_IN`, R2 от `BUCK_IN` к затвору.
- Установлен расчётный запас питания и обязательные тепловые/нагрузочные проверки.

## Rev.1 — подключение OLED

- J5 определён как съёмная розетка 1×4: GND, 3,3 В, SCL, SDA.
- Добавлены R10/R11 по 4,7 кОм как неустанавливаемые варианты подтяжек.
- Для OLED выделено консервативное проектное потребление 100 мА.
- Пользовательский чертёж уточнил плату 26×26 мм, расстояния отверстий и координаты выводов по X.
- Неизвестными остались координата ряда по Y, диаметр отверстий и полная геометрия стекла/шлейфа/вырезов.

## Этап 7 — библиотека посадочных мест

- Выбраны JST `B2B-XH-A` и Samtec `SSW-115/107/104-02-G-S`.
- Создан воспроизводимый генератор проектной библиотеки.
- Исправлены координаты периферийных площадок TPS62133 и апертура пасты EP 1,550×1,550 мм.
- Сверление Samtec приведено к официальным 1,040 мм.
- Добавлены проверенные посадочные места Coilcraft XFL4020 и Diodes DMP3130LQ.
- Площадки F1/D3/Murata/резисторов классифицированы как проектные IPC и требуют подтверждения сборщика.
- Официальные STEP/LIB EBYTE подтвердили общую механику 400/900 T22D; отверстия 8…10 оставлены ориентирами.

## Этап 7.1 — предварительное размещение

- Пользователь разрешил консервативное предварительное размещение без полного набора размеров клона ESP32.
- Использованы габариты ESP32 28×51 мм, E220 21×36 мм и OLED 26×26 мм.
- Создана нетрассированная механическая плата, затем исправлена геометрия TPS62133.

## Этап 8 — функциональное размещение

- Создан воспроизводимый `generate_stage8_placement.py`.
- Получена плата 145×90 мм с 33 устанавливаемыми посадочными местами, реальными цепями и без дорожек, переходных отверстий и заливок.
- R10/R11 и служебные PWR_FLAG явно классифицированы как элементы без посадочного места.
- Исправлено размещение силовой ячейки TPS62133, местной развязки E220 и элементов вне антенной области ESP32.
- Независимая проверка подтвердила возможность выхода ESP32/E220 и будущей нижней плоскости земли.

## Исправление соответствия схемы и платы

- Пользовательский проверяющий сначала показал 155 замечаний: имена цепей, значения, поля и отсутствующие посадочные места.
- Аудит отделил реальные расхождения от различий представления.
- Значения и свойства источника исправлены; R10/R11 явно получили `DNP` и `NO_FOOTPRINT_DNP`.
- Установлено правило имён цепей корневого листа с начальным `/`.
- Машинная проверка стала подтверждать 33/33 элемента и ноль реальных несоответствий площадок цепям.

## Исправление размещения перед трассировкой

- D3 перемещён ближе к J4/F1 для короткого местного импульсного возврата.
- C1/C2 развёрнуты к соответствующим входам U1.
- Сохранён короткий зазор U1–L1.
- Проверяющий выдал разрешение на геометрию трассировки с отложенными OLED и WS2812.

## Отклонённая полная трассировка

- Первая попытка развести всю плату породила десятки реальных пересечений, замыканий и нарушений зазоров.
- Попытка была правильно признана неудачной; подавление DRC не применялось.
- Полная разводка не была принята как исходная геометрия для следующих этапов.

## Пошаговая разводка силовой части

- Отдельно разведена входная защита J4/F1/D3/Q1/R1/R2 и получен чистый по DRC контрольный этап.
- Частично выполнены C1, C2, SW и связь L1–C3.
- Применены пять переходных отверстий, глобальные заливки отсутствовали.
- Попытки провести C4/SS/TR выявили местное геометрическое препятствие; неудачные варианты были откатаны.
- Независимая проверка признала силовую ячейку незавершённой из-за C4, VOS, FSW и длинных возвратов конденсаторов.

## Локальная переработка TPS62133

- Повторно проверена таблица выводов TPS62133 Rev.F; электрическая схема признана правильной.
- Сохранён этап A с прямыми верхними соединениями AGND/PGND к EP и нулём геометрических нарушений DRC.
- Отдельное перемещение C1 оказалось невозможно из-за старого переходного отверстия возврата C2.
- Совместный вариант C1/C2 пересёк обязательный выход AVIN; ограниченная местная заливка также дала реальные нарушения.
- Все неудачные варианты откатаны. Требуется новое совместное размещение U1/C1/C2/C3/C4/L1.

## Настройка агентов

- Разделены роли электрического инженера, физического трассировщика и независимого проверяющего.
- Добавлены англоязычные агенты проверки фактов и планирования трассировки.
- Введены контрольные этапы, границы отката и единые статусы.
- Рабочий контекст агентов сокращён и вынесен в `AGENTS.md` и `docs/agent-context.md`.
- Установлено постоянное языковое правило: агентские файлы — английские; человеческая документация — русская; технические идентификаторы не переводятся.

## Текущее состояние

- Электрическая схема утверждена; подтверждённой необходимости её менять нет.
- Входная защита разведена и сохраняется.
- Локальная силовая ячейка TPS62133 не принята и требует совместного нового плана.
- Глобальная плоскость земли и полная трассировка не разрешены.
- OLED и WS2812 сохраняют свои отложенные механические/посадочные вопросы.
- Производственные файлы не выпускаются до независимого разрешения.

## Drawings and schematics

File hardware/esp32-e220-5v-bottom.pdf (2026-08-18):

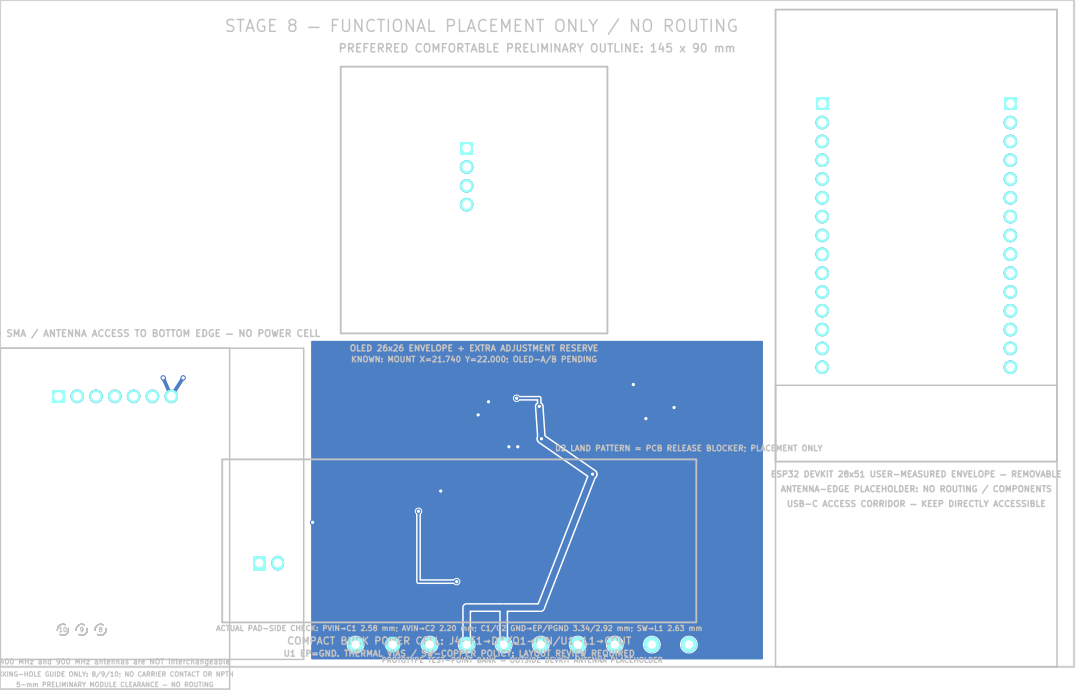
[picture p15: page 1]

PREFERRED COMFORTABLE PRELIMINARY OUTLINE: 145 x 90 mm STAGE 8 — FUNCTIONAL PLACEMENT ONLY / NO ROUTING

D2 LAND PATTERN = PCB RELEASE BLOCKER; PLACEMENT ONLY U1 EP=GND. THERMAL VIAS / SW-COPPER POLICY: LAYOUT REVIEW REQUIRED OLED 26x26 ENVELOPE + EXTRA ADJUSTMENT RESERVE

KNOWN: MOUNT X=21.740 Y=22.000; OLED-A/B PENDING

ESP32 DEVKIT 28x51 USER-MEASURED ENVELOPE — REMOVABLE

PROTOTYPE TEST-POINT BANK — OUTSIDE DEVKIT ANTENNA PLACEHOLDER

FIXING-HOLE GUIDE ONLY: 8/9/10; NO CARRIER CONTACT OR NPTH

5-mm PRELIMINARY MODULE CLEARANCE — NO ROUTING

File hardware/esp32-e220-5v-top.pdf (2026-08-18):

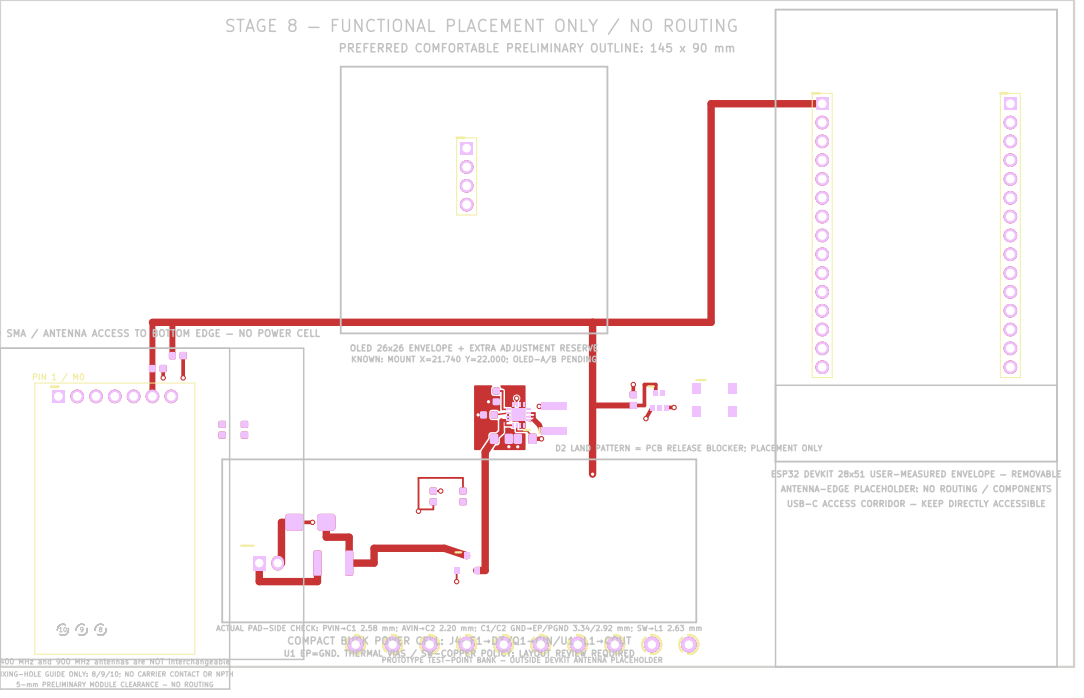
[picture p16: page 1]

PREFERRED COMFORTABLE PRELIMINARY OUTLINE: 145 x 90 mm STAGE 8 — FUNCTIONAL PLACEMENT ONLY / NO ROUTING

KNOWN: MOUNT X=21.740 Y=22.000; OLED-A/B PENDING

ESP32 DEVKIT 28x51 USER-MEASURED ENVELOPE — REMOVABLE

ACTUAL PAD-SIDE CHECK: PVIN→C1 2.58 mm; AVIN→C2 2.20 mm; C1/C2 GND→EP/PGND 3.34/2.92 mm; SW→L1 2.63 mm

PROTOTYPE TEST-POINT BANK — OUTSIDE DEVKIT ANTENNA PLACEHOLDER

FIXING-HOLE GUIDE ONLY: 8/9/10; NO CARRIER CONTACT OR NPTH

5-mm PRELIMINARY MODULE CLEARANCE — NO ROUTING

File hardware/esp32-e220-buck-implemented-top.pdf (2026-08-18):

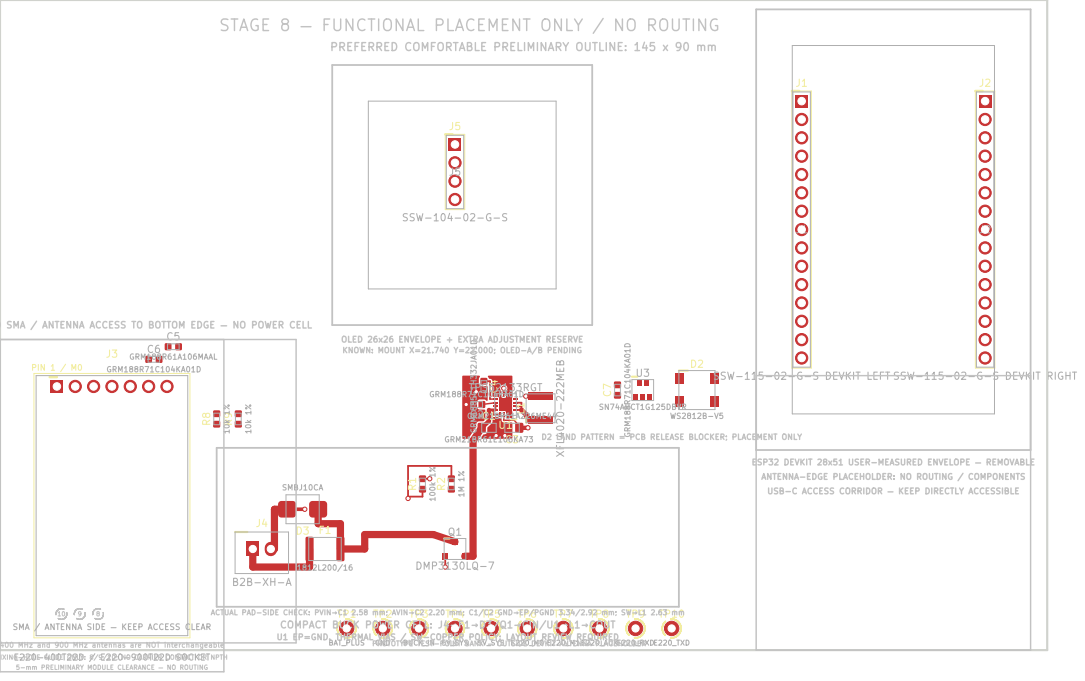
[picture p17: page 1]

PREFERRED COMFORTABLE PRELIMINARY OUTLINE: 145 x 90 mm STAGE 8 — FUNCTIONAL PLACEMENT ONLY / NO ROUTING

ANTENNA-EDGE PLACEHOLDER: NO ROUTING / COMPONENTS USB-C ACCESS CORRIDOR — KEEP DIRECTLY ACCESSIBLE E220 SMA / ANTENNA ACCESS TO BOTTOM EDGE — NO POWER CELL COMPACT BUCK POWER CELL: J4→F1→D3/Q1→CIN/U1→L1→COUT

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

KNOWN: MOUNT X=21.740 Y=22.000; OLED-A/B PENDING

ESP32 DEVKIT 28x51 USER-MEASURED ENVELOPE — REMOVABLE

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

PROTOTYPE BUCK_IN TEST-POINT BANK — OUTSIDE DEVKIT ANTENNA PLACEHOLDER

FIXING-HOLE GUIDE ONLY: 8/9/10; NO CARRIER CONTACT OR NPTH

5-mm PRELIMINARY MODULE CLEARANCE — NO ROUTING

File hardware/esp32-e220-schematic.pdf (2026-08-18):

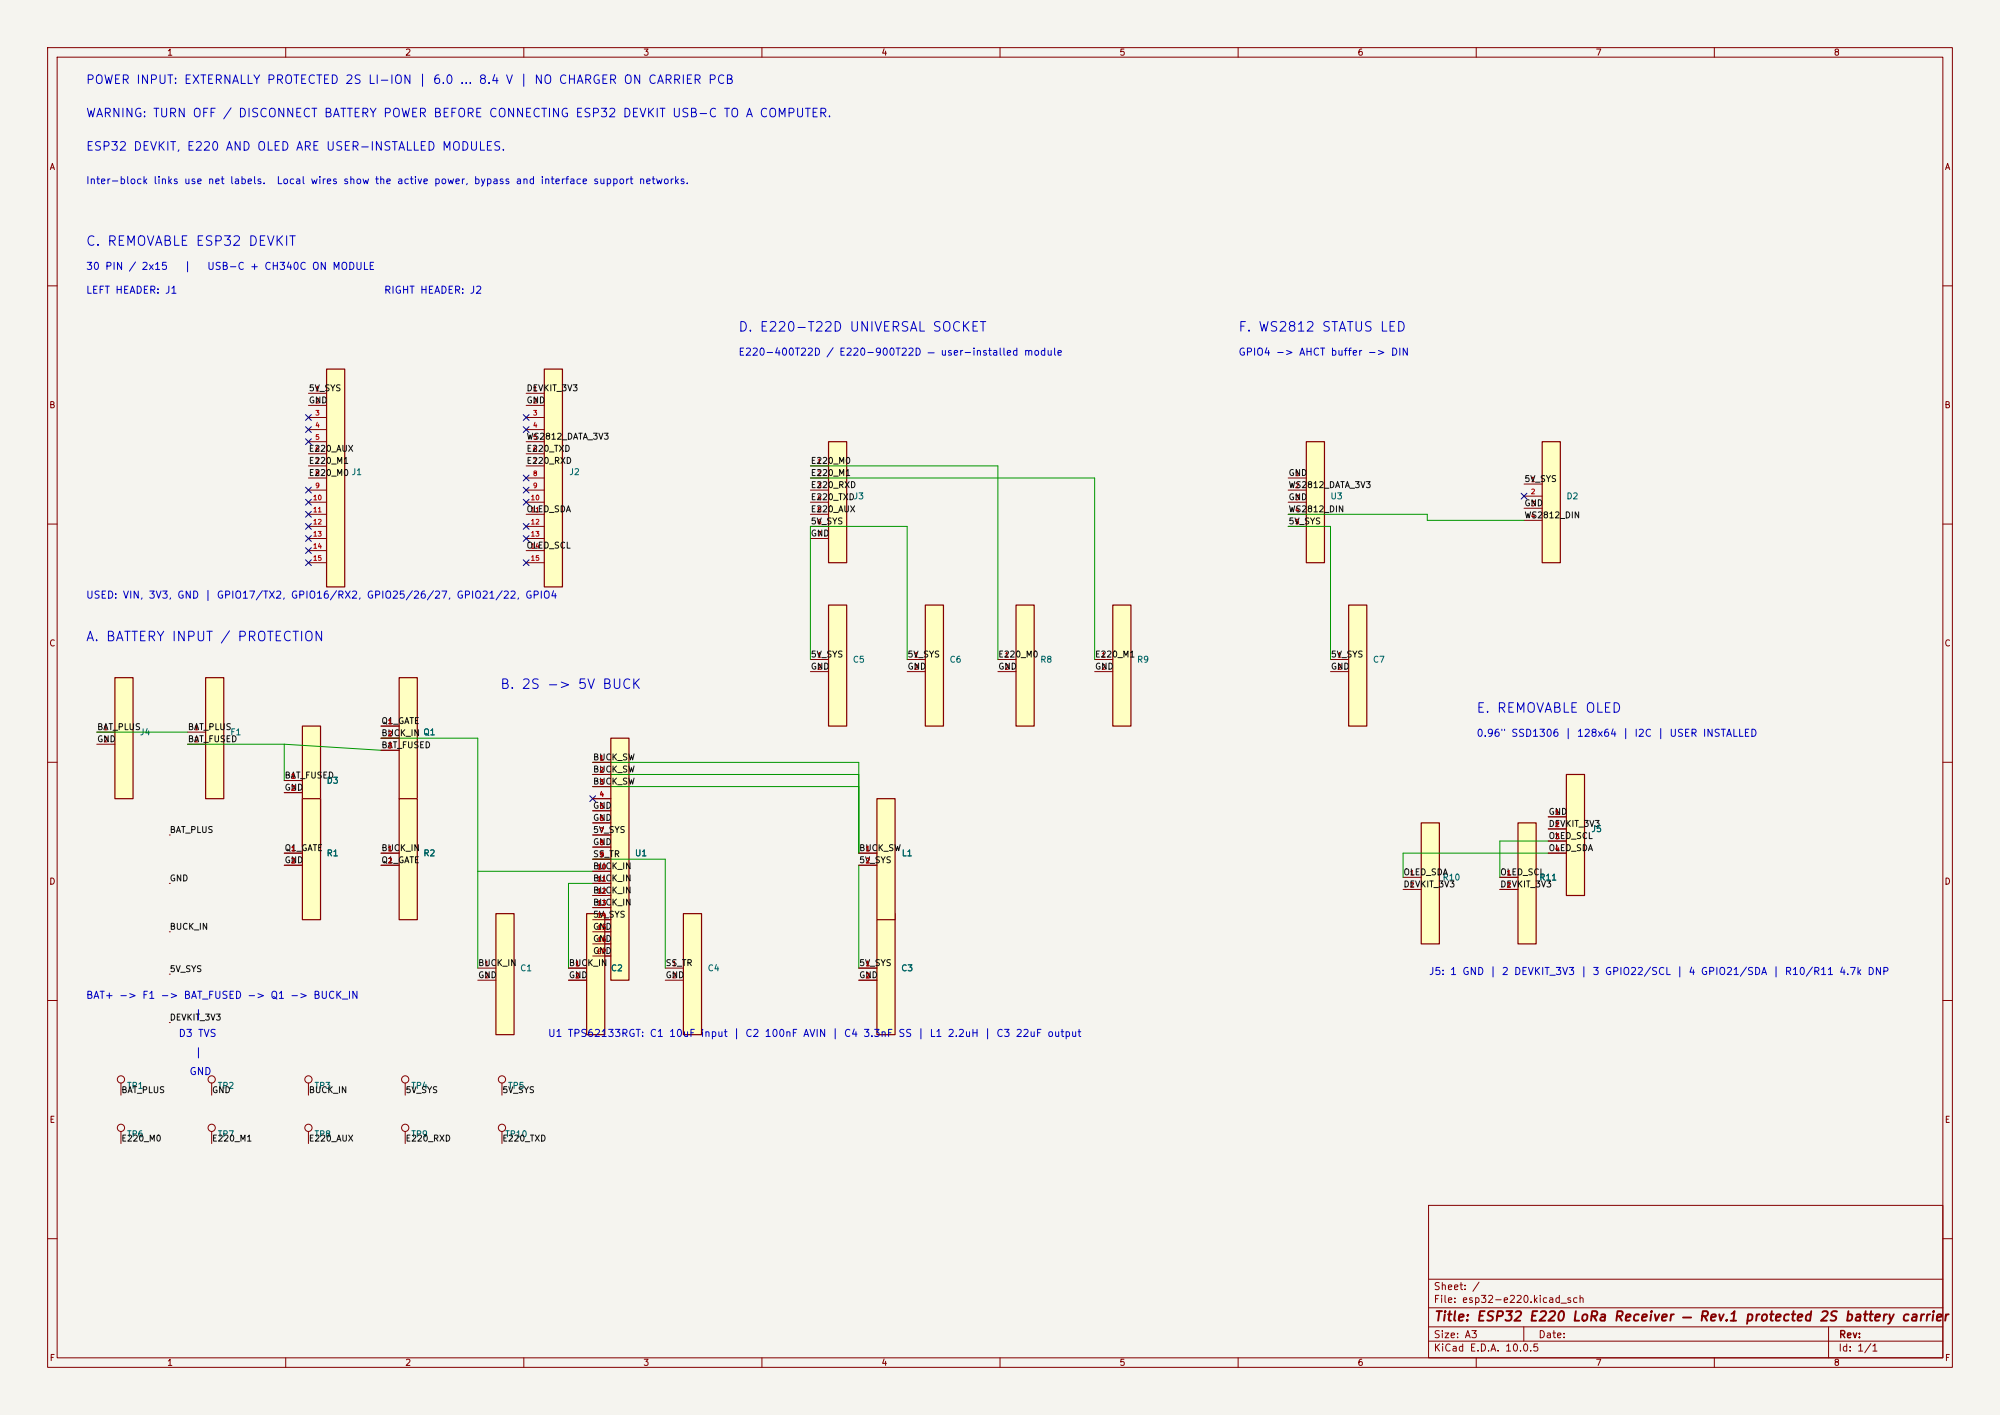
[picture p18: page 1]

POWER INPUT: EXTERNALLY PROTECTED 2S LI-ION | 6.0 ... 8.4 V | NO CHARGER ON CARRIER PCB

WARNING: TURN OFF / DISCONNECT BATTERY POWER BEFORE CONNECTING ESP32 DEVKIT USB-C TO A COMPUTER.

ESP32 DEVKIT, E220 AND OLED ARE USER-INSTALLED MODULES.

J5: 1 GND | 2 DEVKIT_3V3 | 3 GPIO22/SCL | 4 GPIO21/SDA | R10/R11 4.7k DNP

Sheet: /
File: esp32-e220.kicad_sch
Title: ESP32 E220 LoRa Receiver — Rev.1 protected 2S battery carrier

Size: A3 | Rev: | F Date:
KiCad E.D.A. 10.0.5 | Id: 1/1

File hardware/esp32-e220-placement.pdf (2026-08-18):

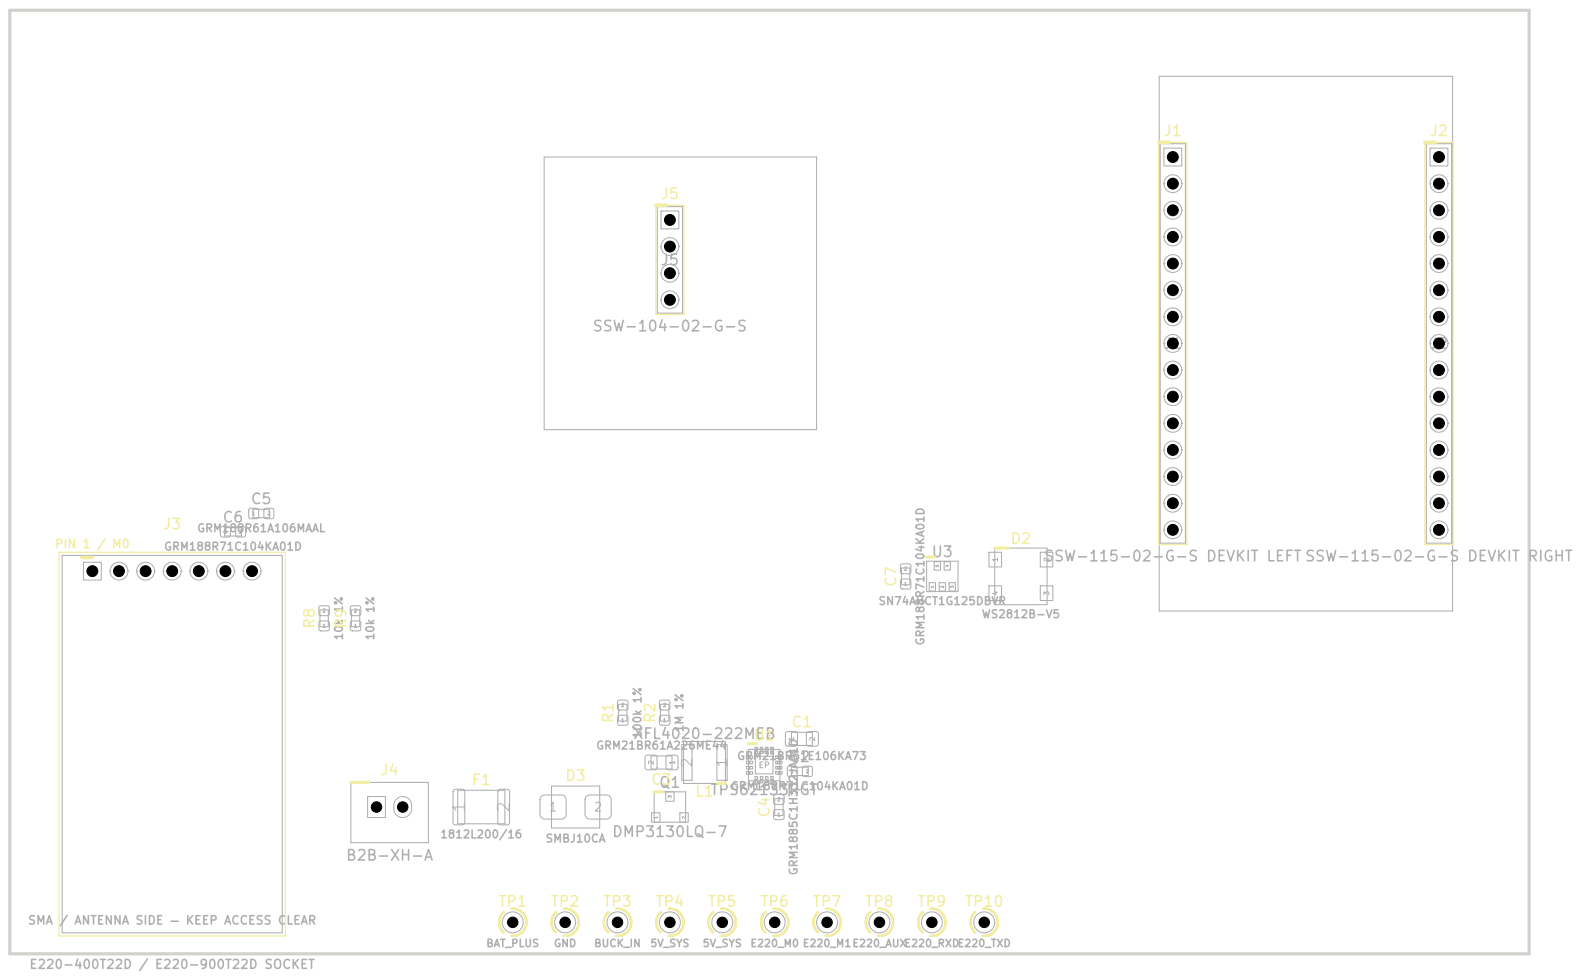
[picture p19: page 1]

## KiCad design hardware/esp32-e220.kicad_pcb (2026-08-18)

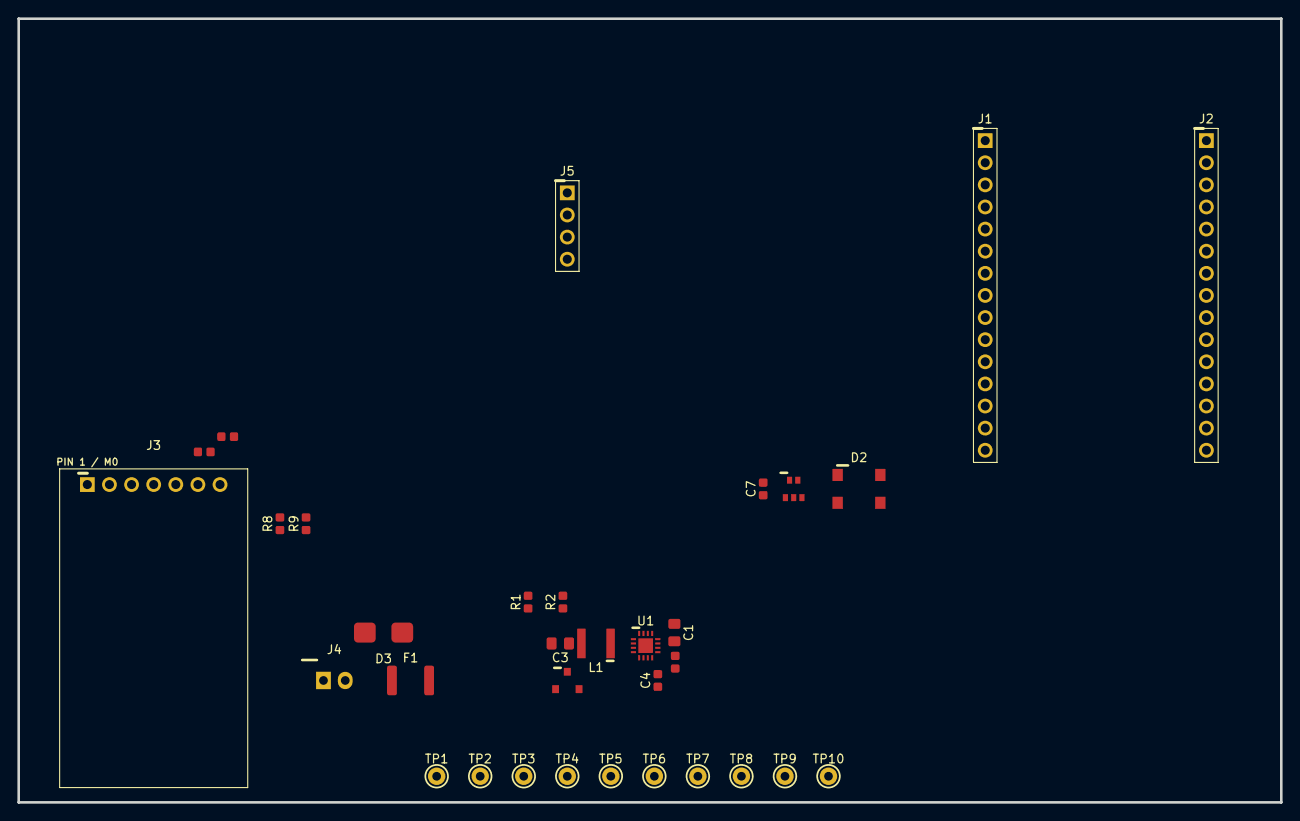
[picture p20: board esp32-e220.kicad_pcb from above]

Board: 2 copper layers, 145.0 x 90.0 mm, 33 parts (0 on the bottom side), 18 nets, no tracks yet.

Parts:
C1: GRM21BR61E106KA73; Murata_GRM21_2012Metric
C2, C6, C7: GRM188R71C104KA01D; Murata_GRM188_1608Metric
C3: GRM21BR61A226ME44; Murata_GRM21_2012Metric
C4: GRM1885C1H332JA01D; Murata_GRM188_1608Metric
C5: GRM188R61A106MAAL; Murata_GRM188_1608Metric
D2: WS2812B-V5; WorldSemi_WS2812B-V5_PLACEMENT_CANDIDATE_NOT_RELEASED
D3: SMBJ10CA; Littelfuse_SMBJ10CA_DO214AA
F1: 1812L200/16; Littelfuse_1812L200_16_4532Metric
J1: SSW-115-02-G-S DEVKIT LEFT; Samtec_SSW_1x15_P2.54mm_THT
J2: SSW-115-02-G-S DEVKIT RIGHT; Samtec_SSW_1x15_P2.54mm_THT
J3: E220-400T22D / E220-900T22D SOCKET; E220_T22D_Socket_400_900
J4: B2B-XH-A; JST_B2B-XH-A_1x02_P2.50mm_THT
J5: SSW-104-02-G-S; Samtec_SSW_1x04_P2.54mm_THT
L1: XFL4020-222MEB; Coilcraft_XFL4020-222MEB
Q1: DMP3130LQ-7; Diodes_DMP3130LQ-7_SOT23
R1: 100k 1%; Resistor_0603_1608Metric
R2: 1M 1%; Resistor_0603_1608Metric
R8, R9: 10k 1%; Resistor_0603_1608Metric
TP1: BAT_PLUS; TestPoint_THT_1p0mm_PROTOTYPE
TP2: GND; TestPoint_THT_1p0mm_PROTOTYPE
TP3: BUCK_IN; TestPoint_THT_1p0mm_PROTOTYPE
TP4, TP5: 5V_SYS; TestPoint_THT_1p0mm_PROTOTYPE
TP6: E220_M0; TestPoint_THT_1p0mm_PROTOTYPE
TP7: E220_M1; TestPoint_THT_1p0mm_PROTOTYPE
TP8: E220_AUX; TestPoint_THT_1p0mm_PROTOTYPE
TP9: E220_RXD; TestPoint_THT_1p0mm_PROTOTYPE
TP10: E220_TXD; TestPoint_THT_1p0mm_PROTOTYPE
U1: TPS62133RGT; TI_TPS62133RGT_RGT0016C
U3: SN74AHCT1G125DBVR; TI_SN74AHCT1G125DBVR_SOT23-5

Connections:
/5V_SYS: C3.1, C5.1, C6.1, C7.1, D2.1, J1.1, J3.6, L1.2, TP4.1, TP5.1, U1.7, U1.14, U3.5
/BAT_FUSED: D3.1, F1.2, Q1.3
/BAT_PLUS: F1.1, J4.1, TP1.1
/BUCK_IN: C1.1, C2.1, Q1.2, R2.1, TP3.1, U1.10, U1.11, U1.12, U1.13
/BUCK_SW: L1.1, U1.1, U1.2, U1.3
/DEVKIT_3V3: J2.1, J5.2
/E220_AUX: J1.6, J3.5, TP8.1
/E220_M0: J1.8, J3.1, R8.1, TP6.1
/E220_M1: J1.7, J3.2, R9.1, TP7.1
/E220_RXD: J2.7, J3.3, TP9.1
/E220_TXD: J2.6, J3.4, TP10.1
/GND: C1.2, C2.2, C3.2, C4.2, C5.2, C6.2, C7.2, D2.3, D3.2, J1.2, J2.2, J3.7, J4.2, J5.1, R1.2, R8.2, R9.2, TP2.1, U1.5, U1.6, U1.8, U1.15, U1.16, U1.EP, U3.1, U3.3
/OLED_SCL: J2.14, J5.3
/OLED_SDA: J2.11, J5.4
/Q1_GATE: Q1.1, R1.1, R2.2
/SS_TR: C4.1, U1.9
/WS2812_DATA_3V3: J2.5, U3.2
/WS2812_DIN: D2.4, U3.4

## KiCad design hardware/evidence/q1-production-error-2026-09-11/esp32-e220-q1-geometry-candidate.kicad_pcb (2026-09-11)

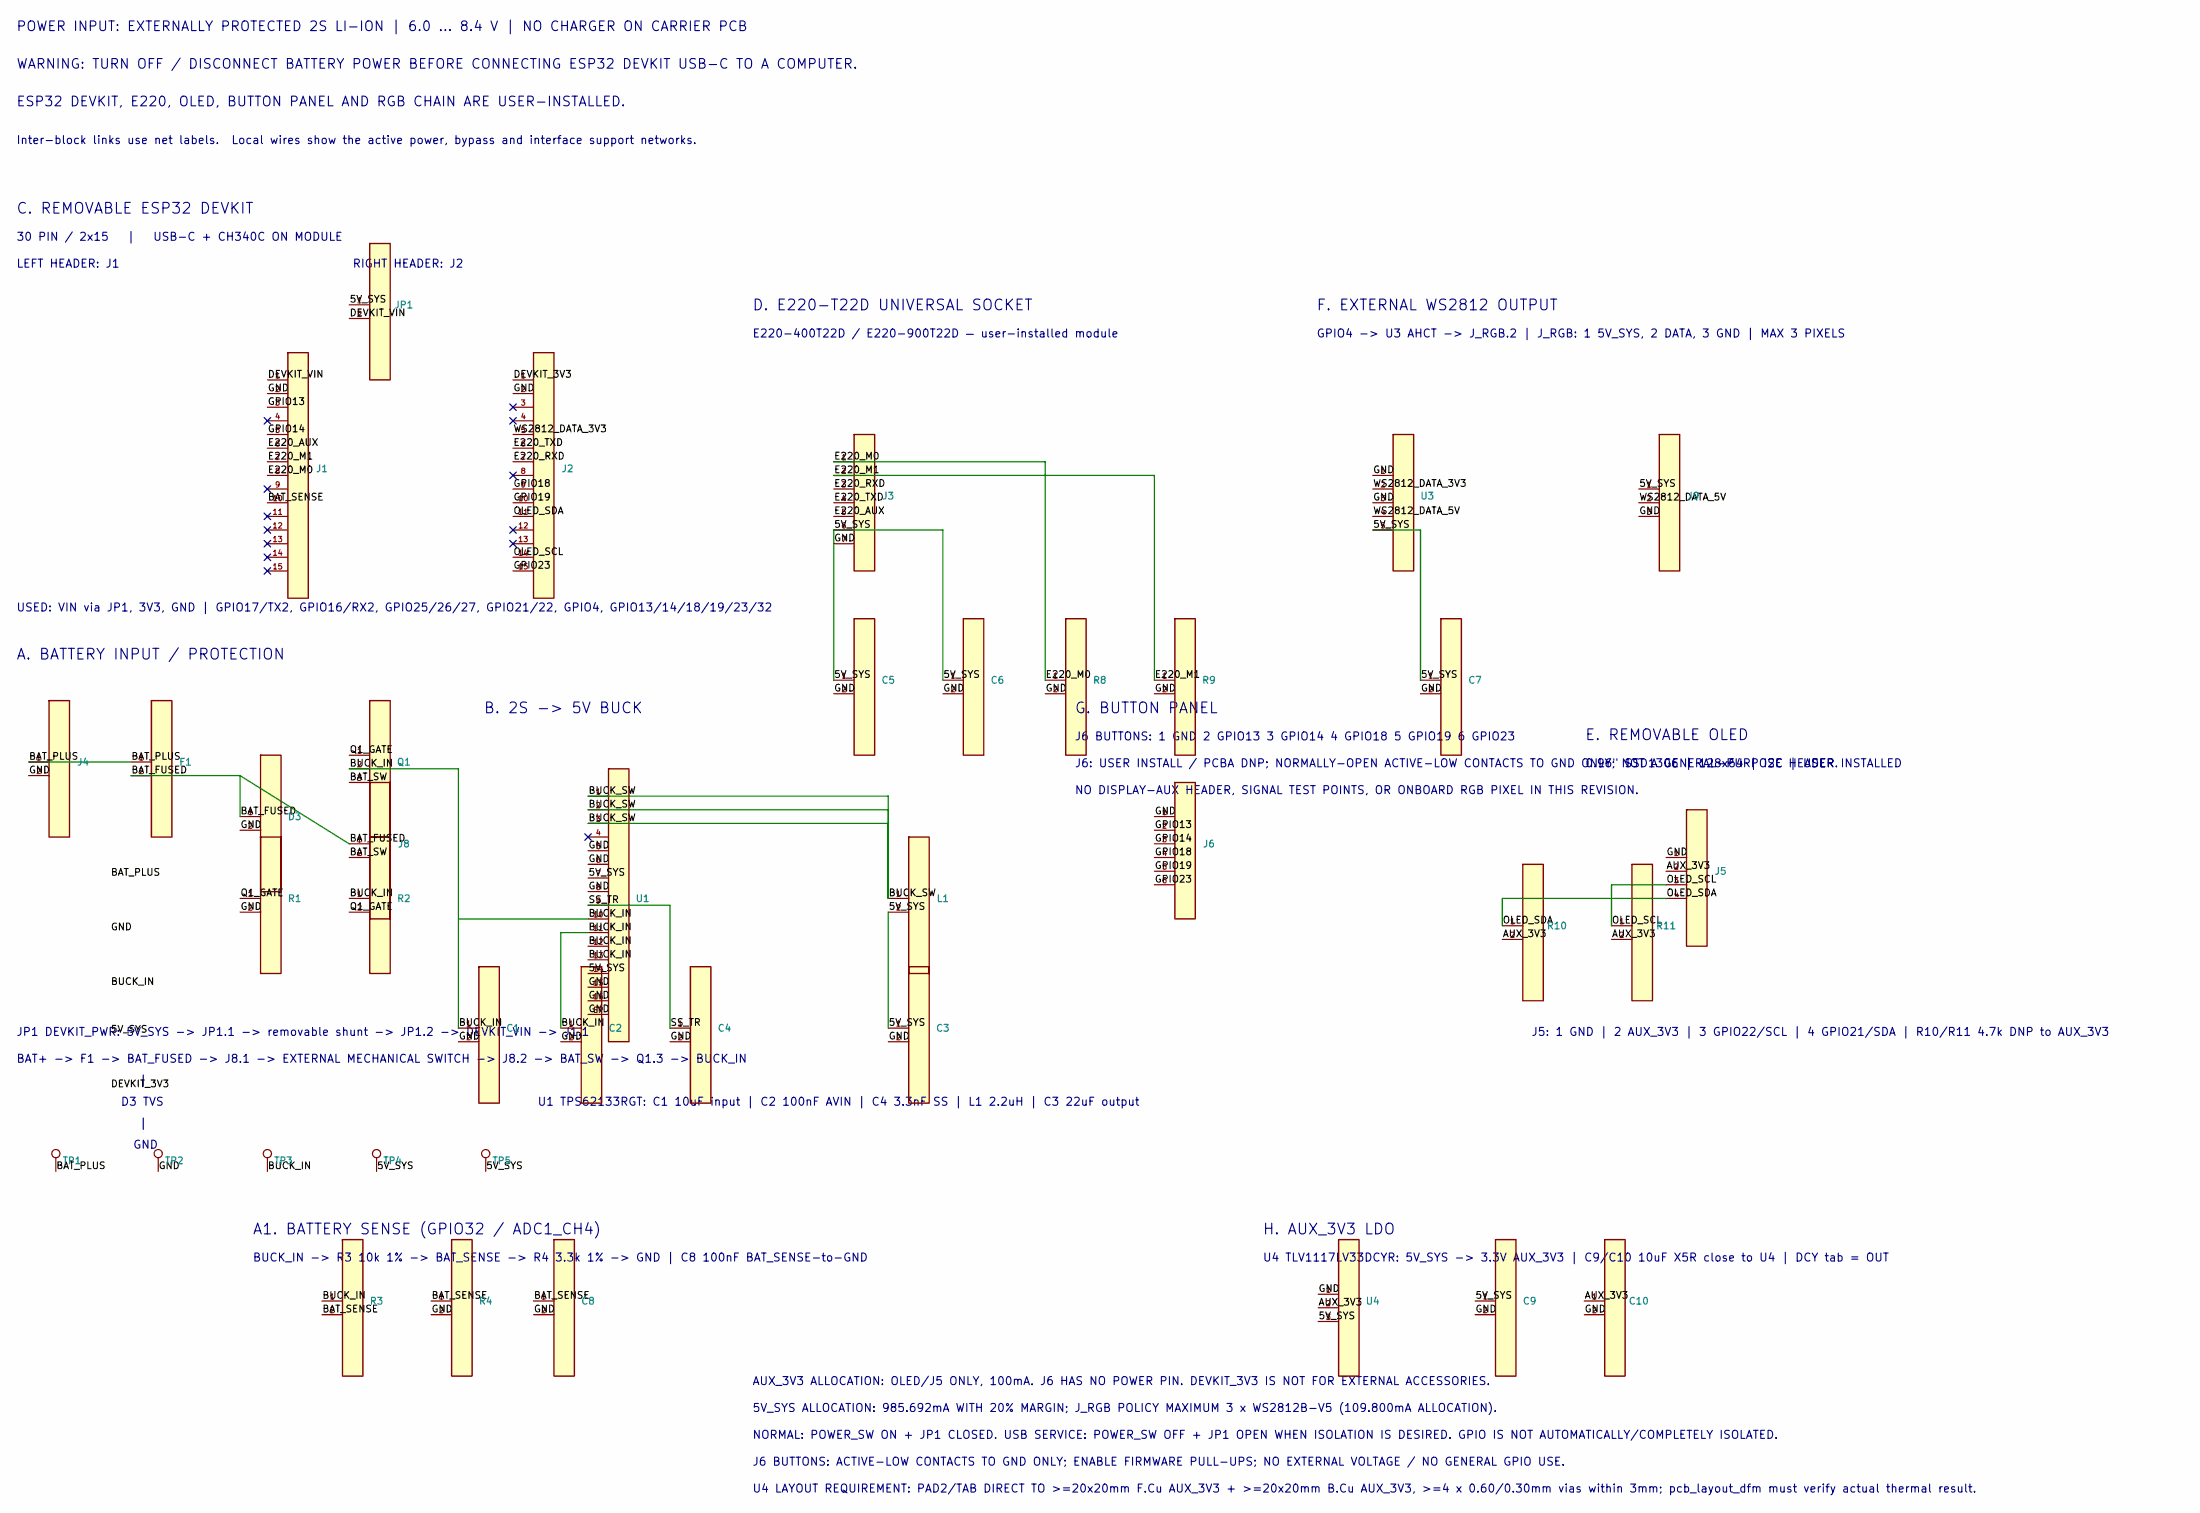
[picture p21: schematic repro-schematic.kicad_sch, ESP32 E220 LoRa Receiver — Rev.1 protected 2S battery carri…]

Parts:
C1, C9, C10: GRM21BR61E106KA73; Murata_GRM21_2012Metric
C2, C6, C7, C8: GRM188R71C104KA01D; Murata_GRM188_1608Metric
C3: GRM21BR61A226ME44; Murata_GRM21_2012Metric
C4: GRM1885C1H332JA01D; Murata_GRM188_1608Metric
C5: GRM188R61A106MAAL; Murata_GRM188_1608Metric
D3: SMBJ10CA; Littelfuse_SMBJ10CA_DO214AA
F1: 1812L200/16; Littelfuse_1812L200_16_4532Metric
J1: SSW-115-02-G-S DEVKIT LEFT; Samtec_SSW_1x15_P2.54mm_THT
J2: SSW-115-02-G-S DEVKIT RIGHT; Samtec_SSW_1x15_P2.54mm_THT
J3: E220-400T22D / E220-900T22D SOCKET; E220_T22D_Socket_400_900
J4, J8: B2B-XH-A; JST_B2B-XH-A_1x02_P2.50mm_THT
J5: SSW-104-02-G-S; Samtec_SSW_1x04_P2.54mm_THT
J6: BUTTONS 1x6 2.54mm DNP; PinHeader_1x06_P2.54mm_Vertical
J9: J_RGB / RGB OUT 1x3 2.54mm DNP; PinHeader_1x03_P2.54mm_Vertical
JP1: TSW-102-07-G-S + SNT-100-BK-G; PinHeader_1x02_P2.54mm_Vertical
L1: XFL4020-222MEB; Coilcraft_XFL4020-222MEB
Q1: DMP3130LQ-7; Diodes_DMP3130LQ-7_SOT23
R1: 100k 1%; Resistor_0603_1608Metric
R2: 1M 1%; Resistor_0603_1608Metric
R3: RC0603FR-0710KL; Resistor_0603_1608Metric
R4: RC0603FR-073K3L; Resistor_0603_1608Metric
R8, R9: 10k 1%; Resistor_0603_1608Metric
R10: DNP 4.7k 1% OLED SDA pull-up to AUX_3V3
R11: DNP 4.7k 1% OLED SCL pull-up to AUX_3V3
TP1: BAT_PLUS; TestPoint_THT_1p0mm_PROTOTYPE
TP2: GND; TestPoint_THT_1p0mm_PROTOTYPE
TP3: BUCK_IN; TestPoint_THT_1p0mm_PROTOTYPE
TP4, TP5: 5V_SYS; TestPoint_THT_1p0mm_PROTOTYPE
U1: TPS62133RGT; TI_TPS62133RGT_RGT0016C
U3: SN74AHCT1G125DBVR; TI_SN74AHCT1G125DBVR_SOT23-5
U4: TLV1117LV33DCYR; SOT-223-3_TabPin2

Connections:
/AUX_3V3: C10.1, J5.2 (VCC / 3V3), R10.2, R11.2, U4.2 (OUT / TAB)
/BAT_FUSED: D3.1 (A), F1.2, J8.1 (BAT_FUSED)
/BAT_PLUS: F1.1, J4.1 (BAT+), TP1.1
/BAT_SENSE: C8.1, J1.10 (GPIO32), R3.2, R4.1
/BAT_SW: J8.2 (BAT_SW), Q1.3 (D)
/BUCK_IN: C1.1, C2.1, Q1.2 (S), R2.1, R3.1, TP3.1, U1.10 (AVIN), U1.11 (PVIN), U1.12 (PVIN), U1.13 (EN)
/BUCK_SW: L1.1, U1.1 (SW), U1.2 (SW), U1.3 (SW)
/DEVKIT_3V3: J2.1 (3V3)
/DEVKIT_VIN: J1.1 (VIN / 5V), JP1.2 (DEVKIT_VIN)
/E220_AUX: J1.6 (GPIO27), J3.5 (AUX)
/E220_M0: J1.8 (GPIO25), J3.1 (M0), R8.1
/E220_M1: J1.7 (GPIO26), J3.2 (M1), R9.1
/E220_RXD: J2.7 (GPIO17/TX2), J3.3 (RXD)
/E220_TXD: J2.6 (GPIO16/RX2), J3.4 (TXD)
/GPIO13: J1.3 (GPIO13), J6.2 (GPIO13)
/GPIO14: J1.5 (GPIO14), J6.3 (GPIO14)
/GPIO18: J2.9 (GPIO18), J6.4 (GPIO18)
/GPIO19: J2.10 (GPIO19), J6.5 (GPIO19)
/GPIO23: J2.15 (GPIO23), J6.6 (GPIO23)
/OLED_SCL: J2.14 (GPIO22), J5.3 (SCL), R11.1
/OLED_SDA: J2.11 (GPIO21), J5.4 (SDA), R10.1
/Q1_GATE: Q1.1 (G), R1.1, R2.2
/SS_TR: C4.1, U1.9 (SS/TR)
/WS2812_DATA_3V3: J2.5 (GPIO4), U3.2 (A)
/WS2812_DATA_5V: J9.2 (WS2812_DATA_5V), U3.4 (Y)

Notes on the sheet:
A. BATTERY INPUT / PROTECTION
B. 2S -> 5V BUCK
H. AUX_3V3 LDO
U4 TLV1117LV33DCYR: 5V_SYS -> 3.3V AUX_3V3 | C9/C10 10uF X5R close to U4 | DCY tab = OUT
AUX_3V3 ALLOCATION: OLED/J5 ONLY, 100mA. J6 HAS NO POWER PIN. DEVKIT_3V3 IS NOT FOR EXTERNAL ACCESSORIES.
5V_SYS ALLOCATION: 985.692mA WITH 20% MARGIN; J_RGB POLICY MAXIMUM 3 x WS2812B-V5 (109.800mA ALLOCATION).
NORMAL: POWER_SW ON + JP1 CLOSED. USB SERVICE: POWER_SW OFF + JP1 OPEN WHEN ISOLATION IS DESIRED. GPIO IS NOT AUTOMATICALLY/COMPLETELY ISOLATED.
J6 BUTTONS: ACTIVE-LOW CONTACTS TO GND ONLY; ENABLE FIRMWARE PULL-UPS; NO EXTERNAL VOLTAGE / NO GENERAL GPIO USE.
U4 LAYOUT REQUIREMENT: PAD2/TAB DIRECT TO >=20x20mm F.Cu AUX_3V3 + >=20x20mm B.Cu AUX_3V3, >=4 x 0.60/0.30mm vias within 3mm; pcb_layout_dfm must verify actual thermal result.
A1. BATTERY SENSE (GPIO32 / ADC1_CH4)
BUCK_IN -> R3 10k 1% -> BAT_SENSE -> R4 3.3k 1% -> GND | C8 100nF BAT_SENSE-to-GND
C. REMOVABLE ESP32 DEVKIT
30 PIN / 2x15 | USB-C + CH340C ON MODULE
LEFT HEADER: J1 RIGHT HEADER: J2
USED: VIN via JP1, 3V3, GND | GPIO17/TX2, GPIO16/RX2, GPIO25/26/27, GPIO21/22, GPIO4, GPIO13/14/18/19/23/32
D. E220-T22D UNIVERSAL SOCKET
E220-400T22D / E220-900T22D — user-installed module
F. EXTERNAL WS2812 OUTPUT
GPIO4 -> U3 AHCT -> J_RGB.2 | J_RGB: 1 5V_SYS, 2 DATA, 3 GND | MAX 3 PIXELS
E. REMOVABLE OLED
0.96" SSD1306 | 128x64 | I2C | USER INSTALLED
POWER INPUT: EXTERNALLY PROTECTED 2S LI-ION | 6.0 ... 8.4 V | NO CHARGER ON CARRIER PCB
WARNING: TURN OFF / DISCONNECT BATTERY POWER BEFORE CONNECTING ESP32 DEVKIT USB-C TO A COMPUTER.
ESP32 DEVKIT, E220, OLED, BUTTON PANEL AND RGB CHAIN ARE USER-INSTALLED.
Inter-block links use net labels. Local wires show the active power, bypass and interface support networks.
G. BUTTON PANEL
J6 BUTTONS: 1 GND 2 GPIO13 3 GPIO14 4 GPIO18 5 GPIO19 6 GPIO23
J6: USER INSTALL / PCBA DNP; NORMALLY-OPEN ACTIVE-LOW CONTACTS TO GND ONLY; NOT A GENERAL-PURPOSE HEADER.
NO DISPLAY-AUX HEADER, SIGNAL TEST POINTS, OR ONBOARD RGB PIXEL IN THIS REVISION.
JP1 DEVKIT_PWR: 5V_SYS -> JP1.1 -> removable shunt -> JP1.2 -> DEVKIT_VIN -> J1.1
BAT+ -> F1 -> BAT_FUSED -> J8.1 -> EXTERNAL MECHANICAL SWITCH -> J8.2 -> BAT_SW -> Q1.3 -> BUCK_IN
D3 TVS
GND
U1 TPS62133RGT: C1 10uF input | C2 100nF AVIN | C4 3.3nF SS | L1 2.2uH | C3 22uF output
J5: 1 GND | 2 AUX_3V3 | 3 GPIO22/SCL | 4 GPIO21/SDA | R10/R11 4.7k DNP to AUX_3V3


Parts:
C1, C9, C10: GRM21BR61E106KA73; Murata_GRM21_2012Metric
C2, C6, C7, C8: GRM188R71C104KA01D; Murata_GRM188_1608Metric
C3: GRM21BR61A226ME44; Murata_GRM21_2012Metric
C4: GRM1885C1H332JA01D; Murata_GRM188_1608Metric
C5: GRM188R61A106MAAL; Murata_GRM188_1608Metric
D3: SMBJ10CA; Littelfuse_SMBJ10CA_DO214AA
F1: 1812L200/16; Littelfuse_1812L200_16_4532Metric
J1: SSW-115-02-G-S DEVKIT LEFT; Samtec_SSW_1x15_P2.54mm_THT
J2: SSW-115-02-G-S DEVKIT RIGHT; Samtec_SSW_1x15_P2.54mm_THT
J3: E220-400T22D / E220-900T22D SOCKET; E220_T22D_Socket_400_900
J4, J8: B2B-XH-A; JST_B2B-XH-A_1x02_P2.50mm_THT
J5: SSW-104-02-G-S; Samtec_SSW_1x04_P2.54mm_THT
J6: BUTTONS 1x6 2.54mm DNP; PinHeader_1x06_P2.54mm_Vertical
J9: J_RGB / RGB OUT 1x3 2.54mm DNP; PinHeader_1x03_P2.54mm_Vertical
JP1: TSW-102-07-G-S + SNT-100-BK-G; PinHeader_1x02_P2.54mm_Vertical
L1: XFL4020-222MEB; Coilcraft_XFL4020-222MEB
Q1: DMP3130LQ-7; Diodes_DMP3130LQ-7_SOT23
R1: 100k 1%; Resistor_0603_1608Metric
R2: 1M 1%; Resistor_0603_1608Metric
R3: RC0603FR-0710KL; Resistor_0603_1608Metric
R4: RC0603FR-073K3L; Resistor_0603_1608Metric
R8, R9: 10k 1%; Resistor_0603_1608Metric
R10: DNP 4.7k 1% OLED SDA pull-up to AUX_3V3
R11: DNP 4.7k 1% OLED SCL pull-up to AUX_3V3
TP1: BAT_PLUS; TestPoint_THT_1p0mm_PROTOTYPE
TP2: GND; TestPoint_THT_1p0mm_PROTOTYPE
TP3: BUCK_IN; TestPoint_THT_1p0mm_PROTOTYPE
TP4, TP5: 5V_SYS; TestPoint_THT_1p0mm_PROTOTYPE
U1: TPS62133RGT; TI_TPS62133RGT_RGT0016C
U3: SN74AHCT1G125DBVR; TI_SN74AHCT1G125DBVR_SOT23-5
U4: TLV1117LV33DCYR; SOT-223-3_TabPin2

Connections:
/AUX_3V3: C10.1, J5.2 (VCC / 3V3), R10.2, R11.2, U4.2 (OUT / TAB)
/BAT_FUSED: D3.1 (A), F1.2, J8.1 (BAT_FUSED)
/BAT_PLUS: F1.1, J4.1 (BAT+), TP1.1
/BAT_SENSE: C8.1, J1.10 (GPIO32), R3.2, R4.1
/BAT_SW: J8.2 (BAT_SW), Q1.3 (D)
/BUCK_IN: C1.1, C2.1, Q1.2 (S), R2.1, R3.1, TP3.1, U1.10 (AVIN), U1.11 (PVIN), U1.12 (PVIN), U1.13 (EN)
/BUCK_SW: L1.1, U1.1 (SW), U1.2 (SW), U1.3 (SW)
/DEVKIT_3V3: J2.1 (3V3)
/DEVKIT_VIN: J1.1 (VIN / 5V), JP1.2 (DEVKIT_VIN)
/E220_AUX: J1.6 (GPIO27), J3.5 (AUX)
/E220_M0: J1.8 (GPIO25), J3.1 (M0), R8.1
/E220_M1: J1.7 (GPIO26), J3.2 (M1), R9.1
/E220_RXD: J2.7 (GPIO17/TX2), J3.3 (RXD)
/E220_TXD: J2.6 (GPIO16/RX2), J3.4 (TXD)
/GPIO13: J1.3 (GPIO13), J6.2 (GPIO13)
/GPIO14: J1.5 (GPIO14), J6.3 (GPIO14)
/GPIO18: J2.9 (GPIO18), J6.4 (GPIO18)
/GPIO19: J2.10 (GPIO19), J6.5 (GPIO19)
/GPIO23: J2.15 (GPIO23), J6.6 (GPIO23)
/OLED_SCL: J2.14 (GPIO22), J5.3 (SCL), R11.1
/OLED_SDA: J2.11 (GPIO21), J5.4 (SDA), R10.1
/Q1_GATE: Q1.1 (G), R1.1, R2.2
/SS_TR: C4.1, U1.9 (SS/TR)
/WS2812_DATA_3V3: J2.5 (GPIO4), U3.2 (A)
/WS2812_DATA_5V: J9.2 (WS2812_DATA_5V), U3.4 (Y)

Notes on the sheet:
A. BATTERY INPUT / PROTECTION
B. 2S -> 5V BUCK
H. AUX_3V3 LDO
U4 TLV1117LV33DCYR: 5V_SYS -> 3.3V AUX_3V3 | C9/C10 10uF X5R close to U4 | DCY tab = OUT
AUX_3V3 ALLOCATION: OLED/J5 ONLY, 100mA. J6 HAS NO POWER PIN. DEVKIT_3V3 IS NOT FOR EXTERNAL ACCESSORIES.
5V_SYS ALLOCATION: 985.692mA WITH 20% MARGIN; J_RGB POLICY MAXIMUM 3 x WS2812B-V5 (109.800mA ALLOCATION).
NORMAL: POWER_SW ON + JP1 CLOSED. USB SERVICE: POWER_SW OFF + JP1 OPEN WHEN ISOLATION IS DESIRED. GPIO IS NOT AUTOMATICALLY/COMPLETELY ISOLATED.
J6 BUTTONS: ACTIVE-LOW CONTACTS TO GND ONLY; ENABLE FIRMWARE PULL-UPS; NO EXTERNAL VOLTAGE / NO GENERAL GPIO USE.
U4 LAYOUT REQUIREMENT: PAD2/TAB DIRECT TO >=20x20mm F.Cu AUX_3V3 + >=20x20mm B.Cu AUX_3V3, >=4 x 0.60/0.30mm vias within 3mm; pcb_layout_dfm must verify actual thermal result.
A1. BATTERY SENSE (GPIO32 / ADC1_CH4)
BUCK_IN -> R3 10k 1% -> BAT_SENSE -> R4 3.3k 1% -> GND | C8 100nF BAT_SENSE-to-GND
C. REMOVABLE ESP32 DEVKIT
30 PIN / 2x15 | USB-C + CH340C ON MODULE
LEFT HEADER: J1 RIGHT HEADER: J2
USED: VIN via JP1, 3V3, GND | GPIO17/TX2, GPIO16/RX2, GPIO25/26/27, GPIO21/22, GPIO4, GPIO13/14/18/19/23/32
D. E220-T22D UNIVERSAL SOCKET
E220-400T22D / E220-900T22D — user-installed module
F. EXTERNAL WS2812 OUTPUT
GPIO4 -> U3 AHCT -> J_RGB.2 | J_RGB: 1 5V_SYS, 2 DATA, 3 GND | MAX 3 PIXELS
E. REMOVABLE OLED
0.96" SSD1306 | 128x64 | I2C | USER INSTALLED
POWER INPUT: EXTERNALLY PROTECTED 2S LI-ION | 6.0 ... 8.4 V | NO CHARGER ON CARRIER PCB
WARNING: TURN OFF / DISCONNECT BATTERY POWER BEFORE CONNECTING ESP32 DEVKIT USB-C TO A COMPUTER.
ESP32 DEVKIT, E220, OLED, BUTTON PANEL AND RGB CHAIN ARE USER-INSTALLED.
Inter-block links use net labels. Local wires show the active power, bypass and interface support networks.
G. BUTTON PANEL
J6 BUTTONS: 1 GND 2 GPIO13 3 GPIO14 4 GPIO18 5 GPIO19 6 GPIO23
J6: USER INSTALL / PCBA DNP; NORMALLY-OPEN ACTIVE-LOW CONTACTS TO GND ONLY; NOT A GENERAL-PURPOSE HEADER.
NO DISPLAY-AUX HEADER, SIGNAL TEST POINTS, OR ONBOARD RGB PIXEL IN THIS REVISION.
JP1 DEVKIT_PWR: 5V_SYS -> JP1.1 -> removable shunt -> JP1.2 -> DEVKIT_VIN -> J1.1
BAT+ -> F1 -> BAT_FUSED -> J8.1 -> EXTERNAL MECHANICAL SWITCH -> J8.2 -> BAT_SW -> Q1.3 -> BUCK_IN
D3 TVS
GND
U1 TPS62133RGT: C1 10uF input | C2 100nF AVIN | C4 3.3nF SS | L1 2.2uH | C3 22uF output
J5: 1 GND | 2 AUX_3V3 | 3 GPIO22/SCL | 4 GPIO21/SDA | R10/R11 4.7k DNP to AUX_3V3

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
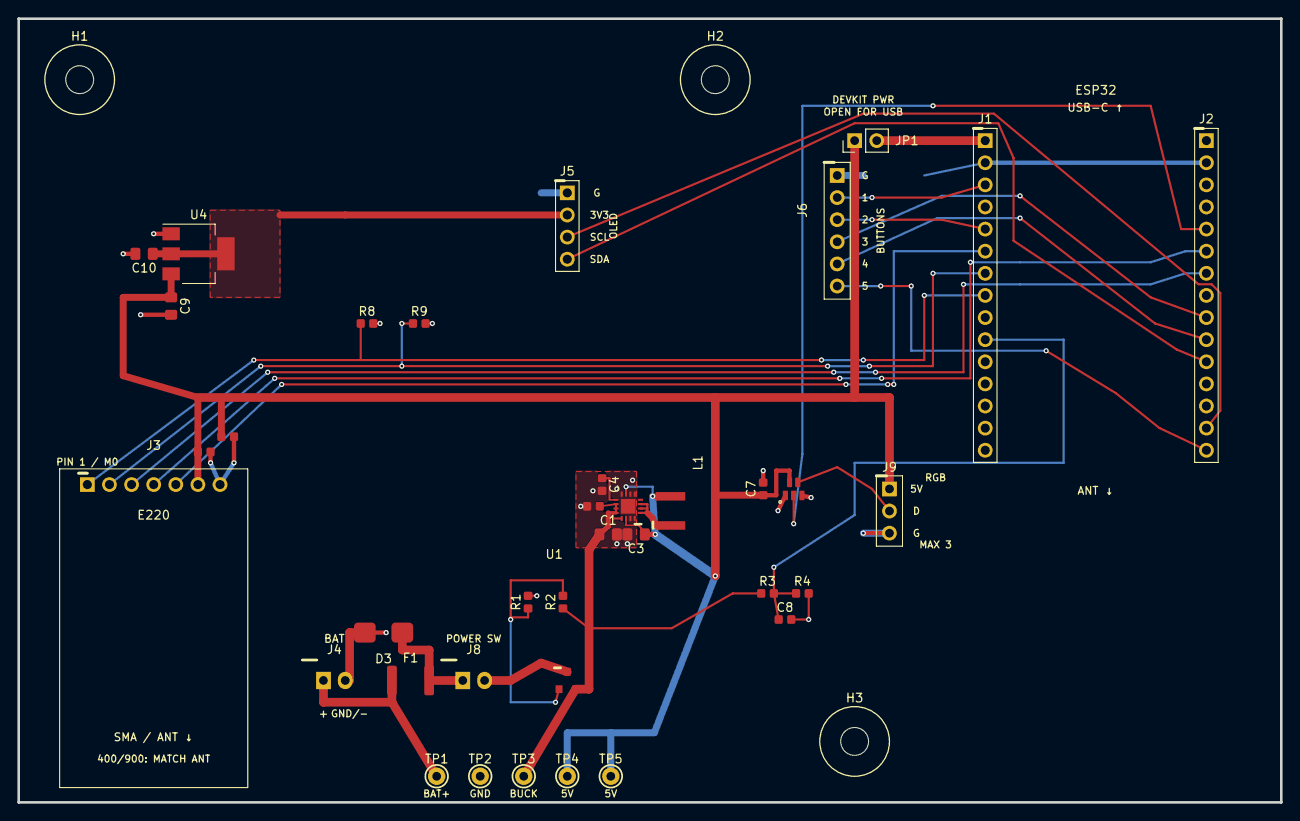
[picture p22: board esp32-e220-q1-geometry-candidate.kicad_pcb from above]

Board: 2 copper layers, 145.0 x 90.0 mm, 40 parts (0 on the bottom side), 26 nets.

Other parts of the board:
H1, H2, H3: M3 NPTH; MountingHole_M3_NPTH_REV1

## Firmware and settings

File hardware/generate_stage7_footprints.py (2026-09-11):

#!/usr/bin/env python3
"""Generate Stage 7 interface/mechanical KiCad footprints reproducibly.

No PCB is generated here.  Dimensions and release limits are documented in
docs/footprint-mechanical-review.md; this script deliberately preserves TBD
mechanical data as guide graphics rather than inventing pads or holes.
"""

from pathlib import Path


ROOT = Path(__file__).resolve().parent
LIBRARY = ROOT / "esp32-e220.pretty"
FP_TABLE = ROOT / "fp-lib-table"


def text(kind: str, value: str, x: float, y: float, layer: str, size: float = 1.0) -> str:
    return (
        f'  (fp_text {kind} "{value}" (at {x:.3f} {y:.3f}) (layer "{layer}")\n'
        f'    (effects (font (size {size:.3f} {size:.3f}) (thickness 0.15)))\n'
        "  )\n"
    )


def line(x1: float, y1: float, x2: float, y2: float, layer: str, width: float) -> str:
    return (
        f'  (fp_line (start {x1:.3f} {y1:.3f}) (end {x2:.3f} {y2:.3f}) '
        f'(stroke (width {width:.3f}) (type default)) (fill none) (layer "{layer}"))\n'
    )


def rect(x1: float, y1: float, x2: float, y2: float, layer: str, width: float) -> str:
    return "".join((
        line(x1, y1, x2, y1, layer, width),
        line(x2, y1, x2, y2, layer, width),
        line(x2, y2, x1, y2, layer, width),
        line(x1, y2, x1, y1, layer, width),
    ))


def circle(x: float, y: float, radius: float, layer: str, width: float) -> str:
    return (
        f'  (fp_circle (center {x:.3f} {y:.3f}) (end {x + radius:.3f} {y:.3f}) '
        f'(stroke (width {width:.3f}) (type dash)) (fill none) (layer "{layer}"))\n'
    )


def pad(number: str, x: float, y: float, first: bool = False) -> str:
    shape = "rect" if first else "oval"
    return (
        f'  (pad "{number}" thru_hole {shape} (at {x:.3f} {y:.3f}) '
        '(size 1.700 1.700) (drill 1.040) (layers "*.Cu" "*.Mask"))\n'
    )


def smd_pad(number: str, x: float, y: float, sx: float, sy: float,
            shape: str = "roundrect") -> str:
    """SMD land.  Dimensions must be traceable in the mechanical review."""
    extra = ' (roundrect_rratio 0.20)' if shape == "roundrect" else ""
    return (
        f'  (pad "{number}" smd {shape} (at {x:.3f} {y:.3f}) '
        f'(size {sx:.3f} {sy:.3f}) (layers "F.Cu" "F.Paste" "F.Mask"){extra})\n'
    )


def passive(name: str, description: str, body_x: float, body_y: float,
            pad_x: float, pad_y: float, pad_pitch: float) -> str:
    """Two-terminal project copy; package size comes from the named MPN."""
    return "".join((
        f'(footprint "{name}" (version 20240108) (generator "stage7")\n',
        '  (layer "F.Cu")\n',
        f'  (descr "{description}")\n',
        '  (attr smd)\n',
        text("reference", "REF**", 0, -body_y / 2 - 1.0, "F.SilkS"),
        text("value", name, 0, body_y / 2 + 1.0, "F.Fab", 0.75),
        rect(-body_x / 2, -body_y / 2, body_x / 2, body_y / 2, "F.Fab", 0.10),
        rect(-body_x / 2 - 0.5, -body_y / 2 - 0.5, body_x / 2 + 0.5, body_y / 2 + 0.5, "F.CrtYd", 0.05),
        smd_pad("1", -pad_pitch / 2, 0, pad_x, pad_y),
        smd_pad("2", pad_pitch / 2, 0, pad_x, pad_y),
        ")\n",
    ))


def tps62133() -> str:
    """TI RGT0016C example land pattern, not a copied generic VQFN."""
    items = [
        '(footprint "TI_TPS62133RGT_RGT0016C" (version 20240108) (generator "stage7")\n',
        '  (layer "F.Cu")\n',
        '  (descr "TI TPS62133RGT, RGT0016C VQFN-16 3x3 mm. TI datasheet example layout: 16x 0.60x0.24 lands, 1.68x1.68 exposed metal; optional 0.20 vias at 0.58 grid are layout-level.")\n',
        '  (attr smd)\n',
        text("reference", "U", 0, -2.85, "F.SilkS"),
        text("value", "TPS62133RGT", 0, 2.35, "F.Fab"),
        rect(-1.5, -1.5, 1.5, 1.5, "F.Fab", 0.10),
        rect(-2.0, -2.0, 2.0, 2.0, "F.CrtYd", 0.05),
        line(-1.5, -2.05, -0.75, -2.05, "F.SilkS", 0.30),
    ]
    # TI top-view numbering: 1..4 left, 5..8 bottom, 9..12 right, 13..16 top.
    # TI's RGT0016C example board drawing gives 0.600 mm in the radial
    # direction and 0.240 mm tangentially.  Its 2.800-mm reference dimension
    # places the opposite peripheral-pad centrelines at +/-1.400 mm; treating
    # it as an outside-pad extent (the prior +/-1.100-mm interpretation)
    # falsely overlaps the official 1.680-mm EP.
    for number, y in enumerate((-0.75, -0.25, 0.25, 0.75), start=1):
        items.append(smd_pad(str(number), -1.40, y, 0.60, 0.24, "rect"))
    for number, x in enumerate((-0.75, -0.25, 0.25, 0.75), start=5):
        items.append(smd_pad(str(number), x, 1.40, 0.24, 0.60, "rect"))
    for number, y in enumerate((0.75, 0.25, -0.25, -0.75), start=9):
        items.append(smd_pad(str(number), 1.40, y, 0.60, 0.24, "rect"))
    for number, x in enumerate((0.75, 0.25, -0.25, -0.75), start=13):
        items.append(smd_pad(str(number), x, -1.40, 0.24, 0.60, "rect"))
    # TI RGT0016C official stencil example: 1.55-mm EP aperture, about 85%
    # of the 1.68-mm exposed metal.  Thermal vias remain layout-level.
    items.append('  (pad "EP" smd rect (at 0 0) (size 1.680 1.680) (layers "F.Cu" "F.Mask"))\n')
    items.append('  (pad "EP" smd rect (at 0 0) (size 1.550 1.550) (layers "F.Paste"))\n')
    items.append(")\n")
    return "".join(items)


def xfl4020() -> str:
    return "".join((
        '(footprint "Coilcraft_XFL4020-222MEB" (version 20240108) (generator "stage7")\n',
        '  (layer "F.Cu")\n',
        '  (descr "Coilcraft XFL4020-222MEB. Manufacturer recommended land pattern: two 0.98x3.40 mm lands on 3.35-mm centres; dashed mark identifies pin 1/start lead.")\n',
        '  (attr smd)\n', text("reference", "L", 0, -2.75, "F.SilkS"), text("value", "XFL4020-222MEB", 0, 2.75, "F.Fab"),
        rect(-2.0, -2.0, 2.0, 2.0, "F.Fab", 0.10), rect(-2.55, -2.25, 2.55, 2.25, "F.CrtYd", 0.05),
        line(-2.0, -2.0, -1.25, -2.0, "F.SilkS", 0.30),
        smd_pad("1", -1.675, 0, 0.980, 3.400, "rect"), smd_pad("2", 1.675, 0, 0.980, 3.400, "rect"), ")\n",
    ))


def dmp3130() -> str:
    return "".join((
        '(footprint "Diodes_DMP3130LQ-7_SOT23" (version 20240108) (generator "stage7")\n',
        '  (layer "F.Cu")\n',
        '  (descr "Diodes DMP3130LQ-7 SOT23, DS38728 suggested pad layout: 0.80 x 0.90 mm lands; X1=1.35 mm is centreline to outer land edge, giving 0.95-mm lower-pad centre offsets.")\n',
        '  (attr smd)\n', text("reference", "Q", 0, -2.35, "F.SilkS"), text("value", "DMP3130LQ-7", 0, 2.35, "F.Fab"),
        rect(-0.65, -1.45, 0.65, 1.45, "F.Fab", 0.10), rect(-1.60, -1.70, 1.60, 1.70, "F.CrtYd", 0.05),
        line(-1.50, -1.45, -0.75, -1.45, "F.SilkS", 0.30),
        smd_pad("1", -0.95, 1.00, 0.80, 0.90, "rect"), smd_pad("2", 0.95, 1.00, 0.80, 0.90, "rect"), smd_pad("3", 0, -1.00, 0.80, 0.90, "rect"), ")\n",
    ))


def sn74ahct1g125() -> str:
    """Released TI DBV0005A SOT-23-5 manufacturer land pattern.

    Source: TI SN74AHCT1G125 data sheet SCLS378P, Rev. P, and package drawing
    DBV0005A 4214839/K, August 2024.  The 0.60 x 1.10-mm land pattern uses
    TI's example 0.125-mm stencil apertures and an NSMD mask expansion that is
    within the drawing's stated maximum surround.
    """
    return "".join((
        '(footprint "TI_SN74AHCT1G125DBVR_SOT23-5" (version 20240108) (generator "rev1-u3-dbv-release")\n',
        '  (layer "F.Cu")\n',
        '  (descr "TI SN74AHCT1G125DBVR, DBV0005A SOT-23-5 released land pattern; TI drawing 4214839/K, 08/2024.")\n',
        '  (attr smd)\n', text("reference", "U", 0, -2.35, "F.SilkS"), text("value", "SN74AHCT1G125DBVR", 0, 2.35, "F.Fab", 0.75),
        line(-1.500, -0.875, 1.500, -0.875, "F.Fab", 0.100),
        line(1.500, -0.875, 1.500, 0.875, "F.Fab", 0.100),
        line(1.500, 0.875, -1.000, 0.875, "F.Fab", 0.100),
        line(-1.000, 0.875, -1.500, 0.375, "F.Fab", 0.100),
        line(-1.500, 0.375, -1.500, -0.875, "F.Fab", 0.100),
        rect(-1.750, -1.800, 1.750, 1.800, "F.CrtYd", 0.050),
        '  (fp_circle (center -1.550 1.500) (end -1.400 1.500) (stroke (width 0.150) (type default)) (fill none) (layer "F.SilkS"))\n',
        '  (pad "1" smd roundrect (at -0.950 0.750) (size 0.600 1.100) (layers "F.Cu" "F.Paste" "F.Mask") (roundrect_rratio 0.166667) (solder_mask_margin 0.050))\n',
        '  (pad "2" smd roundrect (at 0.000 0.750) (size 0.600 1.100) (layers "F.Cu" "F.Paste" "F.Mask") (roundrect_rratio 0.166667) (solder_mask_margin 0.050))\n',
        '  (pad "3" smd roundrect (at 0.950 0.750) (size 0.600 1.100) (layers "F.Cu" "F.Paste" "F.Mask") (roundrect_rratio 0.166667) (solder_mask_margin 0.050))\n',
        '  (pad "4" smd roundrect (at 0.475 -0.750) (size 0.600 1.100) (layers "F.Cu" "F.Paste" "F.Mask") (roundrect_rratio 0.166667) (solder_mask_margin 0.050))\n',
        '  (pad "5" smd roundrect (at -0.475 -0.750) (size 0.600 1.100) (layers "F.Cu" "F.Paste" "F.Mask") (roundrect_rratio 0.166667) (solder_mask_margin 0.050))\n',
        ')\n',
    ))


def testpoint() -> str:
    return "".join((
        '(footprint "TestPoint_THT_1p0mm_PROTOTYPE" (version 20240108) (generator "stage8")\n',
        '  (layer "F.Cu")\n',
        '  (descr "Stage-8 prototype test point: 1.00-mm drill, 2.00-mm copper. Test-point MPN remains a procurement/DFM selection.")\n',
        '  (attr through_hole)\n', text("reference", "TP", 0, -2.0, "F.SilkS"), text("value", "TESTPOINT", 0, 2.0, "F.Fab", 0.70),
        circle(0, 0, 1.30, "F.SilkS", 0.20), circle(0, 0, 1.80, "F.CrtYd", 0.05),
        '  (pad "1" thru_hole circle (at 0 0) (size 2.000 2.000) (drill 1.000) (layers "*.Cu" "*.Mask"))\n',
        ')\n',
    ))


def jst_xh_b2b_xh_a() -> str:
    """JST B2B-XH-A: official 2.50-mm XH header geometry, project copy."""
    contents = [
        '(footprint "JST_B2B-XH-A_1x02_P2.50mm_THT" (version 20240108) (generator "stage7")\n',
        '  (layer "F.Cu")\n',
        '  (descr "JST B2B-XH-A vertical XH 2-position. JST eXH drawing: 2.50-mm pitch, 1.00-mm drilled holes; mates XHP-2/SXH-001T-P0.6.")\n',
        '  (attr through_hole)\n',
        text("reference", "J", 1.25, -3.55, "F.SilkS"), text("value", "B2B-XH-A", 1.25, 4.6, "F.Fab"),
        rect(-2.45, -2.35, 4.95, 3.40, "F.Fab", 0.10),
        rect(-2.95, -2.85, 5.45, 3.90, "F.CrtYd", 0.05),
        line(-2.45, -2.35, -0.75, -2.35, "F.SilkS", 0.30),
        '  (pad "1" thru_hole rect (at 0 0) (size 1.700 2.000) (drill 1.000) (layers "*.Cu" "*.Mask"))\n',
        '  (pad "2" thru_hole oval (at 2.500 0) (size 1.700 2.000) (drill 1.000) (layers "*.Cu" "*.Mask"))\n',
        ')\n',
    ]
    return "".join(contents)


def smbj10ca() -> str:
    # Littelfuse specifies the DO-214AA envelope. The copper lands are the
    # audited project/IPC pattern and must be validated by the assembler.
    return passive("Littelfuse_SMBJ10CA_DO214AA", "Littelfuse SMBJ10CA in DO-214AA/SMB, 4.06..4.75 x 3.30..3.94 mm official package envelope; 2.50x2.30 mm lands are project IPC nominal.", 4.60, 4.00, 2.50, 2.30, 4.30)


def fuse_1812() -> str:
    return passive("Littelfuse_1812L200_16_4532Metric", "Littelfuse 1812L200/16 PolySwitch, 1812 (4532 metric) body. 1.125x3.40 lands on 4.275-mm centres are project IPC nominal; official data confirms part family and ratings, not a release-specific PCB land pattern.", 4.50, 3.20, 1.125, 3.40, 4.275)


def header(name: str, positions: int) -> str:
    last = (positions - 1) * 2.54
    contents = [
        f'(footprint "{name}" (version 20240108) (generator "stage7")\n',
        '  (layer "F.Cu")\n',
        '  (descr "Samtec SSW through-hole socket. Official SSW-S layout: 2.54 mm pitch, 1.04 mm drill. 1.70 mm copper is a project annular-ring choice for the 0.64 mm square tail.")\n',
        '  (tags "Samtec SSW socket 2.54mm THT")\n',
        '  (attr through_hole)\n',
        text("reference", "REF**", 0, -2.5, "F.SilkS"),
        text("value", name, 0, last + 2.5, "F.Fab"),
        text("user", "${REFERENCE}", 0, last / 2, "F.Fab"),
        rect(-1.205, -1.270, 1.205, last + 1.270, "F.Fab", 0.10),
        rect(-1.350, -1.400, 1.350, last + 1.400, "F.SilkS", 0.12),
        rect(-1.850, -1.900, 1.850, last + 1.900, "F.CrtYd", 0.05),
        line(-1.350, -1.400, -0.350, -1.400, "F.SilkS", 0.35),
    ]
    contents.extend(pad(str(index + 1), 0, index * 2.54, index == 0) for index in range(positions))
    contents.append(")\n")
    return "".join(contents)


def pin_header(name: str, positions: int) -> str:
    """Generic 2.54-mm PTH user header/solder-point footprint.

    J6 and J_RGB are DNP interfaces rather than factory-fitted Samtec sockets.
    The 1.00-mm drill and 1.70-mm copper are explicit project DFM choices for
    common repairable 2.54-mm square-post headers or direct wire soldering.
    """
    last = (positions - 1) * 2.54
    contents = [
        f'(footprint "{name}" (version 20240108) (generator "stage7")\n',
        '  (layer "F.Cu")\n',
        '  (descr "Generic 2.54-mm vertical PTH header/solder points; 1.00-mm drill and 1.70-mm copper are project DFM choices. User-installed / PCBA DNP.")\n',
        '  (tags "2.54mm PTH header solder point DNP")\n',
        '  (attr through_hole)\n',
        text("reference", "J", 0, -2.50, "F.SilkS"),
        text("value", name, 0, last + 2.50, "F.Fab", 0.75),
        rect(-1.27, -1.27, 1.27, last + 1.27, "F.Fab", 0.10),
        rect(-1.50, -1.50, 1.50, last + 1.50, "F.SilkS", 0.12),
        rect(-1.85, -1.85, 1.85, last + 1.85, "F.CrtYd", 0.05),
        line(-1.50, -1.50, -0.35, -1.50, "F.SilkS", 0.35),
    ]
    for index in range(positions):
        shape = "rect" if index == 0 else "oval"
        contents.append(
            f'  (pad "{index + 1}" thru_hole {shape} (at 0 {index * 2.54:.3f}) '
            '(size 1.700 1.700) (drill 1.000) (layers "*.Cu" "*.Mask"))\n'
        )
    contents.append(")\n")
    return "".join(contents)


def esp32_template() -> str:
    # Only the rows are datum-verified.  The body is intentionally unregistered
    # to the headers.  Rev.1 permits it for *conservative preliminary placement*
    # only: no routing/copper shall occupy its body, USB-access or antenna-end
    # placeholder clearance until a final module-specific drawing is available.
    last = 14 * 2.54
    contents = [
        '(footprint "ESP32_DevKit_30pin_Socket_2x15_MechanicalTemplate" (version 20240108) (generator "stage7")\n',
        '  (layer "F.Cu")\n',
        '  (descr "ESP32 DevKit 2x1x15 socket mechanical template. Only socket rows are verified; 28x51 body envelope is user-measured and not registered to header datum.")\n',
        '  (tags "ESP32 DevKit 30 pin mechanical template USER-MEASURED")\n',
        '  (attr through_hole)\n',
        text("reference", "MECH**", 12.7, -3.0, "F.SilkS"),
        text("value", "ESP32 DevKit 30-pin mechanical template", 12.7, last + 3.0, "F.Fab"),
        text("user", "USB-C END / PIN 1", 12.7, -1.6, "F.SilkS", 0.85),
        text("user", "ANTENNA END — CONSERVATIVE NO ROUTING / NO COMPONENTS", 12.7, last + 1.6, "F.Fab", 0.80),
        text("user", "BODY 28 x 51 USER-MEASURED — PRELIMINARY ENVELOPE ONLY", 12.7, last / 2, "Dwgs.User", 0.75),
        rect(-1.350, -1.400, 26.750, last + 1.400, "F.CrtYd", 0.05),
        line(-1.350, -1.400, -0.300, -1.400, "F.SilkS", 0.35),
        line(24.350, -1.400, 25.400, -1.400, "F.SilkS", 0.35),
    ]
    # Illustrative, explicitly unregistered body and a 5-mm preliminary clearance
    # guide: acceptable for Stage 7 mechanical planning, never a release datum.
    contents.append(rect(-1.300, -7.720, 26.700, 43.280, "Dwgs.User", 0.20))
    contents.append(rect(-6.300, -12.720, 31.700, 48.280, "Dwgs.User", 0.20))
    for index in range(15):
        y = index * 2.54
        contents.append(pad(f"L{index + 1}", 0, y, index == 0))
        contents.append(pad(f"R{index + 1}", 25.4, y, index == 0))
    contents.append(")\n")
    return "".join(contents)


def e220_socket() -> str:
    # EBYTE common 400/900T22D geometry uses the pin-row short edge as Y=0.
    # The official E220-T manual establishes the seven electrical pads and the
    # three *mechanical* fixing-hole sites.  They are intentionally guide-only:
    # this removable-module carrier must not turn the module's non-electrical
    # fixing holes into carrier contacts or NPTH without a mounting decision.
    contents = [
        '(footprint "E220_T22D_Socket_400_900" (version 20240108) (generator "stage7")\n',
        '  (layer "F.Cu")\n',
        '  (descr "Carrier-side 1x7 Samtec SSW socket for common EBYTE E220-400T22D / E220-900T22D geometry; not EBYTE solder-pad pattern")\n',
        '  (tags "EBYTE E220 400T22D 900T22D socket 2.54mm")\n',
        '  (attr through_hole)\n',
        text("reference", "J_E220", 10.5, -3.0, "F.SilkS"),
        text("value", "E220-400T22D / E220-900T22D SOCKET", 10.5, 39.0, "F.Fab", 0.85),
        text("user", "PIN 1 / M0", 2.88, -1.1, "F.SilkS", 0.80),
        text("user", "SMA / ANTENNA SIDE — KEEP ACCESS CLEAR", 10.5, 34.8, "F.Fab", 0.80),
        text("user", "400 MHz and 900 MHz antennas are NOT interchangeable", 10.5, 37.3, "Dwgs.User", 0.70),
        text("user", "5-mm PRELIMINARY MODULE CLEARANCE — NO ROUTING", 10.5, 40.4, "Dwgs.User", 0.62),
        text("user", "FIXING-HOLE GUIDE ONLY: 8/9/10; NO CARRIER CONTACT OR NPTH", 10.5, 39.0, "Dwgs.User", 0.62),
        rect(0, 0, 21.0, 36.0, "F.Fab", 0.10),
        rect(-1.0, -1.0, 22.0, 37.0, "F.CrtYd", 0.05),
        rect(-0.3, -0.3, 21.3, 36.3, "F.SilkS", 0.12),
        rect(-5.0, -5.0, 26.0, 41.0, "Dwgs.User", 0.20),
        line(1.88, 0.2, 2.88, 0.2, "F.SilkS", 0.35),
    ]
    for index in range(7):
        contents.append(pad(str(index + 1), 2.88 + index * 2.54, 1.50, index == 0))
    # Manual front-view coordinates, transformed to this footprint datum:
    # holes 10/9/8 at X=3.50/6.04/8.58 mm and 3.00 mm from the SMA-side edge,
    # hence Y=36.00-3.00=33.00 mm.  They are visibility/clearance guides only.
    for number, x in (("10", 3.50), ("9", 6.04), ("8", 8.58)):
        contents.append(circle(x, 33.00, 0.75, "Dwgs.User", 0.15))
        contents.append(text("user", number, x, 33.00, "Dwgs.User", 0.60))
    contents.append(")\n")
    return "".join(contents)


def oled_template() -> str:
    # The user drawing supplies the body, mounting-hole spacing and *horizontal*
    # GND-pin datum.  It does not provide header-row Y or finished hole diameter;
    # do not turn this template into a placement datum or an NPTH pattern.
    contents = [
        '(footprint "OLED_0p96_4pin_MechanicalTemplate_PENDING_DATUM" (version 20240108) (generator "stage7")\n',
        '  (layer "F.Cu")\n',
        '  (descr "0.96in SSD1306 I2C OLED template. Body 26x26; mount spacing 21.740x22.000; GND header X=9.190 mm from left edge. Header Y and hole diameter TBD.")\n',
        '  (tags "OLED SSD1306 0.96 4pin mechanical template PENDING DATUM")\n',
        '  (attr through_hole)\n',
        text("reference", "MECH**", 13.0, -3.0, "F.SilkS"),
        text("value", "OLED 0.96in mechanical template — NOT PRODUCTION APPROVED", 13.0, 29.0, "F.Fab", 0.80),
        text("user", "BODY 26.000 x 26.000 USER/SUPPLIER DRAWING", 13.0, 13.0, "Dwgs.User", 0.75),
        text("user", "MOUNT-SPACING GUIDE (unregistered): X=21.740, Y=22.000; HOLE DIA TBD", 13.0, 15.0, "Dwgs.User", 0.70),
        text("user", "HEADER X: GND=9.190, VCC=11.730, SCL=14.270, SDA=16.810; Y TBD", 13.0, 17.0, "Dwgs.User", 0.60),
        text("user", "DISPLAY / FLEX / NOTCH: TBD", 13.0, 18.5, "Dwgs.User", 0.70),
        text("user", "5-mm PRELIMINARY MODULE CLEARANCE — NO ROUTING", 13.0, 20.0, "Dwgs.User", 0.62),
        rect(0, 0, 26.0, 26.0, "F.Fab", 0.10),
        rect(-1.0, -1.0, 27.0, 27.0, "F.CrtYd", 0.05),
        rect(-5.0, -5.0, 31.0, 31.0, "Dwgs.User", 0.20),
    ]
    # The source supplies only the spacing, not either hole-to-board-edge datum.
    # These are therefore coordinates in an independent *hole-spacing guide*,
    # not locations on the 26 x 26 mm body outline above.
    for x in (35.0, 56.74):
        for y in (0.0, 22.0):
            contents.append(circle(x, y, 1.0, "Dwgs.User", 0.15))
    # This four-pad row is an interface guide only.  Its body registration is
    # incomplete until the header Y datum is known.  The *actual* carrier
    # socket is the separate Samtec SSW-104 footprint.
    contents.extend((
        text("user", "INTERFACE ONLY: 1 GND  2 VCC  3 SCL  4 SDA", 3.81, -1.4, "F.Fab", 0.80),
        pad("1", 0, 0, True),
        pad("2", 2.54, 0),
        pad("3", 5.08, 0),
        pad("4", 7.62, 0),
        ")\n",
    ))
    return "".join(contents)


def mounting_hole_m3_npth() -> str:
    """Rev.1 enclosure mounting hole: 3.20-mm NPTH, no copper pad.

    The separate layout-level 8.00-mm F.Cu/B.Cu keepout is intentionally not
    embedded in the footprint so it is machine-visible as a named rule area.
    """
    return "".join((
        '(footprint "MountingHole_M3_NPTH_REV1" (version 20240108) (generator "rev1-final-mechanical-serviceability")\n',
        '  (layer "F.Cu")\n',
        '  (descr "Rev.1 mechanical mounting hole: 3.20 mm NPTH, M3, 8.00 mm screw-head courtyard")\n',
        '  (attr through_hole exclude_from_pos_files exclude_from_bom)\n',
        text("reference", "H", 0, -5.000, "F.SilkS"),
        '  (fp_text value "M3 NPTH" (at 0 5.000) (layer "F.Fab") hide\n'
        '    (effects (font (size 1.000 1.000) (thickness 0.150))))\n',
        '  (fp_circle (center 0 0) (end 4.000 0) (stroke (width 0.150) (type default)) (fill none) (layer "F.SilkS"))\n',
        '  (fp_circle (center 0 0) (end 1.600 0) (stroke (width 0.100) (type default)) (fill none) (layer "F.Fab"))\n',
        '  (fp_circle (center 0 0) (end 4.000 0) (stroke (width 0.050) (type default)) (fill none) (layer "F.CrtYd"))\n',
        '  (pad "" np_thru_hole circle (at 0 0) (size 3.200 3.200) (drill 3.200) (layers "*.Cu" "*.Mask"))\n',
        ')\n',
    ))
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

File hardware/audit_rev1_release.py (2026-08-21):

#!/usr/bin/env python3
"""Read generated Rev.1 package, create release manifest and checksum audit."""
import argparse
import csv
import hashlib
import json
import re
from datetime import datetime, timezone
from pathlib import Path
import sys

HERE = Path(__file__).resolve().parent
sys.path.insert(0, str(HERE))
import check_schematic_pcb_sync as sync

EXPECTED_FAB = {
    "esp32-e220-F_Cu.gtl", "esp32-e220-B_Cu.gbl",
    "esp32-e220-F_Mask.gts", "esp32-e220-B_Mask.gbs",
    "esp32-e220-F_Silkscreen.gto", "esp32-e220-Edge_Cuts.gm1",
    "esp32-e220-PTH.drl", "esp32-e220-NPTH.drl", "esp32-e220-job.gbrjob",
    "ESP32-E220-Carrier-Rev1.ipc356", "DRILL_REPORT.txt",
}
EXPECTED_DNP = {
    "DNP_USER": {"J6", "J9"},
    "PLATED_TEST_HOLE": {"TP1", "TP2", "TP3", "TP4", "TP5"},
    "NO_FOOTPRINT_DNP": {"R10", "R11"},
    "USER_INSTALLED_MODULE": {"ESP32_DEVKIT", "E220_T22D", "OLED_0P96"},
    "MANUAL_ACCESSORY": {"JP1_SHUNT"},
    "MECHANICAL_NPTH": {"H1", "H2", "H3"},
}

def sha(path):
    return hashlib.sha256(path.read_bytes()).hexdigest()

def main():
    parser = argparse.ArgumentParser()
    parser.add_argument("--release", type=Path, required=True)
    parser.add_argument("--expected-pcb-sha", required=True)
    parser.add_argument("--expected-sch-sha", required=True)
    parser.add_argument("--metadata-sha", required=True)
    args = parser.parse_args()
    release = args.release
    fabrication, assembly, docs, checksums = (release / name for name in ("fabrication", "assembly", "documentation", "checksums"))
    errors = []
    pcb, sch = HERE / "esp32-e220.kicad_pcb", HERE / "esp32-e220.kicad_sch"
    pcb_sha, sch_sha, meta_sha = sha(pcb), sha(sch), sha(HERE / "production-metadata.json")
    if pcb_sha != args.expected_pcb_sha: errors.append("PCB source hash changed")
    if sch_sha != args.expected_sch_sha: errors.append("schematic source hash changed")
    if meta_sha != args.metadata_sha: errors.append("production metadata hash changed")

    fabric_files = {path.name for path in fabrication.iterdir() if path.is_file()}
    if fabric_files != EXPECTED_FAB:
        errors.append(f"fabrication file set mismatch: {sorted(fabric_files ^ EXPECTED_FAB)}")
    layer_headers = {
        "esp32-e220-F_Cu.gtl": "FileFunction,Copper,L1,Top",
        "esp32-e220-B_Cu.gbl": "FileFunction,Copper,L2,Bot",
        "esp32-e220-F_Mask.gts": "FileFunction,Soldermask,Top",
        "esp32-e220-B_Mask.gbs": "FileFunction,Soldermask,Bot",
        "esp32-e220-F_Silkscreen.gto": "FileFunction,Legend,Top",
        "esp32-e220-Edge_Cuts.gm1": "FileFunction,Profile,NP",
    }
    for name, marker in layer_headers.items():
        text = (fabrication / name).read_text()
        if marker not in text or "GenerationSoftware,KiCad,Pcbnew,10.0.5" not in text:
            errors.append(f"{name} has incorrect X2/header identity")
    edge = (fabrication / "esp32-e220-Edge_Cuts.gm1").read_text()
    points = {(int(x), int(y)) for x, y in re.findall(r"X(-?\d+)Y(-?\d+)D0[123]", edge)}
    expected_points = {(0,0), (145000000,0), (145000000,-90000000), (0,-90000000)}
    if points != expected_points or edge.count("D01*") != 4:
        errors.append("generated Edge.Cuts is not one closed 145 x 90 mm outline")
    if "ESP32_ANTENNA_EXCLUSION" in (fabrication / "esp32-e220-F_Cu.gtl").read_text():
        errors.append("unexpected antenna rule text in copper Gerber")
    bcu = (fabrication / "esp32-e220-B_Cu.gbl").read_text()
    service_markers = {
        "J6 branch": ("X94000000Y-18000000D02*", "X97000000Y-18000000D01*"),
        "J9 branch": ("X100000000Y-59080000D02*", "X97000000Y-59080000D01*"),
    }
    service_status = {name: all(marker in bcu for marker in markers)
                      for name, markers in service_markers.items()}
    if pcb_sha.startswith("9f15f061") and not all(service_status.values()):
        errors.append("B.Cu Gerber lacks required J6/J9 explicit ground branches")
    if pcb_sha.startswith("dd4d77d5") and not all(marker in bcu for marker in ("X63000000Y-20000000D02*", "X60000000Y-20000000D01*")):
        errors.append("B.Cu Gerber lacks required J5 explicit ground branch")

    drill = (fabrication / "DRILL_REPORT.txt").read_text()
    pth = re.search(r"Total plated holes count (\d+)", drill)
    npth = re.search(r"Total unplated holes count (\d+)", drill)
    if not pth or pth.group(1) != "119": errors.append("PTH drill count is not 119")
    expected_npth = "3" if pcb_sha.startswith("dd4d77d5") else "0"
    if not npth or npth.group(1) != expected_npth: errors.append("NPTH drill count mismatch")
    if "METRIC" not in (fabrication / "esp32-e220-PTH.drl").read_text() or "decimal" not in (fabrication / "esp32-e220-PTH.drl").read_text():
        errors.append("PTH Excellon format is not metric decimal")

    metadata = json.loads((HERE / "production-metadata.json").read_text())["assembly_classes"]
    pcba_refs = set(metadata["PCBA_POPULATE"])
    with (assembly / "BOM_REV1.csv").open(newline="") as stream:
        bom = list(csv.DictReader(stream))
    bom_refs = {ref.strip() for row in bom for ref in row["References"].split(",") if ref.strip()}
    if bom_refs != pcba_refs or sum(int(row["Qty"]) for row in bom) != 30:
        errors.append("BOM does not represent exactly 30 PCBA refs")
    forbidden = set().union(*EXPECTED_DNP.values())
    if bom_refs & forbidden: errors.append("BOM contains non-PCBA item")

    with (assembly / "CPL_SMD_REV1.csv").open(newline="") as stream:
        cpl = list(csv.DictReader(stream))
    board_data = sync.board()
    smd_refs = set()
    tht_refs = set()
    for ref in pcba_refs:
        raw = next(fp for fp in sync.forms(sync.sexp((HERE / "esp32-e220.kicad_pcb").read_text()), "footprint") if sync.prop_map(fp).get("Reference") == ref)
        is_tht = any(len(pad) > 2 and pad[2] == "thru_hole" for pad in sync.forms(raw, "pad"))
        (tht_refs if is_tht else smd_refs).add(ref)
    if {row["Designator"] for row in cpl} != smd_refs or len(cpl) != 23:
        errors.append("CPL does not exactly represent SMT PCBA refs")
    with (assembly / "THT_ASSEMBLY.csv").open(newline="") as stream:
        tht = list(csv.DictReader(stream))
    if {row["Reference"] for row in tht} != tht_refs or len(tht) != 7:
        errors.append("THT manifest does not exactly represent THT PCBA refs")

    with (assembly / "DNP_USER_MANIFEST.csv").open(newline="") as stream:
        dnp_rows = list(csv.DictReader(stream))
    dnp_by_class = {}
    for row in dnp_rows: dnp_by_class.setdefault(row["Class"], set()).add(row["Reference/Identifier"])
    if dnp_by_class != EXPECTED_DNP:
        errors.append("DNP/user manifest mismatch")

    timestamp = datetime.now(timezone.utc).replace(microsecond=0).isoformat()
    release_manifest = f"""# Rev.1 release manifest
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

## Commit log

2026-08-18 next commit
    [esp32-e220.kicad_sch]
2026-08-21 Финиш перед изготовлением
    [00-active-baseline-9f15f061.kicad_pcb, 00-active-baseline.kicad_pcb, 00-released-baseline.kicad_pcb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]
2026-08-25 Второй пост
2026-08-25 Добавил эксель с рачётами
    [PCBWAVE PCBA Quote for 4pcs ESP32-E220-Carrier-Rev1 2026.8.25 updated.xlsx]
2026-09-11 Fix stale Stage8 Q1 BAT_SW mapping
    [12-regenerated-stage8-before-stage7.kicad_pcb, 17-regenerated-stage8-after-stage7.kicad_pcb, BOM_REV1.csv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]
